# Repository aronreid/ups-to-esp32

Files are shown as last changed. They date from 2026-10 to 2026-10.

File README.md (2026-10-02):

# UPS to ESP32 Module Canadian flag





**Put a USB-only UPS on your network for the cost of a $6 board: no Pi, no SD card to
corrupt, no vendor network card that costs more than the UPS.**

Plug it into your UPS's USB port and it speaks the real Network UPS Tools protocol on
TCP 3493, so Home Assistant, Synology, TrueNAS, unraid and `upsmon` see a normal `upsd`
and connect exactly like they would to one, because it *is* one, not an approximation.

<p align="center">
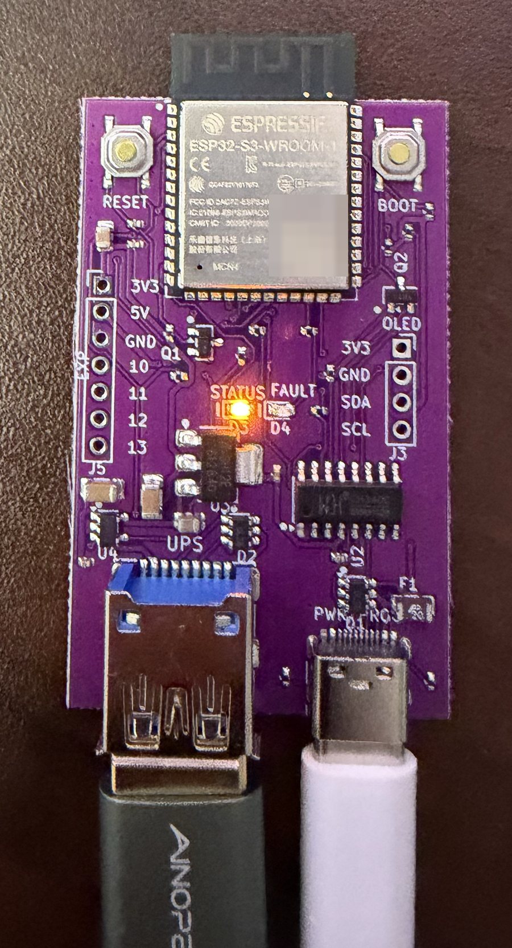
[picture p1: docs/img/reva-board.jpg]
A Rev A board, powered and running, with a UPS cable in its USB-A port
  
  &nbsp;&nbsp;
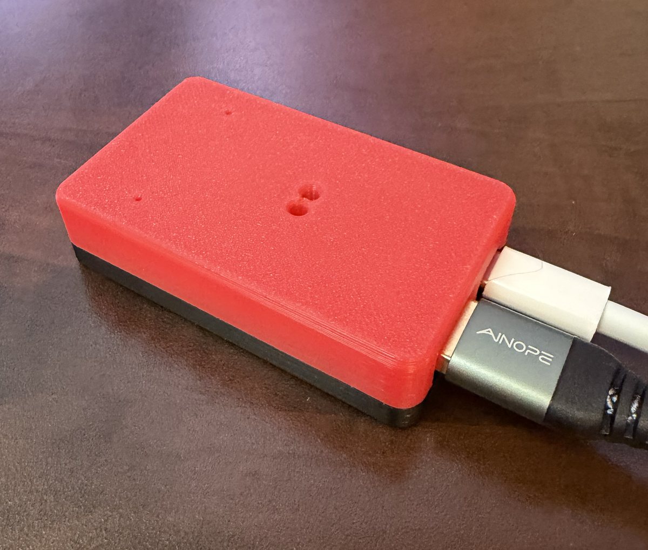
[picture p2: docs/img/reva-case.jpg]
The same board in its printed case
  
</p>

---

## The problem

A UPS in a rack, a basement or a cupboard has exactly one monitoring interface: a USB
type-B socket. The usual fix is a Raspberry Pi parked beside it running NUT: an entire
Linux computer, its own power draw, its own SD card to corrupt, to do nothing but
translate one protocol. Vendor network cards cost more than the UPS. Most small UPSes
can't take one at all.

This board is the translator, and nothing else. ~$6 in parts, no computer, no card.

---

## NUT-compatible

Speaks the real NUT network protocol on TCP 3493. A client can't tell it from `upsd`,
because there's nothing to tell apart. It reads whatever the UPS's own USB descriptor
reports (charge, runtime, voltage, load, standard status flags) and offers only the
commands that UPS actually has: self-test, beeper, shutdown. Never a button for
something the UPS can't do.

| Client | Configuration |
|---|---|
| **Home Assistant** | Add the built-in **NUT** integration. Usually discovered on its own; otherwise host `ups-esp32-XXXX.local`, port `3493`, UPS name `ups`, no credentials. |
| **Synology DSM** | Control Panel → Hardware & Power → UPS → *Network UPS server*, point at the board's address. |
| **TrueNAS / unraid** | UPS service in "slave"/network mode, same address and port. |
| **Linux** | `upsmon` / `upsc ups@ups-esp32-XXXX.local` |
| **Prometheus** | Scrape `http://ups-esp32-XXXX.local/metrics` directly, no exporter in between. Metric names follow `nut_exporter`, so its dashboards and alerts carry over. |

MQTT with Home Assistant discovery is planned as a secondary output; NUT is primary.

---

## The web UI

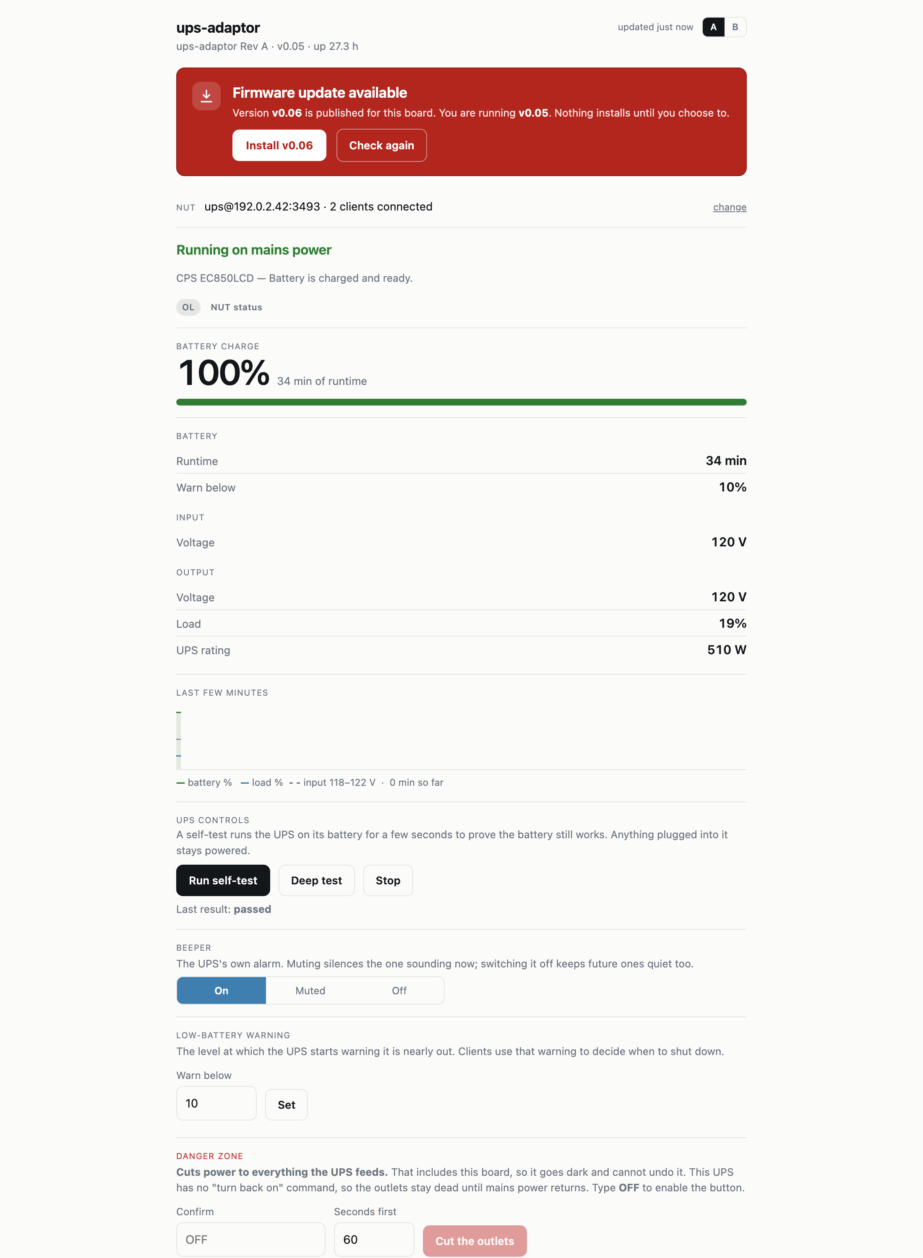
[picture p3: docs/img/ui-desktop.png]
the status page


Everything the UPS reports, in words rather than protocol vocabulary ("Running on mains
power", not `OL`), with the raw NUT status alongside it for anyone who wants it. The NUT
connection string sits at the top, ready to paste into a client. The controls underneath
are the ones *this* UPS actually implements, and the destructive one asks you to type
`OFF` before it will arm.

*Shown with sample data rather than a real installation.*

---

## What else you get

- **A web UI**: battery gauge, live readings, the UPS's own controls, and the NUT
  connection string ready to paste into a client.
- **Wi-Fi setup in a browser, no app.** First boot raises an access point with a
  captive portal; afterward it's at `ups-esp32-XXXX.local`.
- **Updates itself over the air, safely.** Nothing installs without a click, and a bad
  update rolls itself back automatically.
- **An optional OLED**: charge, runtime, volts and load at a glance, no browser needed.
  **On Rev A, read the warning under *The board* before fitting one.**
- **Recovers on its own** from a Wi-Fi drop or a UPS that stops answering. Nobody has
  to go babysit it.

Readings only ever come from what the UPS itself reports. A value it doesn't expose
shows up absent, never guessed at as zero.

---

## The board: Rev A

36 × 58 mm, two layers, ESP32-S3-WROOM-1-N4.

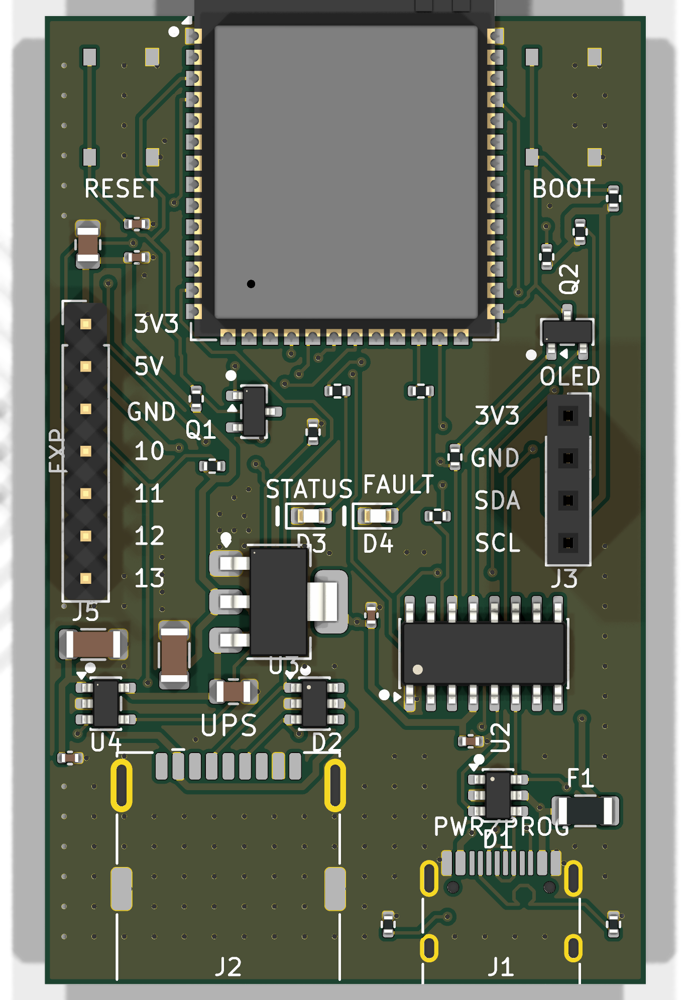
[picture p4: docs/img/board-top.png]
top view


- **USB-A host port** to the UPS, with switched, current-limited VBUS: a UPS's USB port
  supplies no power itself, so the board provides it
- **USB-C** for power, programming and console via a CH340C with auto-reset
- ESD protection on both ports, a 2 A resettable fuse
- Expansion header, and an I²C header for an optional 128×64 SSD1306 OLED
- Every part on the top side, because JLCPCB's Economic PCBA places one side only

The photos at the top are a real Rev A board, running, and the same board in its
printed case. The views here are renders of the design.

### The case

Printable, no supports, no screws needed to close it: the board drops into the tray, and
the cover snaps on and holds it down. STLs are in
[`hardware/enclosure/reva/`](hardware/enclosure/reva/). Rev A's case has no name label
to drop, so there is no `-noname` variant.

| File | What it is |
|---|---|
| `ups-adaptor-tray.stl` | the tray, for sitting on a shelf |
| `ups-adaptor-tray-wall.stl` | **wall-mount tray**: two countersunk holes for #6 / 3.5 mm flat-head wood screws, 23 mm apart on the centreline. Screw the empty tray to the wall, drop the board in, snap the cover on: the screws end up hidden inside |
| `ups-adaptor-cover.stl` | the cover, with light pipes over the LEDs and pinholes for RESET and BOOT |
| `ups-adaptor-lightpipes.stl` | two 3 mm light pipes for the plain STL covers above, printed in clear PETG and pressed into the light pipe guides |
| `ups-adaptor-cover-3color.3mf` | the plain cover as a three-colour Bambu Studio / Orca project: STATUS, FAULT, RESET and BOOT inlaid into the top in filament 2, and the light pipes printed straight into the case in filament 3, no rod to press in. Just a thin plug right inside each light pipe's chamfered opening, printed in the first layers against the bed; the guide tube stays open below it down to the LED, so it reads as a lit window rather than a full clear rod |
| `ups-adaptor-cover-blank.stl`, `ups-adaptor-cover-oled-blank.stl` | the same covers with no words at all |

There is also an OLED cover, with a window for a display on J3, but it isn't published here. The display is disabled in firmware on every board shipped so far (wired to the wrong pins), so there is nothing to fit it to yet.

Both trays carry "Contains FCC ID: 2AC7Z-ESPS3WROOM1" and "Contains IC: 21098-ESPS3WROOM1" engraved underneath: the Wi-Fi module's certification requires them on the outside of anything it is enclosed in. They are not a compliance claim for the board itself.

Either tray takes either cover. Print the cover upside down, as the STL is oriented; the labels are then the first layers, so a multi-colour print changes filament only there.

### Schematic

the schematic, click for the PDF

[PDF](docs/schematic.pdf) · [SVG](docs/img/schematic.svg) · KiCad source in
[`hardware/kicad/`](hardware/kicad/). Generated from the same netlist the board is built
from, so it cannot drift from the hardware; CI fails if it has changed without being
re-exported.

### With the optional display fitted

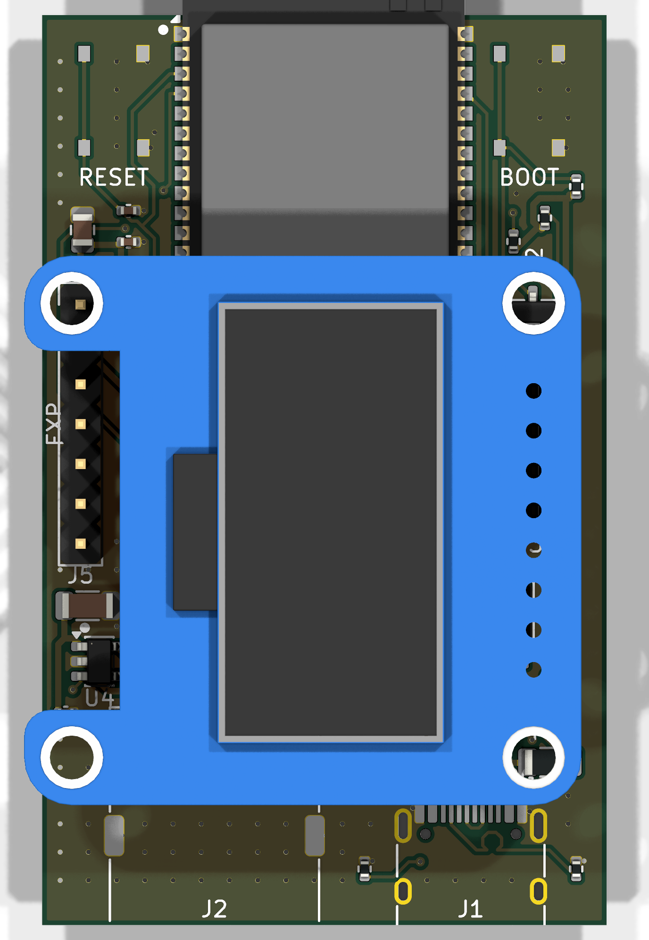
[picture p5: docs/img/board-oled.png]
the board with an OLED fitted


The I²C header is positioned so a 0.96" module sits **flat over the board** rather
than hanging off an edge. Illustrative: the 3D model is an Adafruit breakout standing
in for the generic modules most people buy.

> [!CAUTION]
> **Rev A: never plug a standard OLED module straight into J3. It will be destroyed.**
> J3 reads **3V3, GND, SDA, SCL** from pin 1 (the square pad). Nearly every 0.96" SSD1306
> module reads **GND, VCC, SCL, SDA**, so seated directly it gets 3V3 on its ground pin.
> The first module plugged into a Rev A board died this way.
>
> **To use a display on Rev A, do one of these:**
>
> 1. **Buy a VCC-first module**: 0.96", 4-pin I²C, SSD1306, with the pins labelled
>    **VCC, GND, SCL, SDA** in that order. Its power pins match J3, so it plugs straight in.
>    The DIYmalls 0.96" module is one; check the photo of the pin labels before ordering,
>    because listings reuse stock photos.
> 2. **Or cross the power pins on a standard module**: wire it with four jumpers:
>    module **VCC → J3 pin 1**, module **GND → J3 pin 2**, SCL → pin 3, SDA → pin 4.
>    Only the power pair crosses.
>
> Either way, flash the **`reva-oled`** build (`ups-adaptor-reva-oled-full.bin`
> for a first flash over USB, or let an already-flashed board update itself
> from then on): it swaps SDA and SCL for the display in software to match.
> The plain Rev A release leaves the display off, on purpose, because it
> cannot know which way round your module is wired. **Before first power,
> read the labels on the module in your hand and put VCC on J3's square pad.**

The board is **generated, not drawn.** The schematic, placement, routing, pours,
silkscreen and fab outputs all come from source, not a hand-edited `.kicad_pcb`.

---

## Getting started

**Flash a board**: download `ups-adaptor-<target>-full.bin` from
[Releases](../../releases) and write it to offset 0:

```sh
esptool.py --chip esp32s3 write_flash 0x0 ups-adaptor-reva-full.bin
```

**ESP32-P4 on PoE (test build).** A second target runs on the Waveshare
ESP32-P4-ETH development board, which is a bought board rather than ours. One
Ethernet cable from a PoE switch powers it and carries the network. It has no
Wi-Fi, so there is no setup step: it takes an address by DHCP and answers at
`http://ups-esp32-XXXX.local/`, with the same web page and NUT server. Download
`ups-adaptor-p4poe-full.bin` and write it to offset 0:

```sh
esptool.py --chip esp32p4 write_flash 0x0 ups-adaptor-p4poe-full.bin
```

It needs ESP32-P4 silicon v1.x, which is what these boards carry. The UPS
plugs into the board's small 4-pin USB header (1.25mm pitch, marked V, D-, D+,
G) through a cable to a USB-A socket. The USB-C port on the board is only the
serial port for flashing and cannot talk to a UPS. That header's 5V is always
on, so unlike Rev A this target cannot power-cycle the UPS's USB. It has been
run on the bench with no UPS attached so far, so treat it as a test build and
tell us what you see.

**Then, with no cable at all:** join the `ups-esp32-XXXX` access point, open
`http://192.168.4.1/`, pick your network. The board joins it while the setup page
is still open and shows you the address it was given, plus `http://ups-esp32-XXXX.local/`. To move it
to another network later, press BOOT five times within four seconds: it forgets the old
one and brings the setup access point back. Point a NUT client at port 3493, UPS name `ups`; reading needs no
credentials.

**A login is required.** Setup asks for a username and password with your Wi-Fi details,
and the page and every change need it, including UPS commands over NUT (`upscmd -u`).
Watching the UPS never does: Home Assistant, a NAS and Prometheus read it with no setup.
Forgot it? Type `clear-login` into the board's USB-C serial console (115200): that removes
only the login. Or press BOOT five times, which clears Wi-Fi and the login and starts it over
in setup. It is plain HTTP, so it keeps people out of the settings rather than encrypting
anything; see [docs/firmware.md](docs/firmware.md#the-login).

A **fixed address**, for a NAS or Home Assistant that points at the board's IP, can be set
in the setup page's "Fixed address (advanced)" or later on the board's Address card. The board
checks that your router answers from it; if not, it goes back to an automatic address until it
restarts and says so on its page, so a typo cannot lose it.

**Build the firmware from source**, ESP-IDF v5.4:

```sh
cd firmware && idf.py build
```

---

## Privacy

Private by design: your UPS's serial number, your Wi-Fi name and any address on your
network never leave the board, and the server never keeps your IP. A short check-in
(hardware ID, firmware version, uptime, why it last restarted) is on by default so the
board can be supported if something goes wrong. The page says so, and one click turns
it off. It never slows the board down: lowest priority, backs off if the server is
slow or unreachable, and behaves exactly the same either way.

**If your UPS doesn't work**, the board helps get it fixed. When a UPS is attached but the
board can't read it for five minutes, and the check-in is on, it sends that UPS's USB
report descriptor once: the description of how that model talks, plus its make, model and
USB ID. No readings, no serial number, nothing about your network. The web page also has a
"send my UPS info to the developer" button that sends the same thing whenever you press it,
even with the check-in off. Turn the check-in off and nothing is sent unprompted. For an APC
Smart-UPS whose voltages the board reads over Modbus, the button also sends a capture of
that Modbus conversation, which includes the UPS's readings; with stats ticked the board
sends one such capture by itself once per boot.

**Want to help with debugging further?** Anonymous stats are opt-in: tick the box and
it also shares the UPS's make/model, its readings, Wi-Fi signal and free memory, nothing
that identifies you. Untick it and what was kept gets deleted. The database side is
[`telemetry/supabase.sql`](telemetry/supabase.sql), so you can see exactly what's stored.

## Documentation

| | |
|---|---|
| [`docs/tested-ups.md`](docs/tested-ups.md) | which UPSes are tested on hardware, which are checked against their real descriptors, and which cannot work |
| [`docs/firmware.md`](docs/firmware.md) | architecture, HID-to-NUT mapping, the protocol subset, OTA |
| [`docs/hardware.md`](docs/hardware.md) | board specification, pin map, power tree |
| [`docs/schematic.pdf`](docs/schematic.pdf) | the schematic, for reading without KiCad |
| [`docs/hardware-schematic.md`](docs/hardware-schematic.md) | every net and pin, as built |
| [`docs/circuit.md`](docs/circuit.md) | the one-page circuit description |
| [`docs/BOM.md`](docs/BOM.md) | parts, with the substitutions that would destroy the board |
| [`docs/datasheet-audit.md`](docs/datasheet-audit.md) | every part checked against its datasheet, and what that found |
| [`docs/jlcpcb.md`](docs/jlcpcb.md) | manufacturing limits, and what to check before ordering |
| [`docs/reva-readiness.md`](docs/reva-readiness.md) | every way the real board differs from the development one, and the bring-up order |
| [`docs/RELEASING.md`](docs/RELEASING.md) | the rules for shipping firmware, and what each one cost to learn |
| [`docs/CHANGELOG.md`](docs/CHANGELOG.md) | what changed, written as it happens rather than reconstructed at release time |
| [`docs/TOOLCHAIN.md`](docs/TOOLCHAIN.md) | what to install, and the traps |

---

## What's built

Rev A boards are built, running, and reading real UPSes today.

- USB HID Power Device polling, generic across manufacturers
- NUT server on TCP 3493
- Prometheus `/metrics`
- Web UI with live readings and the UPS's own controls
- Wi-Fi setup in a browser, no app
- OTA firmware updates, with automatic rollback
- Optional OLED display

---

## Licence

**Firmware and tools: GPL-3.0-or-later** ([`LICENSE`](LICENSE)); every source file
carries an SPDX header. Copyleft on purpose: it keeps derivatives open, and it is what
allows reusing logic from NUT, whose `usbhid-ups` is GPL-2.0-or-later.

**Hardware: CERN-OHL-S v2** ([`hardware/LICENSE`](hardware/LICENSE)). Make and sell the
board freely; publish your sources if you distribute a modified version.

One third-party file is redistributed: `tools/test/jlc_cpl_rotations.csv`, a verbatim
copy of the reel-rotation table from
[JLCKicadTools](https://github.com/matthewlai/JLCKicadTools), GPL-3.0-or-later, with its
provenance in the file's own header.

## How this was built

The idea and the direction are the author's, who also designed and routed key parts of
the board by hand. [Claude Code](https://claude.com/claude-code) helped finish the
hardware and wrote most of the firmware, tooling and docs, working against real hardware
and reviewed as it went.

---

<p align="center">&nbsp; <b>Designed in Canada</b></p>

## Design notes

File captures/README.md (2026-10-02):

# Reference captures

A real UPS's USB HID report descriptor, decoded, with the NUT variable mapping
derived from it. Kept because the firmware's parser is tested against it (see
`tools/test/test_parser.py` and `tools/test/test_descriptor.py`), and because a
worked example of a Power Device descriptor is hard to come by.

| File | What it is |
|---|---|
| `report-descriptor.bin` | the descriptor exactly as the device returns it |
| `report-descriptor.hex` | the same bytes, annotated |
| `decoded.txt` | every field: report ID, bit offset, width, units, scaling |
| `usages.txt` | the HID usages present, by page |
| `SUMMARY.txt` | what the unit is and what it reports |

The device is an APC Back-UPS RS 1000G, USB `051d:0002`. Its serial number is
replaced with `REDACTED-SERIAL`; it identified one specific unit and proved
nothing the VID, PID and model string do not.

Host-side `ioreg` and `system_profiler` dumps are deliberately not committed:
they carry the capturing machine's own serial numbers and account details.
`tools/capture-ups.sh` writes them locally and `.gitignore` keeps them there.

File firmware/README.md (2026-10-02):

# Firmware

ESP-IDF v5.x. See `../docs/firmware.md` for architecture.

## Build

```sh
. $IDF_PATH/export.sh
cd firmware
idf.py set-target esp32s3
idf.py build
```

Rev A is the only target. Application code contains no GPIO numbers -- the pin
map lives in `components/board` -- so a future revision is a new block there.

## Flash

Over the board's USB-C port. The CH340C's auto-reset enters the bootloader by
itself, so no button is needed:

```sh
idf.py -p /dev/cu.wchusbserial-XXXX flash monitor
```

After first flash, configuration is via the web UI — connect to the
`ups-esp32-XXXX` SoftAP and open `http://192.168.4.1/`.

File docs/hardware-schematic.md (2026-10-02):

# Rev A schematic specification

Everything needed to draw the Rev A schematic in KiCad without making design
decisions at the keyboard. Nets are named; connections are given by **pin
function name**, not module pin number, because that is how KiCad symbols are
wired and because transcribing pin numbers from memory is how boards get built
wrong. Physical pin numbers are verified once, against datasheets, using the
checklist at the end.

Companion to `hardware.md`, which holds the BOM, costing and layout constraints.

---

## 1. Load switch: AP2171W, with FLAG

**Superseded decision, recorded because the reasoning matters at order time.**

A SOT-23-5 load switch has room for `IN`, `OUT`, `GND`, `EN` and **exactly one**
of `ILIM` or `FLAG`. That was first worked out as an argument about the
SY6280AAC; it is confirmed by the AP2171W, whose verified pinout is
1=`OUT`, 2=`GND`, 3=`FLG`, 4=`EN`, 5=`IN`: FLAG, no ILIM.

Rev A now uses the **AP2171W**, for a blunt reason: it has a KiCad symbol with a
verified pinout, and the SY6280AAC does not. Inventing a pinout for a part that
goes to fabrication is not a risk worth taking to save a few cents. Fault
reporting comes back on GPIO5 as a result, and firmware carries
`BOARD_HAS_VBUS_FAULT 1` again.

**Checked against the datasheet.** The AP2171W limits at **1.5 A typical** (the datasheet's
figure; a distributor listing saying 1.0 A is the *recommended continuous load*,
not the limit). The polyfuse was raised from 500 mA to **2 A hold** so the switch
limits first and the bridge survives a shorted UPS: the whole point of having a
switch. That leaves only 5% margin over the 1.9 A fault case, which is tolerable
rather than comfortable: into a dead short the AP2171W dissipates ~7 W in a
SOT-23-5 and thermally duty-cycles within milliseconds, so the *average* fault
current sits far below the limit, and a polyfuse needs seconds above hold to
trip. `tools/test/test_power.py` asserts the relationship.

### The original argument, for the record

`hardware.md` assigns both an `ILIM` resistor and a `FLAG` output to an
SY6280AAC in SOT-23-5. A 5-pin package cannot carry six functions: `IN`, `OUT`,
`GND`, `EN`, `ILIM` and `FLAG`. One of them does not exist on the part. This
holds regardless of the exact pinout, so it needs settling before the schematic
is drawn.

Three ways out:

| Option | Keeps | Loses | Cost |
|---|---|---|---|
| **A. Keep SY6280AAC, drop FLAG** | adjustable current limit | fault reporting; GPIO5 freed | no change |
| **B. Keep SY6280AAC, drop ILIM** | fault reporting | trip point fixed by the part | no change |
| **C. Move to a SOT-23-6 switch** | both | none | +$0.02, new LCSC part |

**Recommendation: A.** Firmware already detects a wedged UPS by counting failed
polls and power-cycles VBUS on that basis: `ups_hid.c` does not need `FLAG` to
do its job. An overcurrent event is self-protecting because the switch limits
current whether or not anything is listening. Losing the fault line costs a
diagnostic nicety; losing a correct trip point risks nuisance tripping on the
UPS's inrush.

The firmware change was one line, `BOARD_HAS_VBUS_FAULT 0` for Rev A.
`board_vbus_fault` already returned false on boards without the line, so the
web UI and status LEDs needed no change.

The accepted cost: a genuine overcurrent is indistinguishable from a wedged UPS
interface. Both look like failed polls and both get a VBUS power-cycle.

**Option A was taken.** GPIO5 is left unconnected and brought to the expansion
pads, and firmware already carries `BOARD_HAS_VBUS_FAULT 0` for Rev A.

---

## 2. Decisions resolved

Closing out `hardware.md`'s open questions:

| # | Question | Decision |
|---|---|---|
| 1 | USB-C / USB-A LCSC codes | **Chosen and stock-checked :** `C165948` and `C2880618`. Re-check stock at order time. |
| 2 | USB-A vertical or right-angle | **Right-angle.** A UPS is floor- or wall-adjacent; this wants to sit flat. |
| 3 | ~~SY6280 ILIM value~~ | **Moot.** The AP2171W has no ILIM; its limit is fixed at 1.5 A, and the polyfuse was raised to 2 A to suit. |
| 4 | OLED pull-ups with no module fitted | **Safe.** Two 4.7k to 3V3 idle high, drawing ~1.4mA total when a module is absent. One board build covers both cases. |
| 5 | 2-pin 5V input header | **Dropped.** J5 pins 2 and 3 already carry 5 V and GND, and a bare header paralleling USB-C VBUS with no ORing diode lets one 5 V supply be pushed into another. |
| 6 | Reverse-polarity / backfeed Schottky | **Omit.** A series Schottky costs 0.3–0.4 V off the 5 V rail. The AP2171W has **reverse current blocking** built in, which settles the backfeed question the original note deferred. |

---

## 3. Net list

31 nets, of which these carry the design. `GND` is a plane on both layers.

| Net | Members |
|---|---|
| `5V_RAW` | USB-C `VBUS` (all VBUS pins tied); 2-pin header pin 1; polyfuse pin A |
| `+5V` | polyfuse pin B; AP2114H `VIN`; AP2171W `IN`; C4 22µF |
| `+3V3` | AP2114H `VOUT` + tab; module `3V3`; CH340C `VCC` **and `V3`** (see §5); OLED header `VCC`; R3, R4, R5, R6, R12 pull-ups; C2 100µF, C5 22µF, C3/C6/C9 100nF |
| `VBUS_A` | AP2171W `OUT`; USB-A `VBUS`; USBLC6_A `VBUS`; C7 100µF + C8 100nF |
| `USB_DM` | module `IO19`; USBLC6_A `I/O1`; USB-A `D-` |
| `USB_DP` | module `IO20`; USBLC6_A `I/O2`; USB-A `D+` |
| `UART_TX` | module `TXD0` (IO43); CH340C `RXD` |
| `UART_RX` | module `RXD0` (IO44); CH340C `TXD` |
| `PROG_DM` | USB-C `D-` (both pairs tied); USBLC6_C `I/O1`; CH340C `UD-` |
| `PROG_DP` | USB-C `D+` (both pairs tied); USBLC6_C `I/O2`; CH340C `UD+` |
| `EN` | module `EN`; R_EN_PU to 3V3; C_EN 1µF to GND; SW_RESET to GND; Q1 collector |
| `IO0` | module `IO0`; R_IO0_PU to 3V3; SW_BOOT to GND; Q2 collector |
| `DTR` | CH340C `DTR#`; R_Q1B to Q1 base; Q2 emitter |
| `RTS` | CH340C `RTS#`; R_Q2B to Q2 base; Q1 emitter |
| `VBUS_EN` | module `IO4`; AP2171W `EN`; R11 100k **pull-down**, the switch must be off before firmware runs |
| `VBUS_FAULT` | module `IO5`; AP2171W `FLG` (open drain, active low); R12 10k pull-up to `+3V3` |
| `SDA` | module `IO8`; OLED header `SDA`; R_SDA_PU to 3V3 |
| `SCL` | module `IO9`; OLED header `SCL`; R_SCL_PU to 3V3 |
| `LED_STAT` | module `IO48`; R7 1k to D3 **yellow** anode (see §5 for why not green) |
| `LED_FAULT` | module `IO47`; R8 1k to D4 red anode |
| `EXP_IO10`–`EXP_IO13` | module `IO10`–`IO13`; J5 expansion header pins 4–7 |

`CC1` and `CC2` each get their own 5.1k to GND and go nowhere else. They are
what make the connector a sink; without them no charger supplies 5V.

---

## 4. Power tree

```
USB-C VBUS ── polyfuse 2A hold ──┬── AP2114H-3.3 ── 3V3 ── module, CH340C,
 │ OLED, LEDs
 └── AP2171W ── VBUS_A ── USB-A ── UPS
 EN ← IO4 (active high, pulled down)
 FLG → IO5 (open drain, pulled up)
```

The 2-pin 5 V input header was **dropped**: J5 pins 2 and 3 already carry 5 V and
GND, and a bare header paralleling USB-C VBUS with no ORing diode lets one 5 V
supply be pushed into another.

Worst case on `5V` is ~500mA: S3 ~350mA transmit peak, CH340C ~20mA, OLED ~20mA
when fitted, LEDs ~10mA, UPS interface <100mA.

---

## 5. Per-part connections

### ESP32-S3-WROOM-1-N4

Pin numbers verified against KiCad's `RF_Module:ESP32-S3-WROOM-1` symbol (41
pins), which is the symbol the schematic uses.

| Pin | Symbol name | Net | Notes |
|---|---|---|---|
| 1, 40, 41 | `GND` | `GND` | all three, plus the footprint's thermal pad, multiple vias |
| 2 | `3V3` | `3V3` | 100µF bulk **physically adjacent**, plus 100nF |
| 3 | `EN` | `EN` | 10k to 3V3, 1µF to GND, tact switch to GND |
| 4 | `IO4` | `VBUS_EN` | AP2171W EN, **active high**, 100k pull-down so VBUS is off at boot |
| 5 | `IO5` | `VBUS_FAULT` | AP2171W FLG, open drain active low, 10k pull-up |
| 12 | `IO8` | `SDA` | 4.7k pull-up |
| 13 | `USB_D-` (IO19) | `USB_DM` | fixed by silicon |
| 14 | `USB_D+` (IO20) | `USB_DP` | fixed by silicon |
| 15 | `IO3` | n/a | **leave unconnected**, strapping |
| 16 | `IO46` | n/a | **leave unconnected**, strapping |
| 17 | `IO9` | `SCL` | 4.7k pull-up |
| 24 | `IO47` | `LED_FAULT` | 1k series, red |
| 25 | `IO48` | `LED_STAT` | 1k series, yellow |
| 26 | `IO45` | n/a | **leave unconnected**, strapping |
| 27 | `IO0` | `IO0` | 10k to 3V3, tact switch to GND, strapping |
| 18–21 | `IO10`–`IO13` | `EXP_IO10`–`13` | J5 expansion header |
| 28–31 | `IO35`–`IO38` | unconnected | free only because the N4 has no PSRAM |
| 36 | `RXD0` (IO44) | `UART_RX` | from CH340C TXD |
| 37 | `TXD0` (IO43) | `UART_TX` | to CH340C RXD |

Note the symbol exposes IO19/IO20 as `USB_D-`/`USB_D+`. `IO26`–`IO32` are not
brought out by the module; the SPI flash consumes them.

`IO26`–`IO32` are consumed by the module's SPI flash and are not brought out.

### CH340C (SOP-16)

Verified against KiCad's `Interface_USB:CH340C` symbol.

| Pin | Name | Net |
|---|---|---|
| 1 | `GND` | `GND` |
| 2 | `TXD` | `UART_RX` |
| 3 | `RXD` | `UART_TX` |
| 4 | `V3` | **`3V3`** (see note) |
| 5 | `UD+` | `PROG_DP` |
| 6 | `UD-` | `PROG_DM` |
| 7, 8 | `NC` | unconnected: confirms the **C** variant's internal crystal |
| 13 | `~DTR` | `DTR` |
| 14 | `~RTS` | `RTS` |
| 16 | `VCC` | `3V3` |
| 9–12, 15 | `~CTS`, `~DSR`, `~RI`, `~DCD`, `R232` | unconnected |

The symbol types `V3` as a power **output**, which is the 5V-operation case
where it sources 3.3V. At 3.3V operation it is an input and ties to `VCC`.

**The `V3` pin is a classic failure.** It behaves differently by supply voltage:
tie `V3` to `VCC` when running the part at 3.3V, or decouple it with 100nF to
GND when running at 5V. This design runs the CH340C at **3.3V**, so `V3` ties to
`3V3`. That also means `TXD`/`RXD` are 3.3V logic and need no level shifting to
the S3, which is why the part is on the 3.3V rail in the first place.

Note `TXD`/`RXD` cross: the CH340C's TXD drives the module's RXD0.

### Auto-reset (2 × MMBT3904, esptool-compatible)

Verified against KiCad's `Transistor_BJT:MMBT3904` (parent `Q_NPN_BEC`):
**pin 1 = B, pin 2 = E, pin 3 = C.**

| Transistor | Base (1) | Emitter (2) | Collector (3) |
|---|---|---|---|
| Q1 | `DTR` via 1k | `RTS` | `EN` |
| Q2 | `RTS` via 1k | `DTR` | `IO0` |

The cross-coupled emitters are the whole trick: both transistors stay off when
DTR and RTS are at the same level, so a normal serial session never resets the
board. Only the opposing-level sequence esptool drives pulls `EN` or `IO0` low.

### AP2114H-3.3 (SOT-223)

Verified against the Diodes AP2114 datasheet pin table: the **H** package is
**1 = GND, 2 = VOUT, 3 = VIN**, tab = `VOUT`. The schematic uses KiCad's generic
`Regulator_Linear:AP1117-33` symbol, which has identical pin numbering; the
*value* is what reaches the BOM. Give the tab ≥100mm² of pour, and note the pour
is on the *output* rail.

**Order the H, never the HA.** `AP2114HA` is the same SOT-223 with
**1 = VIN, 2 = GND, 3 = VOUT**: fitting it puts the input rail onto ground. Both
are stocked at LCSC. `tools/test/test_bom.py` pins `C150716`.

**Why not the AMS1117**, which this was until : same package, same
pinout, but 1200 mV of dropout against the AP2114H's 450 mV. USB may legally
deliver 4.75 V at the port and a thin metre of cable at half an amp costs another
200 mV, which left the AMS1117 with **10 mV** of headroom, on a part feeding a
chip that draws 350 mA bursts every time it transmits. That is the most reported
failure of AMS1117-powered ESP32 boards, and it presents as random resets that
look like a firmware bug. `tools/test/test_power.py` now checks this headroom.

| Pin | Name | Net |
|---|---|---|
| 1 | `GND` | `GND` |
| 2 | `VO` + tab | `3V3` |
| 3 | `VI` | `5V` |

### AP2171W (SOT-23-5)

Verified against KiCad's `Power_Management:AP2171W` and the Diodes datasheet:
**1 = OUT, 2 = GND, 3 = FLG, 4 = EN, 5 = IN.** No `ILIM`: the limit is fixed at
1.5 A typical by the part.

| Pin | Signal | Net |
|---|---|---|
| 1 | `OUT` | `VBUS_A` |
| 2 | `GND` | `GND` |
| 3 | `FLG` | `VBUS_FAULT`, open drain, **active low**, 10k pull-up to `+3V3` |
| 4 | `EN` | `VBUS_EN`, **active high**, 100k pull-down |
| 5 | `IN` | `+5V` |

**Order the AP217 1W, never the AP216 1W.** They share the package and the
pinout and differ *only* in enable polarity: AP2161 is active **low**, so with
R11 pulling `EN` to ground it would sit switched on at power-up, and
`board_vbus_set(true)` driving the pin high would turn VBUS **off**. The UPS
would never enumerate and the power-cycle recovery would run backwards. Both are
stocked at LCSC; `tools/test/test_bom.py` pins `C110466`.

### USBLC6-2SC6 ×2

One per connector, placed **on the connector side** of the pair, never the MCU
side. `VBUS` pin to that connector's 5V net, `GND` to ground, `I/O1`/`I/O2` in
series with D-/D+.

Verified against KiCad's `Power_Protection:USBLC6-2SC6` (parent `USBLC6-2P6`):
**1 = I/O1, 2 = GND, 3 = I/O2, 4 = I/O2, 5 = VBUS, 6 = I/O1.** Pins 1/6 are the
same line and 3/4 are the other, which is what lets the part sit in-line with
the pair without stubs: route in on 1, out on 6.

| Instance | I/O1 (1, 6) | I/O2 (3, 4) | VBUS (5) | GND (2) |
|---|---|---|---|---|
| USBLC6_C (USB-C) | `PROG_DM` | `PROG_DP` | `5V_RAW` | `GND` |
| USBLC6_A (USB-A) | `USB_DM` | `USB_DP` | `VBUS_A` | `GND` |

### Connectors

**USB-C 16P (sink):** all `VBUS` pins tied to `5V_RAW`; all `GND` tied; `D+`
pairs tied together, `D-` pairs tied together, to `PROG_DP`/`PROG_DM`; `CC1` and
`CC2` each 5.1k to GND; `SBU1`/`SBU2` unconnected; shield to `GND`.

**USB-A right-angle (host):** `VBUS` → `VBUS_A`, `D-` → `USB_DM`,
`D+` → `USB_DP`, `GND` → `GND`, shield to `GND`.

**OLED header, 4-pin 2.54mm:** `VCC` → `3V3`, `GND` → `GND`, `SDA`, `SCL`.
Through-hole. Economic PCBA fits these by hand ($3.50 labour plus $0.0173 a
joint), so it is a few cents on top of a once-per-order fee, not a blocker.

---

## 6. Decoupling

| Location | Parts |
|---|---|
| Module `3V3` | C5 22µF + C9 100nF, as close as the RESET button allows (~11mm) |
| Regulator in / out | C4 22µF in, C2 100µF out, + C3 100nF |
| `VBUS_A` | C7 **100µF** + C8 100nF, at the USB-A connector |
| CH340C `VCC` | 100nF |
| `EN` | 1µF to GND (with the 10k pull-up) |
| Each USBLC6 | 100nF on its VBUS pin |
| OLED header `VCC` | 100nF |

Bulk capacitance at the module's 3V3 pin is the single most important passive on
the board. Wi-Fi transmit bursts are why ESP32 designs brown out.

**Every capacitance here is a nominal that has to be derated before it means
anything.** Class-II ceramics lose capacitance under DC bias, worst near their
rating: C7's 100µF 6.3V part measures nearer 38µF on a 5V rail. Voltage ratings
are part of the value in the schematic for exactly this reason, and
`tools/test/test_power.py` derates before judging anything. See `BOM.md`.

---

## 7. Verify before ordering

**Pinouts, all verified, against primary datasheets as well as the symbols:**

- [x] **ESP32-S3-WROOM-1**: Espressif datasheet. Pin 36 is `RXD0`, 37 is `TXD0`; IO19/20 are `USB_D-`/`D+`.
- [x] **CH340C**: 3.3V operation with `V3` tied to `VCC` is the datasheet's own instruction. Draws 4–12mA.
- [x] **USBLC6-2SC6**: standoff 5.25V, breakdown 6.1V. 5.25V is exactly USB's maximum, which is the point of the part.
- [x] **AP2114H-3.3**: Diodes datasheet pin table. H package, tab is `VOUT`. **Not HA.**
- [x] **AP2171W**: Diodes datasheet. 1=OUT, 2=GND, 3=FLG, 4=EN, 5=IN, enable **active high**. **Not AP2161W.**
- [x] **MMBT3904**: 1=B, 2=E, 3=C. Cross-coupled emitters give the esptool truth table.
- [x] **Connector pinouts**: `tools/test/test_connectors.py` checks J1 and J2 against the USB spec on every build, including that CC1 and CC2 stay separate nets.

Electrical suitability was audited separately. Pinout is not the same question,
and the AMS1117's dropout proved it. See **`docs/datasheet-audit.md`**.

**Still needs a human with a browser:**

- [ ] **CPL rotation** against JLC's assembly preview. `tools/test/check_cpl_rotation.py` lists the placements in package families where KiCad and JLC disagree; the preview is the only authority.
- [ ] **D1–D4 polarity** against the render. Each carries a pin-1 dot on silk (pin 1 is the cathode); the stock footprint marks are kept as well.
- [ ] **Basic vs Extended** per BOM line: JLC charges ~$3 per unique extended part per order.

Ordered connectors, stock checked :

| Part | Chosen | LCSC |
|---|---|---|
| USB-C 16P sink | HRO TYPE-C-31-M-12 | `C165948` |
| USB-A right-angle | XKB U231-091N-4BLRA00-S (USB 3.0 9P, used as 2.0, the smallest SMD A receptacle available) | `C2880618` |

## 8. ERC and DFM checks

Once drawn, these are mechanical:

```sh
bash tools/test/run-all.sh # 16 checks, ERC and netlist among them
```

The BOM is **not** exported from the schematic with `kicad-cli`. `tools/gen-bom.py`
derives `hardware/bom/bom.csv` and `cpl.csv` from the same table that generates
the schematic, on every build, because a hand-exported BOM sat stale here for
days and still named the AP2161W when it was finally read.

Expect ERC to flag the intentionally unconnected pins (`IO3`, `IO45`, `IO46`,
CH340C's unused modem lines, `SBU1`/`SBU2`). Mark them with no-connect flags
rather than suppressing the rule, so a genuinely forgotten net still shows up.

Before ordering, confirm against `hardware.md` §layout: antenna keepout with the
module at a board edge and no copper beneath it, D+/D- routed as tight matched
pairs over continuous ground, and ≥100mm² of copper on the regulator tab.
There are **no mounting holes**: the enclosure uses case clips, to keep the
board at 36 × 58 mm.

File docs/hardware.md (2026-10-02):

# UPS to ESP32 Module Rev A hardware specification

## Scope

Rev A is a single two-layer board, roughly 36 x 58mm, that does exactly one job: sit
between a USB-only UPS and a Wi-Fi network. It carries an ESP32-S3 module, one USB-A host
port with switched and current-limited VBUS, a single USB-C for power and programming, a
header for a 0.96" I2C OLED, and a single RGB status LED.

Deliberately out of scope for Rev A: onboard battery backup, a second UPS port, Ethernet,
wide-input DC, and an enclosure. Each was considered and deferred.

## Block diagram

```
 +-------------------------------------------+
 USB-C ---5V----> | polyfuse --+--> AP2114H-3.3 --> 3V3 rail |
 (power, | | | |
 prog, | +--> AP2171W ---------|-------+ |
 console) | (EN, FLAG to GPIO) | |
 | | | | |
 +--D+/D- ---> | USBLC6 --> CH340C --> UART0 (43/44) | | |
 | | | | |
 | ESP32-S3-WROOM-1-N8 | | |
 | | | | | |
 | GPIO8/9 | | GPIO19/20 | | |
 | | | | | |
 | OLED header USBLC6 VBUS | |
 | (I2C) | | | |
 +-----------------------------|------------|--+
 v v
 USB-A receptacle --> UPS
```

## Power tree

**The polyfuse is 2A hold, and the number is set by the load switch, not by
normal draw.** Normal worst case on the 5V rail is only about 500mA. What sizes
the fuse is the fault case: the AP2171W limits at a fixed 1A, and that 1A passes
through the fuse on top of the board's own 400mA, so a shorted UPS puts 1.4A
through it.

A fuse that holds below 1.4A trips on a UPS fault and takes down the whole
bridge. That is precisely what the load switch was fitted to prevent. 1.5A would give
only 7% margin, and hold derates with temperature in a warm closet. 2A gives 43%,
and still trips near 4A, well inside what a dead short on the 5V rail draws.

`tools/test/test_power.py` asserts that relationship directly, so changing either
the switch or the fuse without checking the other fails the harness.

USB-C VBUS enters through a 2A-hold polyfuse onto the 5V rail. That rail feeds two loads:

1. **AP2114H-3.3** producing the 3.3V logic rail for the S3 module, CH340C, OLED and
 plain status LEDs.
2. **AP2171W** load switch, whose output becomes VBUS on the USB-A host receptacle. Its
 output carries **100µF** (C7), which is bracketed on both sides and not a
 round number picked for comfort. Below about 90µF, hot-plugging a UPS whose
 USB interface has the 10µF the spec allows drags VBUS under the 4.4V a host
 must hold, purely by charge sharing: at the 22µF this board used to carry it
 collapses to 3.4V. Above about 180µF, charging that cap through the AP2171's
 0.6ms controlled rise exceeds the switch's own 1.5A limit, so it current-limits
 on its own output capacitor and flags a fault at every power-on. C7 is the
 same 100µF 1206 part as C2, so it costs no extra BOM line.
 `tools/test/test_power.py` asserts both bounds.

Worst-case 5V draw is roughly 500mA: the S3 peaks near 350mA during Wi-Fi transmit, the
CH340C draws about 20mA, the OLED about 20mA when fitted, the two status LEDs about 10mA
together, and the UPS interface under 100mA. Any 1A USB charger is ample.

The regulator dissipates about 0.2W average and will run 40 to 50°C. Acceptable for a
closet device. Give it a copper pour.

**Why not the AMS1117.** It was the AMS1117-3.3 until. Same package, same
pinout, but 1200mV of dropout against the AP2114H's 450mV; that is the difference
between working and not. USB may legally deliver 4.75V at the port; a thin metre of cable
at half an amp costs another 200mV; the polyfuse and trace take their share. That leaves
about 4.51V at the regulator, against the 4.50V an AMS1117 needs to hold 3.3V. Ten
millivolts. The ESP32-S3 draws 350mA bursts every time it transmits, and an LDO falling
out of regulation on those bursts is the most reported failure of AMS1117-powered ESP32
boards: it presents as random resets that look like a firmware bug. The AP2114H leaves
760mV on the same supply, is explicitly stable with ceramic output capacitors, and costs
$0.06 against $0.22. `tools/test/test_power.py` now checks this headroom.

Its one trade is input range: 6.0V recommended maximum against the AMS1117's 15V. That
costs nothing here, because the AP2171W load switch on the same 5V rail is already
limited to 6.5V.

The AP2171W's current limit is fixed at 1A: there is no ILIM resistor to set. A UPS USB
interface draws far less, so this is a fault limit rather than an operating one.

## Pin assignment

| Signal | GPIO | Notes |
|---|---|---|
| USB host D- | 19 | Fixed by silicon. To USB-A via USBLC6. |
| USB host D+ | 20 | Fixed by silicon. To USB-A via USBLC6. |
| UART0 TX | 43 | To CH340C RXD |
| UART0 RX | 44 | To CH340C TXD |
| BOOT | 0 | Strapping pin. Tact switch to GND, 10k pull-up. |
| RESET | EN | Tact switch to GND, 10k pull-up, 1µF to GND |
| I2C SDA (OLED) | 8 | 4.7k pull-up |
| I2C SCL (OLED) | 9 | 4.7k pull-up |
| Status LED (green) | 48 | Plain LED, 1k series, active high |
| Fault LED (red) | 47 | Plain LED, 1k series, active high |
| VBUS enable | 4 | AP2171W EN, active high, **100k pull-down to GND** |
| VBUS fault | 5 | AP2171W FLG, open drain, **10k pull-up to 3V3** |

Avoid GPIO26 through GPIO32, which the module's SPI flash consumes. GPIO3, GPIO45 and
GPIO46 are strapping pins and are left unconnected. GPIO33 through GPIO37 are free on the
N8 part because there is no octal PSRAM, and are brought out to a small expansion pad
field for future use.

The VBUS enable GPIO is the reliability feature of this board. CyberPower USB interfaces
occasionally stop responding and need their interface power cycled. Firmware should drop
EN for 2 seconds and re-enumerate rather than requiring someone to visit the closet.

## Bill of materials

Per board. LCSC codes marked verified were checked against JLCPCB's live library.

| Part | Package | LCSC | Qty | Unit | Ext | Verified |
|---|---|---|---|---|---|---|
| ESP32-S3-WROOM-1-N4 | module | C2913197 | 1 | $2.93 | $2.93 | **checked ** |
| CH340C USB-UART | SOP-16 | C84681 | 1 | $0.50 | $0.50 | **checked ** |
| AP2171WG-7 load switch (active-high EN) | SOT-23-5 | C110466 | 1 | $0.09 | $0.09 | **checked ** |
| USBLC6-2SC6 ESD array | SOT-23-6 | C7519 | 2 | $0.18 | $0.35 | **checked ** |
| AP2114H-3.3 LDO (450mV dropout) | SOT-223 | C150716 | 1 | $0.06 | $0.06 | **checked ** |
| USB-C receptacle 16P TYPE-C-31-M-12 | SMD | C165948 | 1 | $0.10 | $0.10 | **checked ** |
| USB-A receptacle, XKB U231-091N-4BLRA00-S | SMD | C2880618 | 1 | $0.14 | $0.14 | **checked ** |
| LED green + red | 0603 | basic lib | 2 | $0.01 | $0.02 | n/a |
| MMBT3904 NPN (auto-reset) | SOT-23 | C20526 | 2 | $0.01 | $0.02 | confirm |
| Tact switch, BOOT and RESET | SMD 3x4 | basic lib | 2 | $0.03 | $0.06 | n/a |
| Polyfuse 2A hold | 1206 | basic lib | 1 | $0.05 | $0.05 | n/a |
| Pin headers: 4-pin OLED, 7-pin expansion | 2.54 THT | basic lib | 2 | $0.03 | $0.06 | n/a |
| Caps: 100µF x2, 22µF x2, 1µF, 100nF x9 | mixed | basic lib | 15 | | $0.12 | n/a |
| Resistors: 5.1k x2, 10k x3, 4.7k x2, 1k x4, 100k | 0402 | basic lib | 12 | | $0.02 | n/a |
| **Board subtotal** | | | | | **~$6.00** | |
| 0.96" SSD1306 OLED module (**optional**) | | third party | 1 | $2.00 | $2.00 | |
| **Total parts per board, with OLED** | | | | | **$6.43** | |

**The OLED is an option, not a fitted part.** At $2.00 it is 31% of the BOM and
the most expensive single line item, more than the ESP32 module, so it is not
ordered by default and firmware does not require it.

What Rev A *does* carry is the $0.03 4-pin header and the footprint, always
populated -- **but a module seated in it as most people would seat it gets
destroyed.** J3 reads 3V3, GND, SDA, SCL from pin 1. Read that again: it is
not GND, VCC, SCL, SDA, which is what most 0.96" SSD1306 modules print on
their own silkscreen. Plug one straight in, trusting its own labels rather
than J3's, and its GND lands on the board's 3V3 rail and its VCC lands on
GND. The first Rev A board did exactly that and killed the module. **See
"OLED module compatibility" below before you plug anything into J3** -- this
is not a footnote, it is the difference between a working display and a dead
one.

Release firmware built for plain Rev A drives no display, on purpose: nothing
in that build can know which way round the module in hand is wired. The
`reva-oled` firmware target exists for the one safe case, a module labelled
VCC, GND, SCL, SDA rather than the standard order -- it swaps SDA and SCL in
firmware to match and both boards read the same nets, only the display's
socket differs, so this stays a plain Rev A board wired the ordinary way.
Boards built as plain Rev A cost **$4.43 in parts** and lose nothing a user
sees, because the web interface shows the same values.

Note on assembly: the 2.54mm header is through-hole. JLCPCB Economic PCBA does
assemble through-hole parts, but by hand, at $3.50 labour plus $0.0173 a joint.
Four joints costs cents on top of a fixed fee you pay once per order. Fit it
yourself or let them, but decide before ordering.

The screen's genuinely useful job is **showing the IP address**, which is how you
reach the web UI without hunting through a DHCP table. mDNS (`ups-esp32-XXXX.local`)
solves the same problem in firmware for free, so treat the two as alternatives
rather than both being necessary.

Do not hardcode LCSC codes for passives. Let the KiCad BOM export select current JLC
Basic library parts at order time. Basic parts are free to place; extended parts are not.

The two 5.1k resistors are the USB-C CC1 and CC2 pull-downs that make the connector a
sink. They are not optional.

**Prices above were inherited estimates and were wrong.** See
[`BOM.md`](BOM.md) for figures checked against live LCSC pages, the N8-to-N4
cost lever. The polyfuse/load-switch interaction it flagged is fixed below.

## Manufacturing and cost

JLCPCB Economic PCBA. Current fee structure: $8.18 setup, $1.53 stencil, $3.07 per unique
**extended** component charged once per order, and $0.0016 per solder joint.

This design has five extended parts: the ESP32 module, CH340C, AP2171W and both USB
connectors. That is $15.35, so fixed costs land near $25 per order regardless of quantity.
Joint count is approximately 165 per board.

The status LED is a plain 0603 pair rather than a WS2812B for exactly this reason. At
$3.07 per unique extended part per order, a $0.06 addressable LED really costs $3.13 on a
small run, while Basic-library LEDs are free to place. Two LEDs also drop the RMT driver
from the firmware, and the OLED and web UI already carry any status detail worth reading.

| | Qty 5 | Qty 10 | Qty 20 |
|---|---|---|---|
| PCB, 55x40mm two-layer | $2 | $5 | $10 |
| Assembly fixed costs | $25 | $25 | $25 |
| Components | $22 | $45 | $85 |
| Joints | $1 | $3 | $5 |
| Shipping to Canada (DHL) | $22 | $22 | $25 |
| **Total** | **$72** | **$100** | **$150** |
| **Per board, no OLED** | **~$14** | **~$10** | **~$7.50** |
| **Per board, plus a $2 OLED each** | **~$16** | **~$12** | **~$9.50** |

GST and possible brokerage apply on import to Canada.

The fixed costs do not amortise below about ten boards. At qty 5 this board is not cheaper
than five dev boards with soldered pigtails, it is simply better. Qty 10 is the sensible
first order.

## Layout constraints

**Antenna keepout is the dominant constraint.** The WROOM-1's PCB antenna must overhang
the board outline, with no copper on either layer beneath it and no ground pour, and
nothing metallic within roughly 15mm. This drives the board outline more than anything
else, and it is the mistake that produces a board working fine on the bench and badly
inside a closet near metal. Place the module at a board edge first, then lay out
everything else around it.

**USB routing.** Full speed at 12 Mbps does not require controlled impedance, but route
D+/D- as a tight pair, matched length, on the top layer, with continuous ground beneath
and no stubs. Place the USBLC6 arrays close to their respective connectors, on the
connector side of the pair, not the MCU side.

**Thermal.** Give the regulator's tab a copper pour of at least 100mm² with a few vias to
the bottom layer.

**Bulk capacitance.** Put the 100µF bulk cap physically close to the module's 3V3 pin.
The S3's Wi-Fi transmit bursts are the reason ESP32 designs brown out.

**Mechanical.** Four M3 mounting holes. Position the OLED header so a standard 0.96"
module sits flat over the board rather than hanging off an edge. Dimension the outline to
suit a 3D printed enclosure.

## OLED module compatibility

> ### Read this before you plug a module into J3.
>
> **J3's four pins, in order from pin 1, are 3V3, GND, SDA, SCL.**
>
> Look at your module. Most 0.96" SSD1306 modules on the market print their
> own pins in a different order, commonly `GND, VCC, SCL, SDA` or
> `VCC, GND, SCL, SDA`. J3 is a straight 1:1 socket: whatever pin 1 of your
> module lands on is J3 pin 1, 3V3. **If your module's pin 1 is its own GND,
> you are about to put 3V3 onto that module's ground and the module's supply
> pin onto the board's real ground.** That is not a "might not work" case,
> it is a "will get hot and die" case, and it has already happened to one
> board here.
>
> Read the four labels printed on your module, in the order they are printed,
> before you seat it. Compare them to the table below. If they do not read
> `3V3, GND, SDA, SCL`, do not seat the module directly:
>
> - **Module reads `GND, VCC, SCL, SDA`:** this is the common case, and it is
>   the one that kills a module if plugged in directly. Do not use plain Rev A
>   release firmware with this module seated in J3.
> - **Module reads `VCC, GND, SCL, SDA`:** this is the one case Rev A
>   supports, because its power pins then line up with J3's power pins in the
>   same order (3V3 then GND), only SDA and SCL are swapped. Build and flash
>   the **`reva-oled`** firmware target (`sdkconfig.defaults.reva-oled`), which
>   swaps SDA/SCL for the display in software so the module works as fitted.
>   Do not use plain Rev A firmware with this module either -- it will not
>   drive the display, though it will not damage anything.
> - **Anything else:** do not guess. Confirm the module's actual pinout (a
>   datasheet, or a continuity check against its connector) before wiring it
>   any other way.

Firmware drives an **SSD1306, 128x64, I2C**, at address **0x3C** and 400 kHz
(`components/display/display.c`). J3 brings the bus out in this order:

| J3 pin | Signal |
|---|---|
| 1 | 3V3 |
| 2 | GND |
| 3 | SDA |
| 4 | SCL |

**Check your module's pin order before plugging it in.** Cheap 0.96" modules
ship in at least two arrangements: `GND, VCC, SCL, SDA` and
`VCC, GND, SCL, SDA` are both common, and neither matches this header exactly.
Swapped SDA and SCL simply will not work; **reversed power usually destroys the
module**. Every J3 pin is named on the silkscreen so the order is readable on
the board itself, not only in this file -- but the silkscreen shows the
board's own pins, not your module's. Reading the board correctly and reading
your module correctly are two separate steps, and skipping the second one is
what destroyed the first module.

Two further traps:

- **1.3" modules are frequently SH1106, not SSD1306.** The controllers are
 similar but not identical: SH1106 has a 132-column RAM with the 128-pixel
 panel offset by 2, so an SSD1306 driver renders it shifted and wrapped. The
 firmware here is SSD1306-only.
- **Some modules are strapped for 0x3D**, usually by a jumper or a resistor on
 the back. `display.c` probes 0x3C and logs a warning rather than hanging if
 nothing answers, so a wrong address looks like an absent display.

If a particular module is chosen, J3's order can be changed to match it so the
module plugs straight in: the header is a generated part of the schematic and
costs nothing to re-order before fab.

### J3 is a female socket, and sits low on purpose

These modules ship with **male pins**, pre-soldered or loose in the bag, so the
board carries a **socket**: `PinSocket_1x04_P2.54mm_Vertical`. The land pattern
is identical to a male header, so this cost nothing. J5 stays a male header,
because jumper wires have female ends.

The module is nearly as large as the board (roughly 27 × 28 mm against 36 × 46)
and extends perpendicular to the socket, centred on it. **With J3 at its original
y=11.8 the module overhung the top edge by 2.1 mm**, putting a copper-backed PCB
inside the antenna's exclusion zone. J3 is therefore anchored at y=24, where the
module lands wholly on the board and stops about 10 mm short of that edge.

Even so: take the display off before the board goes where Wi-Fi range matters. A
27 mm slab of PCB 8.5 mm above a 2.4 GHz antenna is never an improvement.

## No separate 5V input header

An earlier revision carried a 2-pin header in parallel with USB-C VBUS, so the
board could be fed from a screw terminal inside an enclosure. It has been
removed.

The capability was never lost: **J5 pins 2 and 3 are 5V and GND**, so an
enclosure can be wired from the expansion header instead. What the extra part
added was 22 mm² on a board whose size is already set by its connectors, and a
way to damage a charger: two 5V sources in parallel with no ORing diode means
powering the header while USB-C is plugged in pushes one supply into the other.

## Mechanical

**Board is 36 x 58 mm, retained by the enclosure, with no mounting holes.**

Two M3 holes need roughly 6 mm each once annulus and clearance are counted, and
on a board whose width is already set by the connectors that is several
millimetres bought for nothing. This board is light and has no moving parts, so
the enclosure holds it by its edges instead -- a slot or clip on each long side,
or a lid that presses it onto short standoffs.

What that asks of the enclosure design:

- **The outline is the mechanical interface.** Keep the board rectangular and
 hold the fab tolerance in mind; a printed case wants roughly 0.3 mm of slop per
 side, not a press fit.
- **Both USB connectors are on the same edge**, so one wall carries both
 openings. That was deliberate: it keeps them away from the antenna and means
 only one face needs cutouts.
- **The antenna end overhangs the board.** Nothing metallic within ~15 mm of it,
 which includes screws, threaded inserts and any metal clip. Keep that end of
 the case plastic and empty.
- **The expansion header sits on the left edge** so a case can expose it without
 cutting near the antenna or the connectors.

If clips prove unreliable in practice, two M3 holes cost about 4 mm of width.
That is the fallback, not the starting point.

### Why the board is this size

The width is set by the connectors, not the module. The right-angle USB-A
courtyard is 15.5 mm wide by 15.3 mm deep and USB-C is 10.6 by 9.4 mm, so both on
one edge need about 30 mm before margins. The module needs only 19 mm of board for its pads -- the rest of
its 33.5 mm courtyard is antenna keepout, which is open air.

**The length is set by routing, not by parts.** An earlier 36 x 46 version fitted
every component and could not be routed: placement used 0.3 mm of clearance
between courtyards, which is enough for parts not to touch and nothing else. A
0.25 mm track needs its own width plus clearance either side to pass between two
parts, so there were no channels at all and the autorouter was threading around
a solid block. At a routing-friendly 1.2 mm the same parts do not fit on 46 mm --
the placer fails on U3 at both 46 and 50 mm. 58 mm places everything at 61%
top-side utilisation, and the nets that would not route before now route.

At 2088 mm² this is still marginally smaller than the 55 x 40 = 2200 mm² of the
original specification. The dramatic shrink was never available; it was an
artifact of packing the parts too tightly to wire them together.

**The USB-A is the smallest surface-mount one available, and that is settled.**
The XKB part (`C2880618`) is a USB **3.0** 9-contact Type-A. That is deliberate,
or at least it is now: pins 1-4 are the standard USB 2.0 contacts in the standard
positions, wired here as VBUS / D- / D+ / GND, and the five SuperSpeed pads are
left unconnected. A USB 3.0 A receptacle is backward compatible by design and
this board runs full speed at 12 Mbps.

Every USB-A footprint in the KiCad library was measured by courtyard:

| Footprint | Courtyard | Area | Mount |
|---|---|---|---|
| Molex 105057 **vertical** | 16.04 x 7.69 | **123 mm2** | THT |
| Wuerth 614004134726 | 20.68 x 8.60 | 178 mm2 | THT |
| **XKB U231-091N (fitted)** | 15.50 x 15.30 | **237 mm2** | **SMD** |
| GCT USB1046 | 15.50 x 16.48 | 255 mm2 | SMD |
| TE 292303-7 | 17.16 x 16.46 | 282 mm2 | SMD |
| Connfly DS1098 | 22.20 x 14.10 | 313 mm2 | SMD |
| Molex 48037-2200 | 22.36 x 14.00 | 313 mm2 | SMD |
| CNCTech 1001-011-01101 | 22.80 x 14.30 | 326 mm2 | SMD |

**The XKB is the smallest SMD option.** Every USB 2.0 surface-mount alternative
is 8% to 38% larger. An earlier note here reasoned that the 15.3 mm depth was a
USB 3.0 penalty and that a 2.0 part would shrink the board. That was wrong:
footprint size is set by the USB-A plug cavity, which is identical for 2.0 and
3.0 -- the extra contacts sit deeper inside the same shell. Nine contacts cost
nothing here.

On price, Jing Extension `903-242B2023S10210` (`C2763376`) is USB 2.0, SMD,
right-angle, 1,760 in stock at **$0.115** against the XKB's $0.14. It saves
**$0.025 a board**, 0.5% of the BOM, and has no KiCad footprint -- so taking it
means hand-drawing the land pattern for the one part where a footprint error is
a dead board. Not worth it. Molex 48037-2200 has a library footprint and stock
but costs $0.749, 6.5x, which fails the low-cost rule outright.

**The only real size lever left is going vertical** -- Molex 105057 at 123 mm2,
nearly half the area. It is through-hole, and vertical means the UPS cable points
up off the board face instead of out the edge, which is an enclosure decision
rather than a layout one. Not taken.

Economic PCBA does fit through-hole parts, by hand, at $3.50 labour plus $0.0173
a joint -- so a through-hole receptacle would be assembled at extra cost, not
refused. (An earlier note here said Economic PCBA was surface-mount only. That
was wrong: JLC's assembly capabilities page lists THT under both Economic and
Standard.)

## Open questions for Rev A

All resolved in [`hardware-schematic.md`](hardware-schematic.md) except one,
which is a genuine design conflict and needs a decision:

**Resolved: the load switch is an AP2171W, and it keeps `FLAG`, not `ILIM`.**
The SY6280AAC this project started with had no KiCad symbol and an unverified
pinout, which is not something to invent for a part that switches power. The
AP2171W has a verified symbol, a fixed 1 A limit instead of an adjustable one,
and an open-drain `FLG`. So `ILIM` is what was lost, not `FLAG`. An earlier
version of this note said the opposite and was wrong.

GPIO5 therefore carries `VBUS_FAULT`, not an expansion pad, and firmware builds
with `BOARD_HAS_VBUS_FAULT 1`. `board_vbus_fault` reads it active low, which
matches the datasheet: the flag is an open drain pulled low on over-current or
over-temperature, with a 7 ms deglitch, and R12 pulls it up to 3V3.

**The part is AP21*7*1W, not AP21*6*1W, and the digit is the whole feature.**
Both are the same package with the same pinout; the only difference is enable
polarity. AP2161 is active LOW. With R11 pulling `EN` to ground, an AP2161 would
sit switched ON from power-up, and `board_vbus_set(true)` driving the pin high
to turn VBUS on would turn it OFF: the UPS would never enumerate, and the
power-cycle recovery feature would invert. AP2171 is active HIGH, which is what
R11's pull-down and the firmware both already assume. `tools/test/test_power.py`
now asserts this rather than leaving it to a BOM line.

Resolved:

| Question | Decision |
|---|---|
| USB-A vertical or right-angle | Right-angle, for a flat wall-mount enclosure |
| OLED pull-ups with no module | Safe; one board build covers both cases |
| 2-pin 5V input header | **Dropped.** J5 pins 2 and 3 already carry 5V and GND, and a bare header paralleling USB-C VBUS with no ORing diode lets one 5V supply be pushed into another |
| Backfeed Schottky | Omitted; costs 0.3–0.4V of LDO headroom for no clear gain |
| USB-C / USB-A LCSC codes | Candidates listed; must be confirmed against live JLC stock at order time |
| ~~SY6280 ILIM value~~ | Moot: the AP2171W's limit is fixed at 1A |

## Deferred, possibly to a future board

- Onboard LiPo, charger and boost, so the bridge does not consume a UPS outlet.
- A second USB-A host port behind a CH334 hub IC, for two UPSes on one bridge.
- Ethernet via an RMII PHY, for people who do not want another Wi-Fi client.
- **Move D3 and D4 out from under the OLED.** On Rev A, a display plugged into J3
 sits directly over both LEDs, so a board with the screen fitted has no
 visible LEDs, even through the case's light pipes. The firmware covers this
 by drawing the LED state on the screen (`docs/firmware.md`, *Status
 indication*), but the LEDs keep working when the display fails, comes loose or
 wedges its I2C bus, and then nothing on the board shows the state.
 Move them to the strip along the right-hand long edge, roughly u 33.5-35.5 mm
 and v 20-45 mm in board coordinates (X 133.5-135.5, Y 80-105 in the Rev A
 layout). No part's courtyard reaches past X 134.7 there, and the module's
 edge stops at about X 132.7. That puts the light pipes beside the display
 instead of under it, so one cover serves boards with and without a screen.
 Cost: rerouting the GPIO47/48 LED nets, and moving the two hold-down posts
 `tools/gen-case.py` puts on that edge.

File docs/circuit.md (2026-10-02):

# Rev A circuit

One page, the whole board. Exact pin numbers and passive values are in
[`hardware-schematic.md`](hardware-schematic.md); this is the shape of it.

## The whole board

```
 ┌──────────────┐
 │ USB-C │ power + programming + console
 │ (16P sink) │
 └──┬───┬────┬──┘
CC1,CC2│ │ │ D+/D-
 5.1k↓ 5V│ │
 GND │ └──────────┐
 │ │
 ┌────▼────┐ ┌────▼─────┐
 │ polyfuse│ │ USBLC6-C │ ESD
 │ 500mA │ └────┬─────┘
 └────┬────┘ │
 │ ┌────▼─────┐
 ══════╪══════ 5V │ CH340C │ USB <-> serial
 │ │ │ @ 3V3 │ V3 tied to VCC
 │ │ └──┬────┬──┘
 ┌────▼──┐ │ TXD │ │ DTR,RTS
 │AP2114H│ │ RXD │ │
 │ 3.3 │ │ │ ▼
 └───┬───┘ │ │ ┌──────────────┐
 │ │ │ │ Q1,Q2 MMBT3904│ auto-reset
 ═════╪═══ 3V3 │ └───┬───────┬──┘
 │ │ │ │ │ EN │ │ IO0
 │ │ │ │ │ │ │
 │ │ │ │ ┌──────▼──────▼───────▼──────┐
 │ │ │ │ │ │
 │ │ │ └────┤ ESP32-S3-WROOM-1-N8 │
 │ │ │ │ │
 │ │ │ │ IO43/44 UART0 -> CH340C │
 │ │ │ │ IO19/20 USB host │
 │ │ │ │ IO4 VBUS enable │
 │ │ │ │ IO8/9 I2C │
 │ │ │ │ IO47/48 status LEDs │
 │ │ │ └──┬────┬────┬────┬──────┬───┘
 │ │ │ IO8/9│ IO4│ │IO19│IO20 │IO47/48
 │ │ │ │ │ │ │ │
 │ │ └───────────┤ │ │ │ │
 │ │ ┌──────────▼─┐ │ │ │ ┌──▼──┐
 │ │ │ OLED hdr │ │ │ │ │ LEDs│ grn + red
 │ │ │ 4-pin, opt │ │ │ │ │ 1k │
 │ │ └────────────┘ │ │ │ └─────┘
 │ │ │ │ │
 │ └───────────────┐ │ │ │
 │ ┌───▼───▼┐ │ │
 │ │ AP2171W │ │ │ EN from IO4
 │ │ ILIM │ │ │ so firmware can
 │ └────┬────┘ │ │ power-cycle the UPS
 │ │ VBUS_A│ │
 │ ┌────▼───────▼────▼────┐
 │ │ USBLC6-A │ ESD
 │ └────┬───────┬────┬────┘
 │ │ │ │
 │ ┌────▼───────▼────▼────┐
 └──────────────┤ USB-A receptacle │ right-angle
 GND │ VBUS D- D+ GND │
 └──────────┬───────────┘
 │
 [ UPS ]
```

## What each block is for

| Block | Why it is there |
|---|---|
| **USB-C + polyfuse** | One connector for power, flashing and console. CC1/CC2 pull-downs are what make a charger supply 5V; they are not optional. |
| **AP2114H-3.3** | 3.3V for the module, CH340C, OLED and LEDs. Tab is the output rail; give it ≥100mm² of copper. 450mV dropout, not the AMS1117's 1200mV; on a 5V rail that can legally sag to 4.75V, that is the difference between working and random resets. Order the **H**, not the HA, whose pinout puts VIN on ground. |
| **CH340C at 3.3V** | USB-to-serial. Running it at 3.3V means its TXD/RXD need no level shifting to the S3. `V3` ties to `VCC` at this voltage: at 5V it would need a cap instead, and getting that backwards kills the part. |
| **Q1/Q2 auto-reset** | Lets `esptool` reset and enter bootloader without touching buttons. The cross-coupled emitters mean both transistors stay off when DTR and RTS match, so opening a serial monitor does *not* reset the board. |
| **AP2171W** | Switched 5V to the UPS. `EN` on IO4 is the reliability feature: firmware power-cycles a wedged UPS instead of someone walking to the closet. Current limit is fixed at 1A: a fault limit, not an operating one. The **7**1 matters: AP2161 is active-low enable and would invert the whole feature. |
| **Two USBLC6** | ESD on both USB ports, placed on the connector side of each pair. |
| **USB-A host** | The board supplies VBUS here. **The UPS port sources no power**: this is the single most common reason a build like this never enumerates. |
| **OLED header** | Optional, unpopulated by default. Header and footprint always fitted so a $2 module can be plugged in for debug. |
| **Two LEDs** | Green status, red fault. Plain LEDs rather than a WS2812, which would be an extended part costing $3.07 per order. |

## The three things that will bite

1. **Antenna keepout.** The WROOM-1's antenna must overhang the board edge, no
 copper either layer beneath it, nothing metallic within ~15mm. Place the
 module first; lay out everything else around it.
2. **Bulk capacitance at the module's 3V3 pin.** 100µF, physically adjacent.
 Wi-Fi transmit bursts are why ESP32 designs brown out.
3. **USB pairs.** Tight, matched, top layer, continuous ground beneath, no
 stubs. 12 Mbps needs no controlled impedance, but it does need sane routing.

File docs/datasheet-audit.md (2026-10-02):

# Datasheet audit

Checked part by part against primary datasheets. Pinouts were
verified earlier; **this pass looked at the electrical tables instead**, because
that is where the AMS1117 problem was hiding. Its pinout was right. Its dropout
voltage was not, and no amount of pinout checking would ever have found it.

## What this found

| Part | Checked | Result |
|---|---|---|
| **U3** regulator | dropout vs worst-case supply | **Defect.** AMS1117 needed 4.50 V, had 4.51 V. Replaced with AP2114H-3.3 |
| **D3** status LED | Vf vs the rail driving it | **Defect.** Green Vf 3.3 V typ on a 3.3 V rail. Replaced with a 591 nm yellow |
| **U1** ESP32-S3 module | supply range, EN RC, strapping | OK |
| **U2** CH340C | 3.3 V operation, V3 handling | OK |
| **U4** AP2171W | EN threshold, current limit, FLG | OK |
| **D1, D2** USBLC6-2SC6 | standoff voltage on a 5 V rail | OK |
| **Q1, Q2** MMBT3904 | base drive, ratings | OK |
| **F1** polyfuse | rating, hold vs fault current | OK, 5% margin (see `BOM.md`) |
| capacitors | voltage rating, DC-bias derating | **Defect.** No ratings specified at all. Fixed |

Two defects, both invisible to DRC, to the netlist, to ERC and to every check
that existed before. Both would have produced hardware that looked correct and
behaved badly: random resets blamed on firmware, and an indicator that lit on
some boards and not others.

## The detail

**U1, ESP32-S3-WROOM-1-N4.** Needs 3.0–3.6 V and a supply good for 500 mA; it
gets 3.25–3.35 V from a 1 A regulator. `EN` has Espressif's own recommended
10 kΩ + 1 µF. `GPIO0` is pulled up with no capacitor on it, which the checklist
asks for specifically. `GPIO3`, `GPIO45` and `GPIO46` are left floating, so
their internal pull-downs select 3.3 V `VDD_SPI` and normal boot.

The checklist warns of power-up glitches on GPIO17–20, which are our USB host
lines. That costs nothing here: `VBUS_EN` is pulled *down*, so the switch is off
and the UPS is unpowered until firmware decides otherwise. The safe default
chosen for other reasons covers this too.

**U2, CH340C at 3.3 V.** The datasheet is explicit: at 3.3 V, `V3` is tied to
`VCC`, which is what pins 4 and 16 do. Draws 4–12 mA against the 20 mA budgeted.
At 5 V it would instead need a 100 nF on `V3`; wiring it as we have at 5 V
would be the mistake, and it is not what we have.

**U4, AP2171W.** `EN` needs 2.0 V to read high and gets 3.3 V. `FLG` is open
drain, active low, with a 10 kΩ pull-up: matching `board_vbus_fault`. Input
range 2.7–5.5 V.

**D1/D2, USBLC6-2SC6.** Reverse standoff 5.25 V, breakdown 6.1 V. 5.25 V is
exactly USB's maximum, which is the point of the part. Leakage at that voltage
is tens of nanoamps.

**Q1/Q2, MMBT3904.** The CH340C drives each base through 1 kΩ, about 2.6 mA,
into a transistor needing well under that to saturate at the ~0.3 mA these
collectors carry.

## Espressif recommendations NOT followed

Both are recommendations rather than requirements, and both are deliberate:

**No 499 Ω series resistor on U0TXD.** The checklist asks for one to suppress
harmonics. Ours is a 115200-baud line to a USB-serial bridge on the same board,
a few centimetres long, and the radio is inside a pre-certified module. If this
ever goes for formal emissions testing, this is the first thing to add.

**No series resistors or ground capacitors reserved on the USB lines.** The
checklist asks for 22/33 Ω footprints, unpopulated, close to the chip. That
guidance is aimed at high-speed USB; this board is full speed only, 12 Mbps,
where the edges are slow enough not to need tuning. Adding four unpopulated
0402s to a board at 74% utilisation costs placement and routing for a problem
that is unlikely to appear. Worth reconsidering if a future board has room.

## What a datasheet cannot tell you

Everything above is paper. The failure modes that remain need a built board:
the antenna's real performance next to a metal UPS, whether the UPS enumerates
on hot-plug, and whether anything oscillates. Those are Rev A's job.

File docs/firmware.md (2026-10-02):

# UPS to ESP32 Module firmware architecture

## Design rules

1. **The web interface is the primary UI.** Setup, status, diagnostics and
 firmware update all happen in a browser. No app, no serial console required
 for normal use, no phone pairing. The OLED is optional and off by default.
2. **No GPIO numbers outside `components/board`.** Rev A is the reference
 target and the only one built. (Bring-up ran on a Freenove devkit, removed
 once Rev A existed.) A future revision is a new block in `board.h`.
3. **Absent is not zero.** A UPS that does not report a usage must produce
 `null` in JSON and no `VAR` line in NUT, never `0.0`.
4. **Never require a physical reset.** Wi-Fi dropouts, UPS unplugs and UPS
 firmware wedges are all recovered in software.
5. **If the OLED is fitted, it shows everything the LEDs show.** On Rev A the
 module sits directly over both LEDs, so the screen is the only local
 indicator on a board that has one. Every `board_status_t` state gets a line
 on the screen, and every state that lights the red LED is drawn in reverse.
 Enforced twice: `status_text()` in `display.c` switches with no default, so a
 missing state is a `-Wswitch` error under IDF's `-Werror=all`, and
 `tools/test/test_display_parity.py` checks the same from source, because
 the shipped sdkconfig builds without the display.

## Component layout

```
main/ startup order and wiring only
components/board/ pin maps, VBUS load switch, fault line, button, status LEDs
components/ups_hid/ USB host, descriptor parsing, feature-report polling
components/nut_server/ TCP 3493, read-only NUT subset
components/webui/ HTTP setup + status + OTA, embedded single page
components/netmgr/ Wi-Fi STA, provisioning SoftAP, reconnect forever, mDNS
components/display/ optional SSD1306, compiled out when not fitted
```

`ups_data_t` is the only shared state. `ups_hid` writes it under a mutex;
`nut_server` and `webui` read snapshots. Nothing else holds UPS state.

## USB HID acquisition

The UPS is a USB **device**; the board is the **host** and must supply VBUS.
The UPS port sources no power, which is the single most common reason a build
like this never enumerates.

Sequence per attach:

1. `board_vbus_set(true)`, settle 500ms.
2. Enumerate, read string descriptors into `mfr` / `model` / `serial`.
3. `GET_DESCRIPTOR(Report)` and walk it with `hid_parse_report_descriptor`.
4. `hid_apply_quirks` for known vendor descriptor bugs.
5. Poll on a 2s interval.

**Most useful values arrive only via `GET_REPORT(Feature)` control transfers.**
Espressif's `esp_hid` host component is oriented toward input reports and will
not fetch these, so `ups_hid` issues the control transfers directly against
`usb_host`. Input reports do arrive for some status changes and are handled as
an optimisation, not as the source of truth.

After `FAILURES_BEFORE_RESET` (5) consecutive failed polls, `ups_hid_recover`
drops VBUS for 2s and re-enumerates. This fires **once** per wedge, not on
every cycle, so a UPS that is simply unplugged does not sit in a power-cycling
loop.

## Pass-through policy

**Whatever the UPS reports gets published.** The parser discovers every Power
Device and Battery System field in the descriptor; nothing is filtered on the way
in. What differs is which output a value can reach.

| Channel | What it carries |
|---|---|
| NUT (3493) | Standard NUT variable names, plus `ups.status` flags |
| `/api/status` | The same, as JSON, for the web UI |
| `/api/raw` | **Every discovered usage**, by page and usage ID, named or not |
| MQTT | Every usage, named where possible |

NUT gets standard names rather than raw usages because NUT variable names are a
namespace that Home Assistant, Synology and `upsmon` parse: a variable they do
not recognise is ignored, so inventing names achieves nothing there. NUT's own
`usbhid-ups` works the same way. `/api/raw` exists precisely so nothing is lost:
no namespace applies over HTTP, so the raw usage list goes out verbatim.

`ups_varmap.c` holds the usage+collection to NUT name table, currently 35
entries covering the standard namespace.

### Collections disambiguate values

A usage's meaning depends on its enclosing collection. `Voltage` (0x84:0x30)
appears three times on the captured APC (under `Input`, `Battery` and
`PowerSummary`), so a bare usage lookup cannot tell input voltage from battery
voltage. The parser tracks a collection stack and records the nearest
*significant* enclosing collection with each field; `UPS` and `PresentStatus`
wrap everything and are skipped. `hid_find_in` is the disambiguating lookup.

### What the captured APC yields

Running `tools/decode-hid.py` on `captures/051d-0002-*` gives, from 86 fields:

- **20 standard NUT variables**: `input.voltage`, `input.voltage.nominal`,
 `input.transfer.low`/`.high`, `battery.charge`, `battery.runtime`,
 `battery.voltage`, `battery.voltage.nominal`, `battery.capacity`,
 `battery.capacity.full`, `battery.charge.low`, `battery.type`, `ups.load`,
 `ups.realpower.nominal`, `ups.delay.shutdown`, `ups.beeper.status`,
 `ups.test.result`, `ups.mfr`, `ups.model`, `ups.serial`.
- **11 status bits** feeding `ups.status`: `ACPresent`, `Charging`,
 `Discharging`, `BelowRemainingCapacityLimit`, `NeedReplacement`, `Overload`,
 `ShutdownImminent`, `CommunicationLost`, `BatteryPresent`,
 `RemainingTimeLimitExpired`, `VoltageNotRegulated`. These are flags, not
 variables, which is why they have no NUT variable name.
- **~10 vendor or internal usages** with no NUT equivalent, published raw.

Note this unit reports no `Output` collection at all, so there is no
`output.voltage`: normal for a line-interactive Back-UPS. Absent stays absent
rather than being filled with the input reading.

## Supporting more UPS models

**The generic path is the product. Profiles are the exception.**

USB HID Power Device is a real standard and most units follow it, so a UPS with
no profile at all is expected to work. `components/ups_hid/ups_profiles.c` holds
a table keyed on VID and PID whose only job is to patch models that *deviate*:
a wrong unit exponent, a usage in the wrong page, a value needing inversion.

The rule: **never add a profile to make a UPS work.** Add one only when a unit is
observed reporting something incorrectly, and record what was observed in the
`note` field. An empty table should still yield a working NUT server.

Matching is most-specific-first: exact `vid`+`pid`, then `vid` + `UPS_PID_ANY`,
then `NULL` for the generic path. `NULL` is a normal outcome, not a failure, and
the matched profile name is logged and exposed in `/api/status` so you can see
which path a device took.

To add a model:

1. Capture it with `tools/capture-ups.sh`, which dumps the report descriptor and
 NUT's own decode to `captures/`.
2. Compare `usages.txt` against the mapping table below. If everything lines up,
 **you are done**: no profile needed.
3. Only if a value is wrong, add a table entry with a `fixup` that corrects that
 one field, and say in `note` what you measured and how.

Note that one board serves one UPS. Several UPSes means several boards, which is
the cheap answer at roughly $10 each. Monitoring multiple units from a single
board needs a USB hub IC and is deferred; `ups_data_t` being a single
struct rather than an array is a deliberate part of keeping Rev A simple.

### Known quirk: CyberPower voltage scaling

Several CPS models declare a wrong unit exponent for `output.voltage`, giving
1230 or 12.3 where the real value is 123. NUT's `cps-hid` subdriver patches
this at runtime and so does `hid_apply_quirks`, keyed on VID and usage rather
than on model string.

**Still unverified against a CyberPower**, because no CyberPower has been
captured: `ups_profiles.c` carries the entry as an empty placeholder and says
so. What *has* been shown, on a real APC, is that the generic path needs no
quirk at all: report 49 required shift 0 and report 38 required shift −2, and
`hid_unit_decimal_offset` produced both correctly, giving 120.0 V and 27.14 V.
That is this whole class of bug not happening without a vendor table. When a
CyberPower is on the bench, check it against a meter before trusting any
correction.

## HID usage to NUT variable mapping

Usage IDs below are confirmed against a real capture (APC Back-UPS RS 1000G,
`captures/051d-0002-*`). Decode any new unit with `tools/decode-hid.py`.

| Page | Usage | `ups_data_t` field | NUT variable | Unit |
|---|---|---|---|---|
| 0x85 Battery | 0x66 RemainingCapacity | `battery_charge` | `battery.charge` | % |
| 0x85 Battery | 0x68 RunTimeToEmpty | `battery_runtime` | `battery.runtime` | s |
| 0x84 Power | 0x30 Voltage (battery path) | `battery_voltage` | `battery.voltage` | V |
| 0x84 Power | 0x30 Voltage (input path) | `input_voltage` | `input.voltage` | V |
| 0x84 Power | 0x32 Frequency | `input_frequency` | `input.frequency` | Hz |
| 0x84 Power | 0x30 Voltage (output path) | `output_voltage` | `output.voltage` | V |
| 0x84 Power | 0x35 PercentLoad | `ups_load` | `ups.load` | % |
| 0x84 Power | 0x44 ConfigActivePower | `ups_realpower_nom` | `ups.realpower.nominal` | W |

Note that `Voltage` (0x84:0x30) appears several times under different parent
collections (input, output and battery), so a bare usage lookup is ambiguous.
The capture shows report IDs 9, 38 and 49 all carrying `Voltage`. Resolving which
is which requires tracking the enclosing collection, which the parser does not
yet do. **This is the main open problem for M1.**

### Scaling

A field's real value is `raw * 10^(unit_exponent - unit_offset)`, where
`unit_offset = 2*length_exp + 3*mass_exp` from the HID Unit field, because HID's
SI Linear system measures in centimetres and grams rather than metres and
kilograms. That gives 7 for volts and watts and 0 for amps, seconds, hertz and
dimensionless values.

This is the generic explanation for voltages arriving as 1230 or 12.3 instead of
123, and it is why no vendor profile is needed for it. Confirmed on the APC
capture: report 49 declares exponent 7 for volts (raw is already volts, max 255)
while report 9 declares exponent 5 (centivolts, max 655.35).

### Status bits

Assembled into `ups.status`. Usage IDs confirmed from the APC `PresentStatus`
bitfield in report 22:

| Page | Usage | Bit | NUT flag |
|---|---|---|---|
| 0x85 | 0xD0 ACPresent | `UPS_STATUS_ONLINE` | `OL` |
| 0x85 | 0x45 Discharging | `UPS_STATUS_ONBATT` / `UPS_STATUS_DISCHARGE` | `OB` / `DISCHRG` |
| 0x85 | 0x42 BelowRemainingCapacityLimit | `UPS_STATUS_LOWBATT` | `LB` |
| 0x85 | 0x44 Charging | `UPS_STATUS_CHARGING` | `CHRG` |
| 0x85 | 0x4B NeedReplacement | `UPS_STATUS_REPLACEBATT` | `RB` |
| 0x84 | 0x65 Overload | `UPS_STATUS_OVERLOAD` | `OVER` |
| 0x84 | 0x69 ShutdownImminent | - | drives `LB` as a fallback |
| 0x84 | 0x73 CommunicationLost | - | marks the snapshot stale |
| 0x85 | 0xD1 BatteryPresent | - | absent battery is a fault |
| 0x85 | 0xDB VoltageNotRegulated | - | informational |

Where `ACPresent` is absent, derive `OL` as "not Discharging" rather than
reporting `OFF`. A UPS reporting neither yields `OFF`, not a guess.

**Confirmed against live reports.** These IDs were taken from the
HID Power Device spec assignment and, until M1, only produced a coherent
bitfield on paper. macOS would not release the device to userspace, so only the
descriptor had been captured.

A real APC Back-UPS RS 1000G has now been read through a full transfer to
battery and back: `OL` on mains, `OB,DISCHRG` with the plug pulled, `OL,CHRG` on
restore, with `battery.charge` falling 100→97% and `battery.voltage`
26.74→25.40 V in between. **`ACPresent`'s polarity is the one that matters**:
it decides `OL` against `OB`, and inverted it reports "on battery" to Home
Assistant while the mains is fine. It is the right way round. See
`captures/051d-0002-m1-values-20260919/`.

Still unproven: `LB`. It is mapped from `BelowRemainingCapacityLimit` but no run
has taken the battery low enough to assert it.

## Power and runtime reporting

**Runtime is measured. Power usually is not.**

`RunTimeToEmpty` (0x85:0x68) is reported directly, in seconds, and becomes
`battery.runtime`. The UPS computes it from present load and battery state.

Power is another matter. The captured APC Back-UPS RS 1000G reports
`PercentLoad` and `ConfigActivePower` but **neither `ActivePower` nor
`ApparentPower`, and no `Current` or `Frequency`**. Most consumer UPSes are the
same: they do not meter power. So watts can only be derived:

```
watts ≈ PercentLoad% × ConfigActivePower
```

`ups_power_watts` returns the best available figure and sets an `estimated`
flag saying which route it took, so every consumer can label it honestly. It
returns `UPS_VALUE_ABSENT` when neither route exists, never a fabricated zero.

Limits of the derived figure, which matter when planning against it:

- **1% granularity.** About 6W steps on a 600W unit. A load under ~30W reads as
 0–5% and is effectively invisible.
- **No power factor.** Without `ApparentPower` there is no VA, so the number
 trusts the UPS's own load calibration.
- **Useful for trend and headroom, not energy accounting.** Do not bill from it.

### NUT variable policy

`ups.realpower` is published **only when the UPS actually measures it.** A
derived value is exposed through `/api/status` and MQTT, clearly marked
estimated, and never presented as a measured NUT variable. Publishing a computed
figure as `ups.realpower` would be exactly the fabrication that "absent is not
zero" exists to prevent: a Home Assistant user cannot tell a metered watt from
an inferred one, and will make capacity decisions on it.

Home Assistant users who want a watts sensor anyway can build one from
`ups.load` and `ups.realpower.nominal`, which is the same arithmetic done
somewhere the estimate is visible.

### Planning a failure exercise against this

Three things to know before treating these numbers as a budget:

1. **The runtime figure reflects load at that instant.** Read it, then add load,
 and it was optimistic before you started.
2. **It is the UPS's own estimate, and it flatters an aged battery.** A cell that
 has lost half its capacity often still reports a confident runtime.
3. **Derived watts inherit 1% granularity**, so small changes are invisible until
 they cross a step.

The honest measurement is empirical: **record what actually happened.** Proposed
use for the unallocated flash (see Flash layout) is an event log that captures,
on every transfer to battery, a timestamp, load percentage, starting charge, the
runtime the UPS predicted, and how long the transfer actually lasted. After two
or three real events that log is worth far more than the UPS's own estimate,
because it is measured under real load with the actual battery. Not implemented;
recorded here so the flash stays reserved for it.

## NUT protocol subset

Read-only. No `INSTCMD`, no `SET`, no shutdown control in Rev A firmware.

| Command | Behaviour |
|---|---|
| `VER` | `UPS to ESP32 Module <version>` |
| `NETVER` | `1.2` |
| `LIST UPS` | one entry, `ups`, with a description |
| `LIST VAR ups` | every populated variable |
| `GET VAR ups <var>` | one variable, or `ERR VAR-NOT-SUPPORTED` |
| `GET DESC ups <var>` | short description |
| `USERNAME` / `PASSWORD` / `LOGIN` / `LOGOUT` | accepted, credentials ignored |
| `GET NUMLOGINS ups` | count of connected clients |
| `STARTTLS` | `ERR FEATURE-NOT-SUPPORTED` |
| anything else | `ERR UNKNOWN-COMMAND` |

Home Assistant issues `LIST UPS` then `LIST VAR` and little else. `upsmon`
additionally expects `LOGIN` and `GET NUMLOGINS` to answer coherently, so they
are implemented even though authentication is not enforced: the device is
read-only and lives on a trusted LAN. **If shutdown commands are ever added,
authentication stops being optional.**

## Web interface

Single embedded page, no CDN and no framework: the device is frequently on a
network with no internet route.

| Route | Method | Purpose |
|---|---|---|
| `/` | GET | status + setup page |
| `/api/status` | GET | JSON snapshot, polled every 3s |
| `/api/scan` | GET | visible APs for the setup form |
| `/api/wifi` | POST | store credentials, reconnect |
| `/api/ups/reset` | POST | power-cycle the UPS USB interface |
| `/api/cmd` | POST | `{cmd, arg}`: run a UPS command, see below |
| `/api/ota/check` | POST | ask GitHub what the latest release is |
| `/api/ota/install` | POST | download and write it: only ever from a click |
| `/api/ota/auto` | POST | `{enabled}`: permit the twelve-hourly check |
| `/api/reboot` | POST | restart the board |
| `/api/auth/login` | POST | `{user, pass}` → `{token}` |
| `/api/auth/logout` | POST | forget this browser's token |
| `/api/auth/set` | POST | `{user, pass}` creates the login (the first time, no login needed) or changes it |

Every POST is refused if a browser sent it from another page (its `Origin`
names a different host): otherwise any web page open anywhere on the LAN could
post `load.off` to the board in the background. Scripts send no `Origin` and
are unaffected. Every POST except login and logout also needs the page's token
in `X-Auth-Token`, or the username and password as HTTP Basic, and so does every
read of the page's data (see The login, below): `curl -u admin:pass -X POST http://ups-esp32-XXXX.local/api/reboot`.

**The page names the failure.** A request that gets no reply at all reads
"Can't reach the board at <host>. Is this phone or computer on the same network
as it (not a VPN or guest Wi-Fi)?"; a reply the page cannot parse gives its
HTTP status and says to reload; a board waiting for a login says "locked" in
its subtitle rather than "connecting…". All three used to read "the board did
not answer", which sent an owner on a VPN looking for a password problem.

There is no factory-reset route: clearing the network is what makes a board in
a closet unreachable, so it takes someone at the board (below).

First boot with no stored credentials brings up SoftAP `ups-esp32-XXXX` with
a captive-portal redirect, so setup needs only a browser. Pressing BOOT five
times within four seconds clears credentials -- Wi-Fi and the login -- and
restarts into setup, which is
the recovery path for a device given the wrong network. Holding BOOT at
power-on cannot do it -- GPIO0 is the download strap, so the ROM flasher runs
instead -- and a long hold is ruled out too, because a serial terminal raising
DTR alone holds GPIO0 low through the auto-reset transistor.

## Being a NUT server without NUT

NUT's wire protocol is public and line-based, so a client cannot tell the
difference between this and `upsd`, which matters, because NUT itself could
not run here. Its driver calls `fork`, `chroot`, `setuid` and `opendir`, links
libusb, and publishes to `upsd` through a Unix socket under a state directory.
ESP-IDF has tasks rather than processes, lwIP has no `AF_UNIX`, and the USB
stack is Espressif's own. Porting it means replacing the process model, the
IPC, the config parsing and the USB layer, at which point nothing of NUT is
left. Implementing the protocol is the smaller job by a wide margin, and the
data model was already in NUT's vocabulary.

Implemented: `VER`, `NETVER`/`PROTVER`, `HELP`, `LIST UPS`, `LIST VAR`,
`LIST CMD`, `LIST RW`, `LIST CLIENT`, `GET VAR`, `GET DESC`, `GET UPSDESC`,
`GET CMDDESC`, `GET NUMLOGINS`, `INSTCMD`, `SET VAR`, `LOGIN`, `LOGOUT`,
`USERNAME`/`PASSWORD`, and `STARTTLS` refused with `ERR
FEATURE-NOT-SUPPORTED`. Unknown input gets NUT's own error vocabulary --
`ERR UNKNOWN-UPS`, `ERR VAR-NOT-SUPPORTED`, `ERR CMD-NOT-SUPPORTED` -- because
a client that receives an error it does not recognise behaves worse than one
that receives a refusal it does.

`LIST CMD` advertises only the commands the attached UPS actually implements,
from the same capability bits that drive the web UI. `GET VAR` is answered by
searching the string `LIST VAR` builds, so the two cannot disagree about which
variables exist. A variable the UPS does not report is absent rather than
zero: a NUT client treats a present variable as authoritative.

`USERNAME` and `PASSWORD` always answer `OK`, as `upsd` does, and are checked
only when a write asks for them -- see The login, below.

## The login

**Required** (v0.10-rc8 on; it was optional before). Setup asks for a username
and password with the Wi-Fi details. A board updated from a release where the
login was optional and never set shows only "Create a login for this board"
until one exists, and until then refuses every change -- on the page and over
NUT -- except creating it. The login cannot be turned off, only changed, and a
password is at least 8 characters.

**The whole page is behind it**: `/api/status`, the debug, network, scan,
descriptor and release-notes endpoints answer 401 without the page's token (or
HTTP Basic, for scripts: `curl -u admin:pass`). **Monitoring is not**: NUT's
`LIST`/`GET` and `/metrics` stay open, as `upsd` and a Prometheus exporter are,
so Home Assistant, a NAS and Prometheus watch the UPS with no setup. NUT's
writes (`INSTCMD`, `SET VAR`) need the login, refused in `upsd`'s words and
order: `ERR USERNAME-REQUIRED`, `ERR PASSWORD-REQUIRED`, `ERR ACCESS-DENIED`.
A monitor that volunteers credentials and only reads -- Synology sends
`monuser`/`secret` -- is never refused, since the check happens at the write.
To send a command:

    upscmd -u admin -p yourpassword ups@ups-esp32-XXXX.local load.off

In Home Assistant's NUT integration the username and password fields are only
needed for its command buttons.

**Stored hashed** (salted, 4096 rounds of SHA-256, in hardware on the S3), so a
flash dump does not hand over a password someone uses elsewhere. **Five wrong
passwords in a row** lock checks out for a minute, the web login and NUT
together. A web login lasts until 12 hours idle, the board restarts, or the
login changes. **The lockout is board-wide**, not per client: anyone on the
LAN sending wrong passwords keeps the owner out too, a minute at a time. Known,
and to be made per-client.

**Setting a password** asks for it twice and shows a rough strength bar (Too
weak … Strong: length counts most, mixing kinds of character helps). Under 8
characters, one character repeated, or one of the first passwords scanners try
(`admin`, `password1`, `12345678` …) is refused on the page before anything is
sent. The bar is a guide, not zxcvbn: that library alone is several times the
size of the whole page.

**Forgot it?** Plug a computer into the board's USB-C port, open the serial
console at 115200 and type `clear-login`. That removes the login and nothing
else -- Wi-Fi, address and settings stay -- and the page then asks for a new
one. A whole line must match, so log noise or a terminal's echo cannot trip
it. It is the same trust as the BOOT button, someone holding the board's cable,
without opening a case. Pressing BOOT five times still works too, and clears
Wi-Fi with the login.

**What it is not:** encryption. The page is plain HTTP and NUT is plain text,
as `upsd` is without TLS, so the password crosses the LAN readable. It keeps
people and stray scripts from changing things; it does not stop someone who can
capture your network traffic. `tools/test/test_auth.py` checks the rules and
fails if a POST route is added without the check.

## Commands, and why the UI is built from the UPS

`/api/cmd` takes NUT's own instcmd names -- `test.battery.start.quick`,
`test.battery.start.deep`, `test.battery.stop`, `beeper.disable`,
`beeper.enable`, `beeper.mute`, `load.off` (arg = seconds) -- plus
`battery.charge.low` (arg = percent) and `battery.date`, which NUT models as
read-write variables rather than commands. One vocabulary across both outputs
means the dispatch on 3493 is a lookup, not a translation. Each maps to one
writable Feature usage:

| Command | Usage | Page |
|---|---|---|
| `test.*` | `Test` 0x58 | Power Device |
| `beeper.*` | `AudibleAlarmControl` 0x5A | Power Device |
| `lowbatt.limit` | `RemainingCapacityLimit` 0x29 | Battery System |
| `load.off` | `DelayBeforeShutdown` 0x57 | Power Device |

**Nothing is assumed from the model name.** At enumeration `discover_caps`
looks each usage up in the parsed descriptor and sets a bit in
`ups_data_t.caps`; a command whose bit is clear returns `ESP_ERR_NOT_SUPPORTED`
and the web UI never draws its button. The bench APC reports all four. A UPS
with none gets a page that says so, and that is the same code path.

**Writes are read-modify-write.** A report can carry several fields (on this
APC report 21 holds `DelayBeforeShutdown` next to its neighbours), so writing a
freshly zeroed buffer would clobber them. Reading first costs one control
transfer and means a beeper command cannot set a shutdown timer by accident.

**Commands run on the polling task.** `ctrl_in` and `ctrl_out` both pump
`usb_host_client_handle_events`, and that pump belongs to one task; a command
arriving on the web server's task would be a second pumper on the same client.
Requests are queued, executed between polls, and the caller waits for a result.

**The `Test` usage is written with one table and read with another.** NUT's
`usbhid-ups` writes 1/2/3 for quick/deep/abort, but reads 0 "No test",
1 "Done and passed", 2 "Done and warning", 3 "Done and error", 4 "Aborted",
5 "In progress", 6 "No test initiated". Inferring one table from the other is a
mistake this project made and caught on hardware: the idle APC returns 6, which
under the spec-shaped guess reads as "error". A status page that calls a healthy
battery FAILED is worse than one that says nothing. The tables were checked
against the shipped `usbhid-ups` binary.

**What "deep" does is the UPS's choice.** The HID usage tables define the
values and nothing about what a deep test is; "calibration" appears nowhere in
them, and no NUT HID subdriver implements `calibrate.start`. Measured on the two
tested units (`docs/tested-ups.md`): the APC RS 1000G runs a real run-down, 40
minutes to 22 % at 10 % load; the CyberPower EC850LCD runs its 4-second quick
test. Both report success either way, so "the UPS accepted it" is all a caller
learns.

**A UPS's reports can freeze during a test.** For 15 minutes of that APC deep
test, every fresh GET_REPORT said "on mains, 100 %, No test initiated" while the
battery drained; power-cycling the UPS's USB (the VBUS switch) made it
re-enumerate and report the truth. A real outage during such a freeze would be
reported as mains. Separately, the EC850LCD reported no status bits for about
two minutes after a test and a USB power cycle, which the NUT server shows as
`OFF` -- the class of glitch that made `upsmon` shut hosts down on APC RS units
(NUT #2104).

**The page warns before and after.** `DEEP_KNOWN` in `index.html` lists what
each measured model does: a model whose deep test is its quick test gets a
disabled button and the reason; one that runs it but may hide it gets that in
the confirm box. Any other model is watched: done inside three minutes is
reported as a short self-test, no sign of starting within 75 s as possibly
hidden, with Power-cycle UPS link as the check. NUT clients are not told --
`test.battery.start.deep` stays in `LIST CMD`, as `usbhid-ups` offers it.

**Planned, not yet built:** hold the last status through a brief
all-zero status while the UPS is attached and live, power-cycling its USB if it
persists; after a test command, expect "In progress" or a moving charge within
a minute, and re-enumerate if neither comes; clear the previous result before a
test (abort, then 0, as apcupsd does) and refuse a deep test below 100 %.

**`load.off` is not like the others.** It cuts power to everything the UPS
feeds, and on a finished board that includes this adaptor, it goes dark and
cannot report what happened. This APC has `DelayBeforeShutdown` and no
`DelayBeforeStartup`, so there is no matching "on": the outlets stay dead until
mains returns. The web UI keeps the button disabled until someone types `OFF`.

Three details in the network path are decisions rather than defaults:

**The setup AP is open.** A passphrase on a setup network has to be printed on
the board or in the manual, so it is public anyway, and it stops a phone
joining by itself. The only thing the AP accepts is the credentials for the
network the person is standing in.

**Provisioning reboots rather than switching mode in place.** A live
APSTA-to-STA switch has to tear down the access point the browser is talking to
from inside the request that browser is waiting on, then bring up a station and
get a lease. The reboot does the same work in a known order with no
half-states. `netmgr_provision` defers it by 1.2 s so the HTTP reply leaves
first; otherwise the page reports a failure for something that worked.

**The captive-portal DNS answers every question with 192.168.4.1.** That is
what makes a phone show the setup page by itself: it fetches a known URL after
joining and displays whatever comes back. Without a resolver on an isolated AP
the lookup fails and no sheet appears. The reply is assembled by hand (echo
the question, append one answer record) because that is a dozen lines against
a DNS library for one probe.

The same wildcard route is an ordinary 404 once the device is on a real
network. Redirecting every stray request there would break a browser rather
than help it.

## Prometheus metrics

`GET /metrics` is a Prometheus scrape target in the text exposition format,
rendered by `components/webui/metrics.c` and streamed line by line, so its size
never has to fit a buffer.

UPS readings use **nut_exporter's names**, checked against its README: every
NUT variable as `network_ups_tools_<name, dots as underscores>` with a `ups`
label, the status as `network_ups_tools_ups_status{flag="OL"}` with each flag
present as 0 or 1, and `network_ups_tools_device_info` carrying mfr, model,
serial and USB IDs. Dashboards and alerts written against nut_exporter should
work with Prometheus scraping the board directly. Only the seven flags this
firmware can set are exported (OL, OB, LB, RB, CHRG, DISCHRG, OVER);
nut_exporter can list others, which would be permanently zero here.

The board's own health is under `ups_esp32_`: `ups_attached`, `build_info`,
`uptime_seconds`, `crashes_total`, `heap_free_bytes`, `heap_min_free_bytes`,
`wifi_rssi_dbm`, `nut_clients`.

A value the UPS does not report is **absent**, never 0 -- the same rule as NUT
and `/api/status`. A missing series is honest; a battery charge of zero pages
someone. `tools/test/test_metrics.py` renders three boards on the host and
checks the format (with `prometheus_client`'s own parser when installed), the
naming, and the absences.

```yaml
scrape_configs:
  - job_name: ups
    static_configs:
      - targets: ["ups-esp32-XXXX.local:80"]
```

## Discovery

`netmgr` advertises `ups-esp32-XXXX.local` over mDNS once an address is acquired
-- the same `XXXX` as the setup access point, from the last two bytes of the AP
MAC, so two boards on one network never claim the same name. The same name is
sent as the DHCP hostname, so it is also what a router's client list shows. It
also advertises `_http._tcp` on 80 and `_nut._tcp` on 3493. This is the normal way to reach
the web UI, and it works on boards with no OLED fitted. Setup is idempotent and
re-runs harmlessly after a reconnect. An mDNS failure is logged and ignored --
the IP address still works, and the device must keep serving NUT regardless.

## Status indication

Three layers, in decreasing order of detail: the **web UI** (everything), the
**optional OLED** (UPS power state, readings, IP, NUT clients, Wi-Fi,
firmware, and the LED state), and **two
plain LEDs**. The OLED is a superset of the LEDs by rule (design rule 5).

The LEDs are deliberately coarse, and are a green/red 0603 pair rather than an
addressable RGB part -- a WS2812B is an extended component at JLC, so a $0.06
LED costs $3.13 on a small run, and it would pull the RMT driver in for status
detail the other two layers already carry.

| State | Green | Red | OLED line 3 |
|---|---|---|---|
| Booting | solid | off | `STATUS BOOTING` |
| Provisioning AP up | fast blink | off | `STATUS SETUP` |
| Connecting or retrying | slow blink | off | `STATUS CONNECTING` |
| Online, UPS present | solid | off | `STATUS OK` |
| Online, no UPS | solid | slow blink | `STATUS NO UPS`, reversed |
| VBUS fault | off | solid | `STATUS VBUS FAULT`, reversed |

`board_status_set` takes a semantic state, not pins, so the LED scheme can
change without touching a caller. The display reads the same state back with
`board_status_get`, so the screen and the LEDs cannot disagree. They used to:
the screen drew its own conclusions from `netmgr` and `ups_hid`, and printed
`VBUS FAULT` only while no UPS was attached, while the red LED showed a fault
whether a UPS was attached or not. On the devkit the calls compile to a log line;
the patterns are verified on Rev A.

## Optional OLED

Gated on `CONFIG_UPSA_HAVE_OLED`, default off, and offered only on boards whose
header takes a standard module as seated (`UPSA_BOARD_OLED_OK`). Plain Rev A's
does not -- it is wired in reverse -- so plain Rev A firmware never drives a
display. The `reva-oled` board target is the real, released path for a module
labelled VCC, GND, SCL, SDA: its power pins match J3, and selecting that board
in Kconfig pulls in `UPSA_REVA_OLED_VCC_FIRST`, which swaps the display's
SDA/SCL to suit (`BOARD_OLED_SDA`/`_SCL` in `board.h`) and turns the display on,
both automatically -- neither is set independently, so the pin swap and the
board identity that advertises it cannot drift apart. `release.yml` refuses a
plain Rev A image with the swap set, but builds and ships `reva-oled` as its
own target, with its own `BOARD_OTA_TARGET` so a plain Rev A board can never
be offered it. When disabled the whole component is `#if`'d out to no-op
stubs, so `main.c` calls it unconditionally with no `#ifdef` at the call site
and a board without the module pays nothing.

When enabled it probes the bus first; an absent or unresponsive panel logs a
warning and the device carries on serving NUT. The font is a 43-glyph 5x7 subset
(space, `% - . / : ?`, digits, `A-Z`, lowercase folded up) because no status line
needs more. Assumes I2C address 0x3C; some modules are 0x3D.

### Screen layout

Rows 0-2 are the same on every page, so an alarm is never paged out of view:

| Row | Shows |
|---|---|
| 0 | UPS model, or `UPS-ADAPTOR` with none attached |
| 1 | What the UPS is doing: `ON LINE`, `ON LINE  CHARGING`, `ON BATTERY`, `ON BATTERY  LOW`, `OVERLOAD`, `REPLACE BATTERY`, or `UPS NOT FOUND`. Everything but on line is reversed |
| 2 | The LED state (design rule 5), reversed when the red LED is lit |

Rows 4-7 alternate every 5 seconds between two pages:

| Row | Page 1 | Page 2 |
|---|---|---|
| 4 | `BATT 97%  RUN 45M` | `BATT 26.7V  OUT 120V` |
| 5 | `IN 120V LOAD 12%` | NUT status words, `FLAGS OL CHRG` |
| 6 | IP address, or the setup AP | Wi-Fi signal, `WIFI -55 DBM` |
| 7 | `NUT 2 CLIENTS` | `FW <version>`, or `UPDATE <tag>` when one is available |

`NUT n CLIENTS` is there because "is Home Assistant actually watching?" is
otherwise the hardest thing to check on this device.

**Burn-in.** An OLED in a closet shows the same rows for months, and those burn
into the panel first. After 5 minutes with no change of state the screen dims
to minimum contrast. Every 2 minutes all text shifts one pixel sideways,
through a 0-3 pixel cycle, so no column stays lit forever. Any change of state
(device, attach, UPS status) brings full brightness back, and nothing dims
while row 1 or row 2 is showing an alarm.

**BOOT at runtime.** A press wakes a dimmed screen, and on a lit screen flips
to the other page. Five presses within four seconds also clear Wi-Fi settings.

## Wi-Fi reliability

`netmgr` reconnects indefinitely with backoff capped at 30s, never
exponential-forever, because a bridge offline for an hour must still rejoin
within 30s of the AP returning. Radio power save is disabled: a NUT client may
connect at any moment and the saving is irrelevant on a mains-powered device.

The backoff waits on an `esp_timer` one-shot, not inside the disconnect handler.
Wi-Fi and IP events are delivered one at a time by a single default event loop
task, so sleeping in a handler stalls every other event behind it, including
`GOT_IP` and the mDNS bring-up that hangs off it. The handler arms the timer and
returns; the timer's own task calls `esp_wifi_connect`. Re-arming an already
armed timer is harmless, which collapses a burst of disconnect events into one
pending attempt, and a successful connection cancels it.

## Flash layout

4MB, two 1.94MB app slots. An OTA update is written to whichever slot is not
running and then booted from, so a bad image rolls back rather than bricking a
device in a closet. The slot is generous here because the web UI is embedded in
the binary rather than living on a filesystem: the application is 1.0MB of the
1.94MB available.

There is no spare region. The two slots consume the part exactly, which is the
cost of moving from the 8MB N8 to the 4MB N4: the event log of transfers to
battery that the larger part had room for is not available here. Reinstating it
means going back to N8.

## Firmware update

Images come from this repository's GitHub **releases**, not from a branch and
not from a file the owner uploads. A release is a deliberate act with a tag on
it, so publishing one is the only thing that can move a device.

Two separate consents, and only one of them is automatic:

| | Automatic? | Why |
|---|---|---|
| Noticing | only if enabled, then every 12h | a device on a private network reaching the internet on a timer is the owner's decision |
| Installing | **never** | it writes flash and reboots something the house may depend on |

**Which asset.** `ups-adaptor-<target>.bin`, where target is
`BOARD_OTA_TARGET`. A release with no asset for this board is not an update.

**The filename is not trusted.** Every image declares its board in its app
descriptor's project name (`ups-adaptor-reva`, `ups-adaptor-freenove`), and the
client reads the incoming descriptor and refuses anything that is not its own
name *before writing a byte* to the other slot:

```
E (53492) ota: REFUSED: image is "ups-adaptor-reva", this board runs "ups-adaptor-freenove"
```

That is not hypothetical. `v0.02c` shipped a Rev A build under the devkit's
filename, and a devkit installed it and came up believing it had a load switch
on GPIO4. A name is a label anyone can get wrong; a descriptor is what the
image says about itself. It is also what makes a future board revision safe:
an older unit cannot take its firmware however the file is named.

A refused tag is **remembered for the rest of the boot** (`OTA_INCOMPATIBLE`,
`ota_status_t.refused`), so the periodic check stops putting an Install button
in front of someone for a file that cannot be installed. It is not persisted:
the usual fix is to re-upload the asset under the same tag, and a memory that
survived a reboot would keep refusing the corrected file. An explicit *check
now* clears it, so nobody is ever stuck.

**Rollback is earned, not assumed.** A freshly installed image boots on trial
and reverts unless it confirms itself. Confirming on Wi-Fi association is
worthless against the bugs that actually shipped here: a handler table too
small to register and a web server stack too small to answer both let the
device boot, associate and confirm itself seconds before the first request
killed it. It now takes five minutes of uptime *and* three served HTTP requests.
See `docs/RELEASING.md`.

## Prior art

GPL-3.0 is chosen to stay compatible with reusing logic from existing ESP32 NUT
server projects. Where code or protocol detail is taken from one, attribute it
in the file header. NUT's own `usbhid-ups` and `cps-hid` subdriver are the
reference for HID interpretation and are GPL-2.0-or-later.

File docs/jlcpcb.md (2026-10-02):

# Manufacturing
and is enforced by `tools/test/test_jlc.py`, which measures the board rather
than trusting the design rules stored in it.

- <https://jlcpcb.com/capabilities/pcb-capabilities>
- <https://jlcpcb.com/capabilities/pcb-assembly-capabilities>

## Why this is a separate check from DRC

DRC compares the board to the rules **inside** the board. If those rules are
looser than the fab's, DRC passes and the fab either rejects the job or builds
something that fails. Worse, several of JLC's limits have no DRC rule at all:
silkscreen line width and text height are not checked by KiCad's
`min_text_thickness` / `min_text_height`, which apply only to text on copper.

So the harness measures the real geometry and compares it to JLC's published
numbers directly. The two cannot drift apart.

## Board process: 2-layer FR-4, 1 oz

| Limit | JLC | This board |
|---|---|---|
| Track width | 0.10 mm | **0.20 mm** |
| Track clearance | 0.10 mm | **0.20 mm** (board rule) |
| Via hole | 0.15 mm | **0.30 mm** |
| Via pad | 0.25 mm | **0.60 mm** |
| Via annular ring | 0.05 mm | **0.15 mm** |
| Plated-hole annular ring | 0.18 mm absolute, 0.25 recommended | **0.20 mm** (J1 shield leg) |
| Via hole to via hole | 0.20 mm | **0.52 mm** |
| Plated hole to plated hole | 0.45 mm | **0.51 mm** |
| Copper to board edge | 0.20 mm | **0.90 mm** |
| Silkscreen line width | 0.15 mm | **0.15 mm** |
| Silkscreen text height | 1.00 mm | **1.00 mm** |

Everything has margin except the two silkscreen rows and J1's shield leg.

**J1's 0.20 mm ring is the one number worth knowing about.** It comes from the
stock USB-C footprint's through-hole shield legs and is above JLC's absolute
minimum but below their recommended 0.25 mm, so registration is tighter than
they like. It will be built. If a batch shows breakout there, the fix is a
footprint with larger shield pads, not a process change.

## Assembly: Economic PCBA

**Every part is on the top side, and has to be.** JLC's capability table gives
Economic PCBA as *"Single sided placement (SMT/Thru-hole)"*; double-sided
placement exists only under Standard PCBA, whose minimum single board is
**70 x 70 mm** (this one is 36 x 58) and whose setup fees are several times
higher. Rev A's first complete layout had 25 parts on the bottom. It passed DRC,
the ground check and every JLC *fabrication* limit, and could not have been
ordered on the service the whole project is costed around. The reasoning at the
time was that a two-layer board costs the same with parts on one side or two.
True of the bare PCB; not of assembly.

Moving everything to the top cost no board area: it still routes at 36 x 58,
both copper layers still carry tracks, and the bottom is now a nearly unbroken
ground plane. `tools/test/test_bom.py` fails the harness if any placement is on
the bottom.

| Limit | JLC | This board |
|---|---|---|
| Board size | 10 × 10 mm to 470 × 500 mm | 36 × 58 mm |
| Smallest package | 0402 | 0402 |
| Minimum IC pin pitch | 0.40 mm | 1.27 mm (SOIC-16) |
| Edge rails | not required | none |
| Placement sides | **one** | one (top) |

The 0402 passives sit exactly on Economic PCBA's limit. That is supported, not
marginal. It does mean there is no room to go smaller without moving to the
Standard service.

**Through-hole parts are assembled**, contrary to what this project's notes used
to say. JLC fits them by hand at **$3.50 labour plus $0.0173 a joint**. The
labour fee is once per order, so J3 and J5's 11 joints cost cents on top of it.
Fit them yourself or let JLC; just decide before ordering.

## Ordering

```sh
tools/pack-fab.sh
```

Produces the three uploads and nothing else:

| Tab | File |
|---|---|
| PCB | `hardware/fab/ups-adaptor-gerbers.zip` |
| BOM | `hardware/bom/bom.csv` |
| Placement | `hardware/bom/cpl.csv` |

**All three are committed**, so an order can be placed from any machine, or
straight off GitLab, without KiCad installed. The usual objection to committing
generated artifacts is that a stale one passes every gate that never looks at
it. So `pack-fab.sh` records the SHA-256 of the board it plotted from in
`hardware/fab/SOURCE.sha256`, and `tools/test/test_fab.py` fails the harness if
the board no longer hashes to it. Timestamps would not survive a clone; a hash
does. The same test checks the zip carries every manufacturing layer and no
documentation layer.

**Do not upload `hardware/fab/ups-adaptor-cpl.csv`.** That is KiCad's raw
position export, an intermediate `gen-bom.py` reads, and it carries raw KiCad
angles: it would fit eight parts the wrong way round. It is gitignored for
that reason. The file to upload is `hardware/bom/cpl.csv`.

The zip carries **only** manufacturing layers: copper, mask, silkscreen, paste
and edge cuts, plus the two drill files. `kicad-cli pcb export gerbers` with no
`--layers` also emits Courtyard, Fab, Adhesive, Margin and four `User_*` layers,
which are documentation; a fab importer either ignores them or offers to treat
one as a real layer.
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

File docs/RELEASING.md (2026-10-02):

# Releasing firmware

Every rule here was written after something broke. The reasoning is kept with
each one, because a rule whose reason is forgotten gets removed by the next
person in a hurry.

## The one that matters

**A device in a closet has no cable.** Everything below follows from that. A
bad release does not mean a bad afternoon; it means someone drives to a site,
or a UPS goes unmonitored until they do. The cost of an extra check before
publishing is minutes. The cost of skipping one is measured in journeys.

## What already shipped, and would have been a field incident

| Release | Fault | Why nothing caught it |
|---|---|---|
| `v0.01-beta` | Boot loop: twelve URI handlers registered into a table sized for eight, `ESP_ERROR_CHECK` turned the ninth into `abort()` | Compiled clean, CI green. Nothing ran it. |
| `v0.02-beta` | Reset on any HTTP request: `get_status` outgrew the web server's 4 KB task stack | Same. It surfaced only when a UPS was attached and the response got longer. |
| `v0.02*` | `ups-adaptor-freenove.bin` was a **Rev A build**: the release job reused the first target's `sdkconfig` | Both assets differed by timestamp, so a byte comparison passed. Only reading the image's own identity catches it. |
| `v0.02b` | Boots and serves, but **cannot fetch its own updates**: a 512-byte header buffer could not hold GitHub's redirect | The failure is in the update path itself, so the fix cannot be delivered the usual way. |
| `v0.06` (first tag) | Both images said **`v0.06-rc2`**: tagged on the commit the candidate was already on, and `git describe` picked the rc tag. Pulled back to a prerelease within minutes, before any download | The version gate had never worked: it grepped esptool for the wrong label in a file that no longer existed, read nothing, and treated nothing as a match. |
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

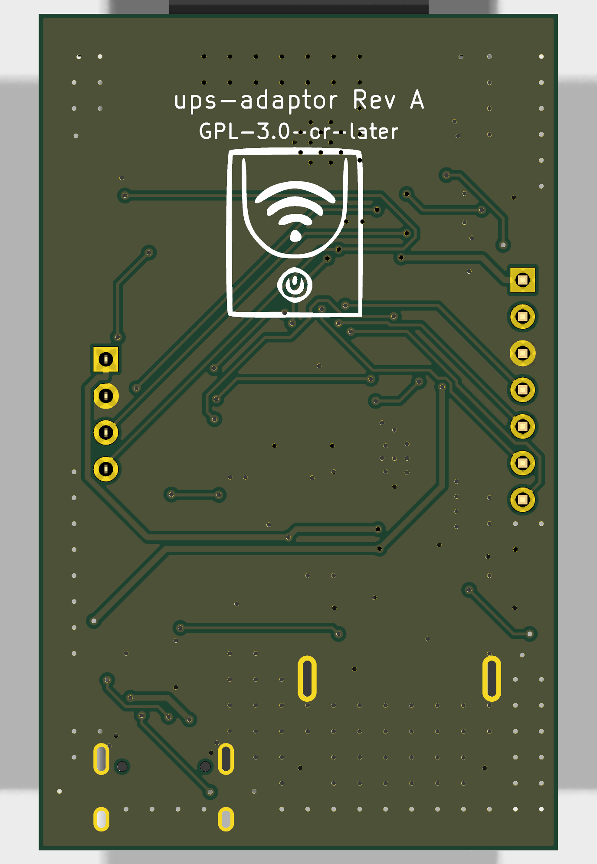
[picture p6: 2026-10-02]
docs/img/board-bottom.png

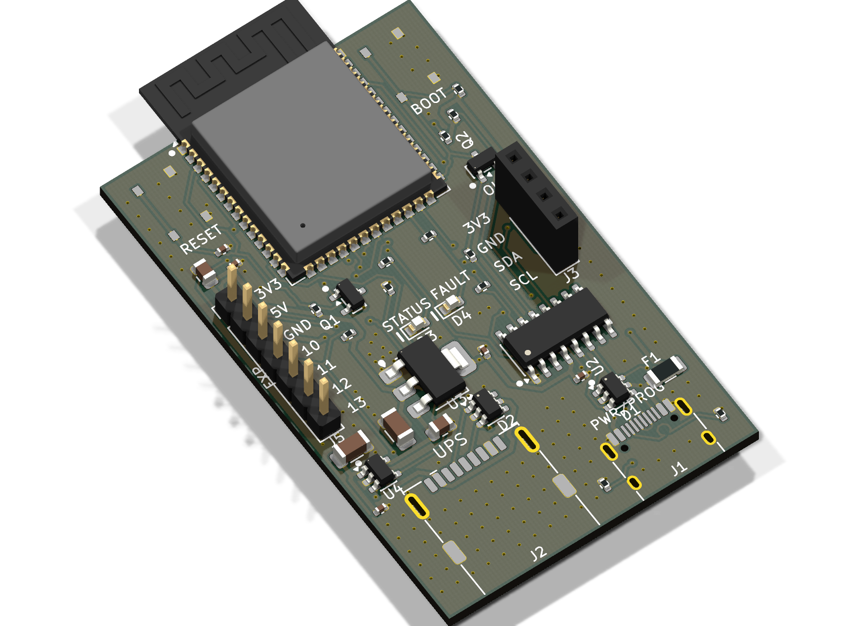
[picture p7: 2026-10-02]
docs/img/board-iso.png

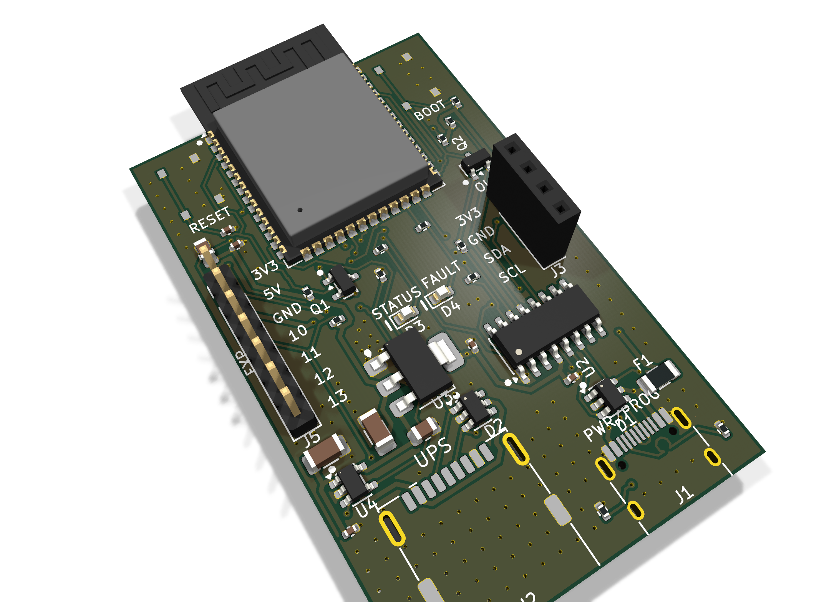
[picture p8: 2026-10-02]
docs/img/board-hero.png

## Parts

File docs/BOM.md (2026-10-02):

# Bill of materials

Prices are LCSC's at quantity 10, checked against a live product page for
every line. **They move** -- treat them as an order of magnitude, not a quote.

## Verified

| Ref | Part | LCSC | Qty 10 | Stock | Ext |
|---|---|---|---|---|---|
| U1 | ESP32-S3-WROOM-1-**N4** | `C2913197` | **$2.93** | 5,063 | $2.93 |
| U2 | CH340C | `C84681` | $0.50 | 44,411 | $0.50 |
| U3 | **AP2114H**-3.3 SOT-223 (450 mV dropout) | `C150716` | $0.062 | 22,365 | $0.06 |
| U4 | AP2171W**G-7** SOT-23-5 (active-high EN) | `C110466` | $0.092 | 31,475 | $0.09 |
| D1, D2 | USBLC6-2SC6 SOT-23-6 | `C7519` | $0.176 | 31,255 | $0.35 |
| J1 | TYPE-C-31-M-12, 16P | `C165948` | $0.097 | 202,380 | $0.10 |
| J2 | XKB U231-091N-4BLRA00-S USB-A (USB 3.0 9P, used as 2.0) | `C2880618` | $0.14 | 2,420 | $0.14 |
| Q1, Q2 | MMBT3904 SOT-23 | `C20526` | ~$0.01 | - | $0.02 |
| SW1, SW2 | XKB TS-1187A-B-A-B tact switch | `C318884` | Basic | - | ~$0.04 |
| D3 | KENTO KT-0603**Y** yellow | `C2287` | Basic | 91,450 | ~$0.01 |
| D4 | KENTO KT-0603R red | `C2286` | Basic | - | ~$0.01 |
| F1 | PTTC SMD1206P200TF, 2 A hold / 3.5 A trip | `C545216` | $0.038 | - | $0.04 |

### Passives

Pinned deliberately, because JLC's matcher resolved every resistor line to an
01005. Each is JLC Basic, stocked in the millions, and **imperial** 0402: metric
1005, which is what `R_0402_1005Metric` means and is twice the length of
the metric-0402 parts the matcher chose.

| Ref | Value | LCSC | Part | Size |
|---|---|---|---|---|
| R1, R2, R7, R8 | 1 k ±1% | `C11702` | 0402WGF1001TCE | 0402 imperial |
| R3, R4, R12 | 10 k ±1% | `C25744` | 0402WGF1002TCE | 0402 imperial |
| R5, R6 | 4.7 k ±1% | `C25900` | 0402WGF4701TCE | 0402 imperial |
| R9, R10 | 5.1 k ±1% | `C25905` | 0402WGF5101TCE | 0402 imperial |
| R11 | 100 k ±1% | `C25741` | 0402WGF1003TCE | 0402 imperial |
| C3, C6, C9, **C8** | 100 nF 16 V X7R | `C1525` | CL05B104KO5NNNC | 0402 imperial |
| C1 | 1 µF **25 V** X5R | `C52923` | CL05A105KA5NQNC | 0402 imperial |
| C4, **C5** | 22 µF **25 V** X5R | `C45783` | CL21A226MAQNNNE | 0805 |
| C2, C7 | 100 µF 6.3 V X5R | `C15008` | CL31A107MQHNNNE | 1206 |

Three lines are deliberately one part serving two specifications, which is one
fewer unique part on the order:

- **C8** is specified 100 nF 25 V but sits on VBUS_A, a 5 V rail. A 16 V X7R is
 3.2× margin, so it shares C3/C6/C9's part.
- **C5** is specified 22 µF 6.3 V on +3V3 and **C4** 22 µF 16 V on +5V. One
 25 V part in the same 0805 covers both, and holds *more* capacitance under
 DC bias than either, so the derating in `test_power.py` is now pessimistic
 rather than optimistic.
- **C1** is specified 16 V; the Basic 0402 1 µF is 25 V.

## Two parts where the suffix is the whole specification

`U3` and `U4` each have a sibling that shares the package, the pinout drawing and
most of the part number, and would destroy the board:

| Order | Never | What the wrong one does |
|---|---|---|
| **AP2114H**-3.3TRG1 `C150716` | AP2114**HA**-3.3TRG1 `C460314` | HA is pin 1 VIN, pin 2 GND: puts the input rail on ground |
| **AP217**1W `C110466` | AP216**1**W `C176957` | AP2161 has an active-LOW enable: the UPS never powers up |

Both are stocked at LCSC, so a search by package or description reaches the wrong
one. `tools/test/test_bom.py` pins both LCSC codes and fails if either changes.

## Capacitor voltage ratings

Every capacitor value now carries its rating, because leaving it off hands the
choice to JLC's matcher and on a 5 V rail the cheapest 1206 it reaches for is
6.3 V. Two separate things depend on this:

**Reliability.** A ceramic on a 5 V rail wants 16 V or better: USB VBUS is
5 V +5%, and an unplugged cable's inductance rings on top of that.

**Capacitance.** Class-II ceramics lose capacitance under DC bias, worst near
their rating. A 100 µF 6.3 V X5R is about 48 µF at 3.3 V and nearer 38 µF at
5 V. Every figure on the schematic is a nominal; `tools/test/test_power.py`
derates before judging anything.

**C7 is the one compromise.** It is the USB host port's bulk, where effective
capacitance is what matters, and JLC's Basic library has no 1206 above 6.3 V at
this value: a 25 V part in the same package is 22 µF, which after derating is
*less* capacitance than the 6.3 V part. So C7 runs at 79% of its rating, giving
about 38 µF against the 120 µF USB nominally asks of a host port.

That is accepted rather than overlooked. The inrush a device draws on insertion
is bounded by the load switch's 1.5 A limit, not by this capacitor, and nothing
is enumerated at the moment of insertion for a droop to disturb. If a UPS ever
fails to enumerate on plug-in, a second 100 µF in parallel is the first thing to
try; there is room beside C7.

## Not yet verified

The switches, LEDs and fuse used to be listed here with no part numbers. That
was worse than it looks: `RESET`, `green` and `2A hold` are not values JLC's
matcher can resolve, so those lines would have been silently dropped from the
assembly order, and the buttons sat on an E-Switch land pattern that nothing
orderable had been checked against. They now have real parts, above, and the
buttons use KiCad's own footprint for the XKB switch.

**The upload files are `hardware/bom/bom.csv` and `hardware/bom/cpl.csv`**,
regenerated by every build from the schematic's own table. The hand-exported
BOM that used to sit there went stale and still named the AP2161W, the N8
module and a 500 mA fuse when it was finally read.

| Ref | Part | Note |
|---|---|---|
| J3, J5 | 2.54 mm socket and header | Through-hole. Economic PCBA does fit THT, but by hand: $3.50 labour plus $0.0173 a joint. 11 joints, so a few dollars on the order or solder them yourself |
| 16 × passives | 0402/0805/1206 R and C | Basic, roughly $0.15 the set |

## What this costs, honestly

Board subtotal came to roughly $6.00 on the N8, against the $4.43 previously recorded;
on the N4 it is roughly **$4.70**.
Almost all of the difference is the module: **$4.23, not $2.90**. At that price
**U1 is about 70% of the bill of materials** and everything else is noise.

The old figures were inherited estimates and had never been checked against a
live page. They are now.

## The N8-to-N4 change (taken )

| Module | LCSC | Qty 10 | Stock |
|---|---|---|---|
| ESP32-S3-WROOM-1-**N8** (8 MB) | `C2913198` | $4.23 | 984 |
| ESP32-S3-WROOM-1-**N4** (4 MB) | `C2913197` | **$2.93** | 5,063 |

**$1.30 per board, about 21% of the BOM**, and five times the stock. **Taken.**
Board subtotal is now roughly **$4.70**.

Does 4 MB fit? The application binary is **766 KB**. A 4 MB part leaves roughly
3.87 MB after the bootloader, partition table, NVS, otadata and PHY data, which
takes two **1.8 MB** OTA slots comfortably: 2.3× headroom on today's firmware,
with NUT dispatch, MQTT and the remaining web endpoints still to come. Those are
small code, not megabytes.

CLAUDE.md fixes the part at N8 and justifies it as "8 MB of flash covers two OTA
app slots plus a filesystem". **There is no filesystem**: it was removed as
unused and the space left unallocated, so half that justification no longer
holds. The decision is still a decision, and it is not mine to reopen: it trades
future headroom for 21% of the BOM.

## Polyfuse sized against the switch, not against normal draw: fixed

The AP2171W's current limit is **fixed at 1 A**, confirmed from its LCSC listing.
The polyfuse was 1 A hold. Those two being equal was the wrong way round:

- A shorted UPS makes the switch limit at 1 A.
- That 1 A flows through the polyfuse, on top of the board's own ~400 mA.
- 1.4 A through a 1 A-hold fuse trips it, given time and a warm closet.

So a fault on the UPS port would have taken down the **whole bridge**, which is
exactly what the load switch exists to prevent.

**Raised to 2 A hold**, giving 43% margin over the 1.4 A fault case; 1.5 A would
have been only 7%, and hold derates with temperature. It still trips near 4 A,
well inside what a dead short on the 5 V rail draws. Basic-library part; the
change cost nothing. `tools/test/test_power.py` now asserts the relationship, so
changing the switch or the fuse without checking the other fails the harness.

## Before ordering

1. ~~Choose the USB-A receptacle~~: done, XKB `C2880618`.
2. ~~Decide N8 or N4~~: done, N4.
3. ~~Raise the polyfuse~~: done, 2 A hold.
4. Confirm **Basic vs Extended** for every line. JLC charges **$3.07 per unique
 extended part per order**, which at these quantities rivals the parts
 themselves. Their site renders this only in a browser, so it could not be
 checked from here: it needs a human with the parts library open.

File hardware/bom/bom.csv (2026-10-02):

Comment | Designator | Footprint | LCSC Part #
1uF 16V | C1 | C_0402_1005Metric | C52923
100uF 6.3V | C2,C7 | C_1206_3216Metric | C15008
100nF 16V | C3,C6,C9 | C_0402_1005Metric | C1525
22uF 16V | C4 | C_0805_2012Metric | C45783
22uF 6.3V | C5 | C_0805_2012Metric | C45783
100nF 25V | C8 | C_0402_1005Metric | C1525
USBLC6-2SC6 | D1,D2 | SOT-23-6 | C7519
yellow | D3 | LED_0603_1608Metric | C2287
red | D4 | LED_0603_1608Metric | C2286
2A hold | F1 | Fuse_1206_3216Metric | C545216
USB-C sink | J1 | USB_C_Receptacle_HRO_TYPE-C-31-M-12 | C165948
USB-A host (right-angle) | J2 | USB_A_Receptacle_XKB_U231-091N-4BLRA00-S | C2880618
MMBT3904 | Q1,Q2 | SOT-23 | C20526
1k | R1,R2,R7,R8 | R_0402_1005Metric | C11702
10k | R3,R4,R12 | R_0402_1005Metric | C25744
4.7k | R5,R6 | R_0402_1005Metric | C25900
5.1k | R9,R10 | R_0402_1005Metric | C25905
100k | R11 | R_0402_1005Metric | C25741
RESET | SW1 | SW_Push_1P1T_XKB_TS-1187A | C318884
BOOT | SW2 | SW_Push_1P1T_XKB_TS-1187A | C318884
ESP32-S3-WROOM-1-N4 | U1 | ESP32-S3-WROOM-1 | C2913197
CH340C | U2 | SOIC-16_3.9x9.9mm_P1.27mm | C84681
AP2114H-3.3 | U3 | SOT-223-3_TabPin2 | C150716
AP2171W | U4 | SOT-23-5 | C110466

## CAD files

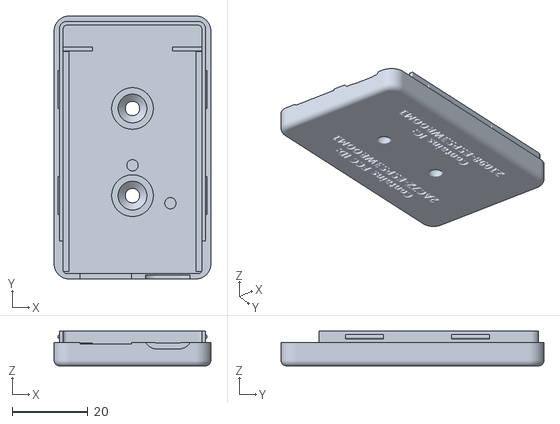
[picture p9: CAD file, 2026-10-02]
hardware/enclosure/ups-adaptor-tray-wall.stl
41.4 x 69.4 x 9.20

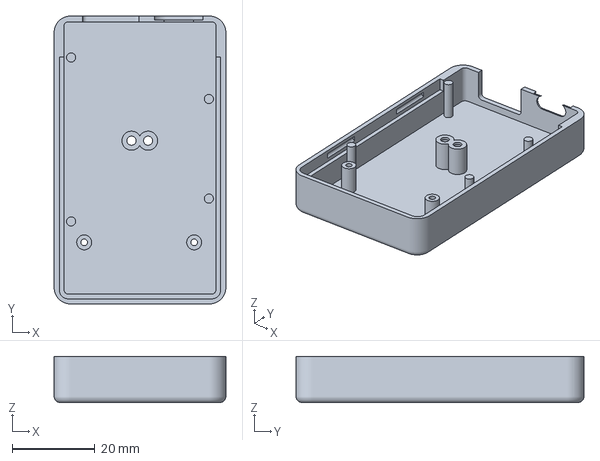
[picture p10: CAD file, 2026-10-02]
hardware/enclosure/ups-adaptor-cover-noname-labelled.3mf
41.4 x 69.4 x 11.1 mm

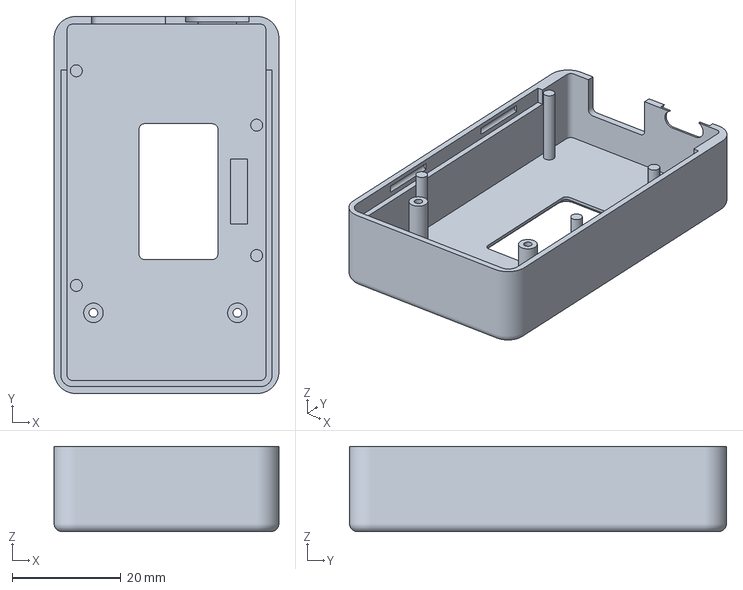
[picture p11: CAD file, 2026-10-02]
hardware/enclosure/ups-adaptor-cover-oled-noname-labelled.3mf
41.4 x 69.4 x 15.7 mm

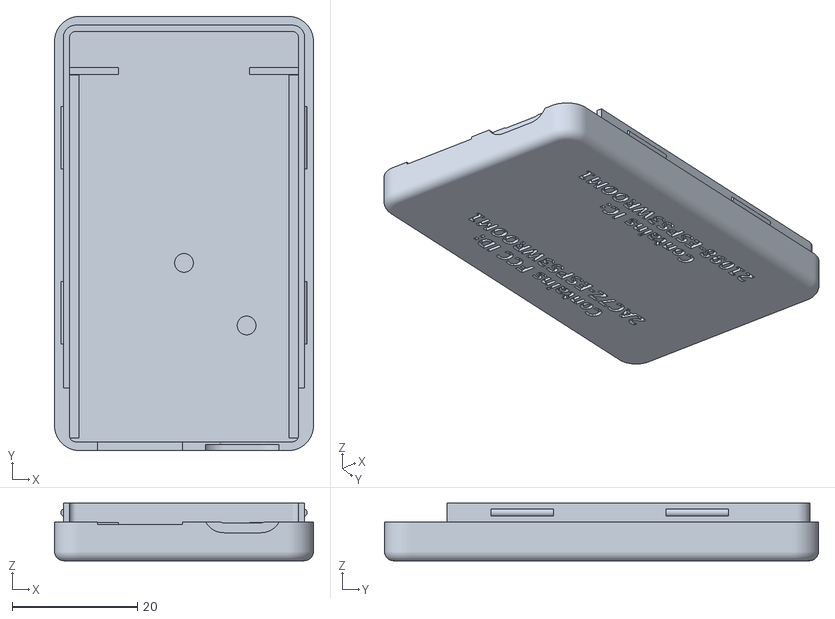
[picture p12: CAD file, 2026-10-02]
hardware/enclosure/ups-adaptor-tray.stl
41.4 x 69.4 x 9.20

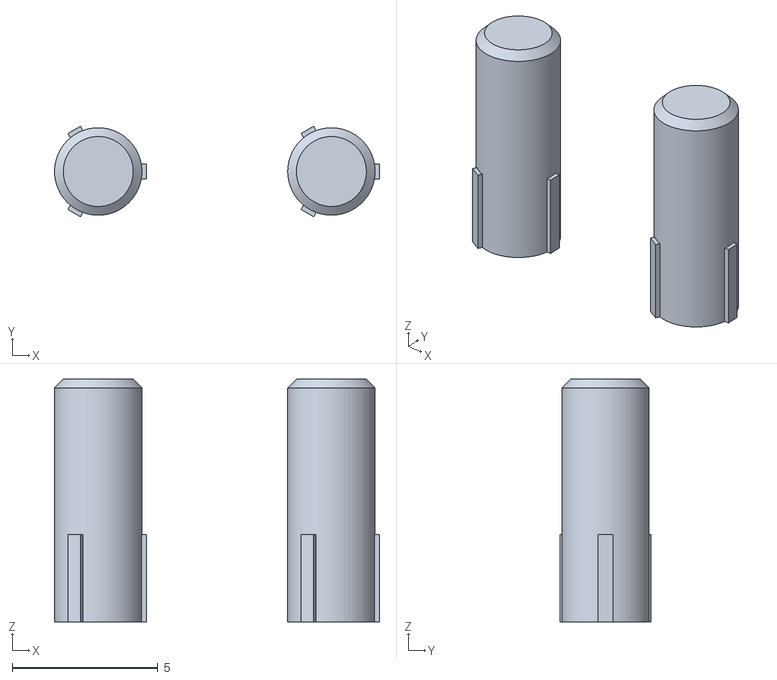
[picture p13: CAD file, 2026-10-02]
hardware/enclosure/ups-adaptor-lightpipes.stl
11.1 x 3.11 x 8.33

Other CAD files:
hardware/enclosure/ups-adaptor-cover-blank.stl
hardware/enclosure/ups-adaptor-cover-oled-blank.stl
hardware/enclosure/ups-adaptor-cover-labelled.3mf
hardware/enclosure/ups-adaptor-cover.stl
hardware/enclosure/ups-adaptor-cover-oled.stl
hardware/enclosure/ups-adaptor-cover-noname.stl
hardware/enclosure/ups-adaptor-cover-oled-noname.stl
hardware/enclosure/ups-adaptor-cover-oled-labelled.3mf

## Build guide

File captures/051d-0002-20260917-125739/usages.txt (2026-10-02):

   0.000044	Error: you must specify a port name in ups.conf or in '-x port=...' argument.

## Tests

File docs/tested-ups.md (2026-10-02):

# Tested UPSes

This page sorts UPSes into three groups by the evidence behind them, and says
which is which:

- **Tested on hardware.** A unit on the bench, read by the board, with the
  evidence in `captures/`. Three models.
- **Checked against its real descriptor.** A report descriptor from that
  model, published by its owner on the Network UPS Tools issue tracker, read by
  the board's own parser in the test suite: charge, runtime and on-mains /
  on-battery status are all found, and every value NUT itself decoded from the
  same UPS's logs matches ours. Strong evidence, not a bench test. 56 of 65.
- **Not supported.** UPSes that do not speak USB HID at all, but a serial
  protocol carried over USB. The board cannot read these.

Anything not listed is untested. Most USB HID UPSes should work, because the
board reads each UPS's own description of itself rather than a list of models.
If yours does not, the page's "Send my UPS info to the developer" button sends
exactly what is needed to fix it.

## Tested

| UPS | USB ID | Descriptor | Fields | Status |
|---|---|---|---|---|
| APC Back-UPS RS 1000G | `051d:0002` | 1133 B | 86 | **Working**: full read, 16 plug cycles, a real transfer to battery and back |
| CyberPower EC850LCD | `0764:0501` | 496 B | 36 | **Working**: full read, all four control groups, the project's primary target |
| APC Back-UPS ES 600M1 (BE600M1) | `051d:0002` | 1049 B | 86 | **Working from v0.12**: full read, a load change, a real transfer to battery and back. Before v0.12 it restarted the board every 1.5 s (it answers a feature request with a longer packet than asked for) |

All three are read by the same generic code path, with no model-specific code.

### What each one reports

| NUT variable | APC RS 1000G | CyberPower EC850LCD |
|---|---|---|
| `battery.charge` | yes | yes |
| `battery.runtime` | yes | yes |
| `battery.charge.low` | yes | yes (writable) |
| `battery.voltage` | yes | **from v0.14.3**: read from `UPS.PowerSummary.Voltage`, as NUT does; not yet re-checked on this unit |
| `input.voltage` | yes | yes |
| `output.voltage` | - | yes |
| `input.frequency` | - | **no**: `Frequency` absent from the descriptor |
| `ups.load` | yes | yes |
| `ups.realpower.nominal` | yes | yes (510 W) |
| `ups.realpower` | estimated | **no** instantaneous value in the descriptor |
| `ups.status` | `OL`, `OB`, `DISCHRG`, `CHRG` observed | `OL`, `OL DISCHRG` (self-test) observed |
| `ups.beeper.status` | yes | yes |
| `ups.test.result` | yes | yes |
| `battery.date` | yes | **no**: `ManufacturerDate` (0x85,0x85) absent |

Commands offered are discovered from each descriptor, never assumed. The
EC850LCD offers quick test, deep test, stop test, beeper enable/disable/mute
and `load.off`; its `caps` word reads 15, i.e. TEST | BEEPER | LOWBATT |
SHUTDOWN with BATTDATE clear.

### What the commands actually do

Offering a command and honouring it are different things, so each one is
measured on the real unit rather than read off the descriptor.

| Command | APC RS 1000G | CyberPower EC850LCD |
|---|---|---|
| `test.battery.start.quick` | **works**: starts ~10 s after the command, ~8 s on battery, "Done and passed" | **works**: ~4 s on battery, then "Done and passed" |
| `test.battery.start.deep` | **works, but hides**: ran 40 min, 100 → 22 %, then passed; its USB reports froze at "on mains, 100 %, no test" until the USB was power-cycled | **runs the quick test instead**: ~4 s, "Done and passed", charge 100 → 99 % |
| `test.battery.stop` | **no visible effect**: sent mid quick test, which still ran its full ~8 s and passed | not yet measured |

The EC850LCD has a single test control (Output → Test, `0x84:0x58`) and no
runtime-calibration usage anywhere in its descriptor. Writing 2 ("deep") is
accepted and reported as a pass, but the unit runs its normal short self-test.
NUT's `cps-hid` writes the same value to the same control, so NUT on a host
gets the same result. A second EC850LCD, at another site and with 0 % load,
did the same on 2026-09-27: its deep test was over within about two minutes,
charge back at 100 % and "passed". Its descriptor is byte-identical to the
first unit's; it was not re-checked across a USB power cycle.

**The web page now says so.** A table in the page (`DEEP_KNOWN`) records what
each tested model does: on an EC850LCD the Deep test button is disabled with
the reason beside it; on the APC RS 1000G the confirm box says it takes about
40 minutes to ~22 % and that the reports may freeze. For any other UPS the page
watches the test: finished inside three minutes means "this UPS ran its short
self-test instead", and no sign of a start after 75 s means "press Power-cycle
UPS link to see what it is really doing". A newly measured model is one line in
that table. **There is no deep test on this model over USB.**

While testing, it keeps reporting mains present and raises only discharging:
`ups.status` reads `OL DISCHRG`, never `OB`, with `ups.test.result` "In
progress". Evidence: `captures/0764-0501-ec850lcd-selftest-20260927`.

**The APC's deep test is real; the CyberPower's is not.** The CyberPower was
checked three ways: its own reports, two USB power cycles forcing fresh reads,
and someone watching it return to mains after four seconds. CyberPower's own
documents agree: the EC850LCD manual, PowerPanel Personal and `pwrstat` offer
one self-test; "Runtime Calibration" appears only in PowerPanel Business
Edition, for the managed lines.

APC doesn't document a deep test on the RS 1000G either (manual and PowerChute
Personal: self-test only), but writing 2 to Test starts a real run-down, which
NUT's `apc-hid` and apcupsd both rely on. apcupsd clears the old result first
(abort, then 0), refuses below 100 % charge or 10 % load, and expects the UPS
to stop at about 25 %. Ours stopped at 22 % after about 40 minutes at 10 % load.

**The APC's reports froze during it.** For about 15 minutes the board, polling
fresh feature reports every cycle, was told "on mains, 100 %, No test
initiated" while the battery was draining. A USB power cycle from the page
(the VBUS switch) made it re-enumerate and report the truth: `OL DISCHRG`, "In
progress", 83 %. Nobody has published exactly this; the nearest are an RS 800
shown `OL` while visibly on battery during a deep test (nut-upsuser, 2009),
units reporting `OFF` briefly at the start of a test (NUT #2388, #2104), and a
BX1200MI whose charge stuck until the cable was replugged (NUT #2805). A real
outage during such a freeze would be reported as mains, so this matters beyond
testing. A user report, not APC, says the RS then refuses another deep test
until fully recharged.

**The USB standard does not say what "deep" means.** The HID Power Device
usage tables define Test's write values (0 none, 1 quick, 2 deep, 3 abort) and
read values (1 passed … 5 in progress, 6 no test initiated) and nothing more;
"calibration" appears nowhere in them. Every NUT HID subdriver writes 2 and
none implements `calibrate.start`. What a deep test does is the vendor's
choice, which is why the two units here differ.

**Status glitches around tests.** The EC850LCD reported no status bits at all
for about two minutes after a test and USB cycle, which this firmware's NUT
server shows as `OFF`. NUT had the same class of problem on APC RS units
(#2104: `OFF` at test start tripped `upsmon`), fixed by acting on `OFF` only
if it persists and by treating `OL DISCHRG` as calibration.

Evidence: `captures/051d-0002-selftest-20260927`,
`captures/0764-0501-ec850lcd-selftest-20260927`. Sources:
[HID Power Device usage tables](https://www.usb.org/sites/default/files/pdcv10.pdf),
[nut-upsuser 2009](https://alioth-lists.debian.net/pipermail/nut-upsuser/2009-October/005506.html),
[NUT #2104](https://github.com/networkupstools/nut/issues/2104),
[NUT #2388](https://github.com/networkupstools/nut/issues/2388),
[NUT #2805](https://github.com/networkupstools/nut/issues/2805),
[NUT #643](https://github.com/networkupstools/nut/issues/643),
[PowerPanel Personal for Windows](https://dl4jz3rbrsfum.cloudfront.net/documents/CyberPower_UM_PowerPanel-Personal-Windows-v2.4.6.pdf),
[EC850LCD manual](https://dl4jz3rbrsfum.cloudfront.net/documents/CyberPower_UM_EC850LCD.pdf).

### Battery replacement date

Worth stating plainly because it is a feature people look for: **the EC850LCD
cannot store one.** The usage is absent from its report descriptor, so there is
nowhere on the UPS to write it and nothing to read back. The firmware detects
this and does not offer the control. The APC does carry the field.

## Supported but not yet tested: Tripp Lite

Tripp Lite has two USB interfaces, and the firmware now handles both. **Neither
has been run against a real Tripp Lite yet**; both are ports of Network UPS
Tools, which does run on them.

- **Standard HID** (current models: AVR, ECO, INTERNET, OMNI, SMART, SMX, SU;
  USB ID `09ae:` + the protocol number, e.g. `2010`, `3015`). The generic
  parser reads these. `ups_profiles.c` adds NUT's `tripplite-hid.c` corrections:
  battery voltage x0.1 on protocols 1xxx-2xxx, the SMART1500LCDT scaling on
  3016/3024, a chemistry-string workaround on 1003 and 2005, and status flags
  moved back to the Battery System page where a unit (OMNI1000LCD) misplaces
  them -- without which such a unit would never be seen on battery.
- **Legacy protocol** (older OMNIVS, SMARTPRO, some SMART and INTERNETOFFICE
  revisions; USB ID `09ae:0001`). A vendor protocol, not HID Power Device: short
  commands by SET_REPORT, replies on the interrupt endpoint. `tripplite_legacy.c`
  ports NUT's `tripplite_usb.c` decoding for all six protocol variants (1001,
  2001, 3003, 0004, 3005, 3017), and turns the UPS's watchdog off at start-up as
  NUT does. It reports status, battery voltage, input and output voltage,
  frequency and load; **battery charge is estimated from voltage**, because
  these units do not report it. Controls (self-test, beeper, shutdown) are not
  ported. `tools/test/test_tripplite_legacy.py` checks the decoding against the
  example replies NUT documents from real units.

  Before this, a legacy unit parsed to zero fields, failed every poll, and sent
  the board into its VBUS recovery loop, power-cycling the UPS's USB port on a
  backoff indefinitely.

Not ported: NUT reads Tripp Lite's `UPS.PowerSummary.Voltage` as output voltage,
where APC uses the same path for battery voltage. That needs a capture to
settle, not a guess.

## Known vendor quirks

**CyberPower scaling.** This page used to say several CyberPowers report
`output.voltage` ten times wrong and that NUT patches it. Reading NUT's
`cps-hid.c` shows otherwise: NUT has no output-voltage correction. What it does
have, and what the board now does the same way from v0.14.3, applies only to
USB ID `0764:0501`: battery voltage is scaled by 2/3 when the first reading is
more than 1.4 times the nominal, and frequency by 0.1 when it reads in tenths of
a hertz. Battery charge is capped at 100 %. The EC850LCD tested here needed
none of it: 120.0 V against a 120 V supply.

## Checked against its real descriptor

Each row is a report descriptor from one model, published by its owner in a
Network UPS Tools issue (linked), and checked on every change by
`tools/test/test_nut_descriptors.py`, `test_vars.py` and `test_vectors.py`, the
last of which compares every value NUT decoded from that UPS's own logs with
the board's (none disagree). Not tested on hardware: the board has never been
plugged into one of these.

| USB ID | Model | Extra variables | Status logic | Source |
|---|---|---|---|---|
| `0463:ffff` | 5E | 17 | NUT's | [issue](https://github.com/networkupstools/nut/issues/515) |
| `0463:ffff` | Eaton (ups.model reported as 'unknown 2000') | 47 | NUT's | [issue](https://github.com/networkupstools/nut/pull/2562) |
| `0463:ffff` | Eaton 3S 700 | 21 | NUT's | [issue](https://github.com/networkupstools/nut/issues/2887#issuecomment-3764113336) |
| `0463:ffff` | Eaton 5SC 1500i R | 42 | NUT's | [issue](https://github.com/networkupstools/nut/issues/1513) |
| `0463:ffff` | Eaton 5SC 750 | 42 | NUT's | [issue](https://github.com/networkupstools/nut/issues/2380#issuecomment-2108986084) |
| `0463:ffff` | Eaton 9PX 2200GRT-L | 25 | NUT's | [issue](https://github.com/networkupstools/nut/issues/3295) |
| `0463:ffff` | Protection Station Protection Station | 23 | NUT's | [issue](https://github.com/networkupstools/nut/issues/1286) |
| `0463:ffff` | Ellipse ECO | 23 | NUT's | [issue](https://github.com/networkupstools/nut/issues/1507#issuecomment-1229544307) |
| `04b3:0001` | IBM 1000VA/750W Tower UPS | 44 | NUT's | [issue](https://github.com/networkupstools/nut/issues/778#issuecomment-819955904) |
| `051d:0002` | Back-UPS 500 | 10 | NUT's | [issue](https://github.com/networkupstools/nut/issues/1776#issuecomment-1373586808) |
| `051d:0002` | Back-UPS BX1600MI | 20 | NUT's | [issue](https://github.com/networkupstools/nut/issues/1208) |
| `051d:0002` | Back-UPS ES 850G2 | 21 | NUT's | [issue](https://github.com/networkupstools/nut/issues/1304) |
| `051d:0002` | Back-UPS ES 850M2 | 21 | NUT's | [issue](https://github.com/networkupstools/nut/issues/2996) |
| `051d:0002` | Back-UPS XS 1400U | 21 | NUT's | [issue](https://github.com/networkupstools/nut/issues/1189) |
| `051d:0002` | Back-UPS XS 1500M | 21 | NUT's | [issue](https://github.com/networkupstools/nut/issues/2827#issuecomment-2693258810) |
| `051d:0002` | Smart-UPS 1000 | 24 | NUT's | [issue](https://github.com/networkupstools/nut/issues/2441) |
| `051d:0002` | Smart-UPS 1500 RM | 25 | NUT's | [issue](https://github.com/networkupstools/nut/issues/2695#issuecomment-2501915179) |
| `051d:0003` | Smart-UPS 3000 (product Smart-UPS_3000) | 13 | NUT's | [issue](https://github.com/networkupstools/nut/issues/2954) |
| `051d:0003` | Smart-UPS SRT 3000 RMXL (title: APC SRT3000RMX.. | 13 | NUT's | [issue](https://github.com/networkupstools/nut/issues/1072) |
| `051d:0003` | Smart-UPS X 750 | 13 | NUT's | [issue](https://github.com/networkupstools/nut/issues/1261#issuecomment-1038451781) |
| `05dd:a011` | ED2000RM2U | 26 | NUT's | [issue](https://github.com/networkupstools/nut/issues/3152) |
| `05dd:a0a0` | MINUTEMAN UPS | 17 | NUT's | [issue](https://github.com/networkupstools/nut/pull/1848#issuecomment-1429053267) |
| `0665:5161` | Legrand Keor DK 3k | 12 | fixed | [issue](https://github.com/networkupstools/nut/issues/3702) |
| `06da:ffff` | PowerWalker VFI 2000 RT HID (product HID UPS I.. | 47 | NUT's | [issue](https://github.com/networkupstools/nut/issues/1114) |
| `06da:ffff` | PowerWalker VI 1200 SHL / VI 2200 SHL (product.. | 15 | NUT's | [issue](https://github.com/networkupstools/nut/issues/1270) |
| `06da:ffff` | PowerWalker VI 3000 RT HID (product HID UPS) | 43 | NUT's | [issue](https://github.com/networkupstools/nut/issues/1824#issuecomment-1402393035) |
| `075d:0300` | Smart-Battery | 14 | NUT's | [issue](https://github.com/networkupstools/nut/issues/3015#issuecomment-3155681144) |
| `0764:0501` | CP 1500C | 21 | NUT's | [issue](https://github.com/networkupstools/nut/issues/2997) |
| `0764:0501` | CP1300EPFCLCD | 22 | NUT's | [issue](https://github.com/networkupstools/nut/pull/1245) |
| `0764:0501` | CP1500AVRLCDa | 25 | NUT's | [issue](https://github.com/networkupstools/nut/issues/439#issuecomment-1011420900) |
| `0764:0501` | CP1500PFCLCD | 22 | NUT's | [issue](https://github.com/networkupstools/nut/issues/2642#issuecomment-2378074359) |
| `0764:0501` | CP900EPFCLCD | 22 | NUT's | [issue](https://github.com/networkupstools/nut/issues/437#issuecomment-1238306455) |
| `0764:0501` | ST Series | 22 | NUT's | [issue](https://github.com/networkupstools/nut/issues/2439#issuecomment-2111210355) |
| `0764:0501` | VP1600ELCD | 22 | NUT's | [issue](https://github.com/networkupstools/nut/issues/3557) |
| `0764:0601` | CP1000PFCLCDa | 25 | NUT's | [issue](https://github.com/networkupstools/nut/issues/439) |
| `0764:0601` | CPS 0764:0601 unit reporting product ' 600' (m.. | 23 | NUT's | [issue](https://github.com/networkupstools/nut/pull/2718) |
| `0764:0601` | OL1000EXL | 23 | NUT's | [issue](https://github.com/networkupstools/nut/issues/982) |
| `0764:0601` | OR2200LCDRT2U | 22 | NUT's | [issue](https://github.com/networkupstools/nut/issues/2791#issuecomment-2622693904) |
| `0764:0601` | OR600ERM1U | 25 | NUT's | [issue](https://github.com/networkupstools/nut/issues/2728) |
| `0764:0601` | PowerWalker VI 500 R1U (CPS OEM, product 500R) | 23 | NUT's | [issue](https://github.com/networkupstools/nut/issues/1512#issuecomment-2199747873) |
| `0764:0601` | PowerWalker VI 750 (CPS OEM, product 750R) | 23 | NUT's | [issue](https://github.com/networkupstools/nut/issues/645) |
| `0764:0601` | PR3000ELCDSL | 24 | NUT's | [issue](https://github.com/networkupstools/nut/issues/3089) |
| `09ae:3016` | TRIPP LITE UPS (USB product string; model not .. | 19 | NUT's | [issue](https://github.com/networkupstools/nut/issues/414) |
| `09ae:4003` | TRIPP LITE UPS (USB product string; model not .. | 26 | NUT's | [issue](https://github.com/networkupstools/nut/issues/1268) |
| `0d9f:0004` | HID UPS Battery | 17 | NUT's | [issue](https://github.com/networkupstools/nut/issues/1695) |
| `10af:0002` | Liebert PSA5 | 13 | NUT's | [issue](https://github.com/networkupstools/nut/issues/2816) |
| `10af:0002` | Liebert PSI5 | 13 | NUT's | [issue](https://github.com/networkupstools/nut/issues/2271#issuecomment-1976540478) |
| `10af:1000` | GXT5 | 5 | NUT's | [issue](https://github.com/networkupstools/nut/issues/3613) |
| `1cb0:0032` | Legrand UPS | 20 | NUT's | [issue](https://github.com/networkupstools/nut/issues/3540) |
| `1cb0:0038` | Legrand KEOR PDU 800 | 24 | NUT's | [issue](https://github.com/networkupstools/nut/pull/1138) |
| `2e66:0201` | SLC TWIN PRO2<=3KVA | 18 | NUT's | [issue](https://github.com/networkupstools/nut/issues/1312#issuecomment-1055098137) |

"Extra variables" counts the NUT variables from NUT's own table for that make
that the board found in the descriptor. "Status logic" is NUT's where that
table reports the power state, else the board's own.

The other 9 of the 65: five are not UPS descriptors (two serial tunnels, two
vendor-only interfaces, one corrupted capture), and four are UPSes whose
descriptor lacks one of charge, runtime or status as a readable value (a
Liebert GXT4, a 33-byte Eaton Ellipse ECO capture, a `09d6:0001` unit with
runtime only as an interrupt report, and `5131:2007`).

## Not supported: serial over USB

Many inexpensive UPSes, and some larger ones, use a USB-to-serial bridge and a
text protocol (Megatec/Q1 and its relatives, Voltronic, Riello, Richcomm,
Powerware's BCM/XCP) rather than USB HID. NUT reads them with `nutdrv_qx`,
`blazer_usb`, `riello_usb`, `richcomm_usb` and `bcmxcp_usb`; this board does
not speak those protocols. NUT knows 22 USB IDs of this kind, among them
`0665:5161`, `06da:0002` to `06da:0005`, `06da:0201`, `06da:0601`,
`05b8:0000`, `0f03:0001`, `14f0:00c9`, `1a86:7523`, `0925:1234`, `04b4:5500`,
`03f0:1f01`, `03f0:1f02` and `0592:0002`.

Two IDs are shared: `0001:0000` and `0665:5161` are used both by serial units
and by real HID UPSes (a Belkin-family unit and a Legrand Keor DK 3k above).
The board decides by what the UPS says about itself, not by its ID. Tripp
Lite's older `09ae:0001` protocol is not HID either, but the board supports
it (below).

**APC Smart-UPS with Modbus.** Some Smart-UPS units on `051d:0003` report
only charge, runtime and status over HID. Their voltages, load and power are
in APC's Modbus register map instead, which NUT reads with `apc_modbus`. On
USB that map travels through two vendor reports on the same HID interface,
and the board uses them too: where a UPS's descriptor has them, it reads the
same registers NUT does and publishes `input.voltage`, `output.voltage`,
`output.current`, `output.frequency`, `ups.load`, `ups.realpower`,
`ups.power`, their nominal ratings, `battery.voltage`, `battery.temperature`
and `ups.efficiency`. HID stays the source of status, and of any value HID
also reports. The UPS answers only once Modbus is turned on in its
front-panel menu (Configuration, Modbus, Enable); until then the board asks
again every five minutes. Not yet confirmed on a real unit.

## Evidence

| Capture | What it shows |
|---|---|
| `captures/051d-0002-20260917-125739` | APC descriptor read on a Mac, decoded, with the NUT mapping |
| `captures/051d-0002-esp32-m0b` | The same descriptor read by the ESP32: byte-for-byte identical |
| `captures/051d-0002-hotplug-20260919` | 16 plug/unplug cycles, heap logged on every one |
| `captures/051d-0002-m1-values-20260919` | Live values through a transfer to battery and back |
| `captures/0764-0501-ec850lcd-20260921` | CyberPower descriptor, decoded values and a NUT session |
| `captures/051d-0002-selftest-20260927` | APC quick, deep and stop: quick ~8 s; deep 40 min to 22 %, with 15 min of frozen reports |
| `captures/0764-0501-ec850lcd-selftest-20260927` | CyberPower quick and deep both ~4 s, deep re-checked across two USB power cycles |

`tools/test/test_parser.py` runs the parser against these descriptors on the
host, so a change that breaks either unit fails in CI rather than on a shelf.

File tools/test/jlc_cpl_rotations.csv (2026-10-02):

# Vendored from JLCKicadTools | unmodified.
# https://github.com/matthewlai/JLCKicadTools
# jlc_kicad_tools/cpl_rotations_db.csv
# Copyright the JLCKicadTools contributors. Licensed GPL-3.0-or-later | the same
# licence as this project | which is what makes redistributing it here lawful.
# Kept as a copy rather than fetched so an order never depends on a URL being
# up | and so a change upstream shows as a diff.
#
# NOTE: this project no longer APPLIES this table. See docs/jlcpcb.md -- JLC's
# own assembly preview showed it rotating a SOT-23 ninety degrees the wrong
# way. It is retained for reference and for the audit in test_rotation.py.
Footprint pattern | Rotation | Offset X | "Offset Y"
^R_Array_Convex_ | 90
^R_Array_Concave_ | 90
^SOT-223 | 180
^SOT-23 | -90
^SOT-89 | 180
^TSOT-23 | 180
^SOT-353 | 180
^SOT-363 | 180
^LQFP- | 270
^TQFP- | 270
^SOP-4_ | 0
^SOP-(?!18_) | 270
^TSSOP- | 270
^SSOP- | 270
^DFN- | 270
^SOIC- | 270
^SOP-18_ | 0
^VSSOP-8_3.0x3.0mm_P0.65mm | 270
^VSSOP-8_ | 180
^VSSOP-10_ | 270
^VSON-8_ | 270
^TSOP-6 | 270
^UDFN-10 | 270
^USON-10 | 270
^TDSON-8-1 | 270
^CP_EIA- | 180
^CP_Elec_8x5.4 | 180
^CP_Elec_8x10.5 | 180
^CP_Elec_6.3x7.7 | 180
^CP_Elec_8x6.7 | 180
^CP_Elec_8x10 | 180
^CP_Elec_10x10 | 180
^(.*?_|V)?QFN-(16|20|24|28|40)(-|_|$) | 270
^Bosch_LGA-8_2x2.5mm_P0.65mm_ClockwisePinNumbering | 90
^PowerPAK_SO-8_Single | 270
^HTSSOP-28-1EP_4.4x9.7mm* | 270
^PUIAudio_SMT_0825_S_4_R* | 270
^USB_C_Receptacle_HRO_TYPE-C-31-M-12* | 180
^ESP32-W | 270
^SOIC127P798X216-8N | -90
^SW_DIP_SPSTx01_Slide_Copal_CHS-01B_W7.62mm_P1.27mm | -180
^BatteryHolder_Keystone_1060_1x2032 | -180
^SO-14 | -90
^HTSSOP- | 270
^USB_C_Receptacle_XKB_U262-16XN-4BVC11 | 0 | 1.44 | 0
^Relay_DPDT_Omron_G6K-2F-Y | 270
^RP2040-QFN-56 | 270
^TO-277 | 90
^SW_SPST_B3 | 90
^Transformer_Ethernet_Pulse_HX0068ANL | 270
^JST_GH_SM | 180
^JST_PH_S | 180
^Diodes_PowerDI3333-8 | 270
^Quectel_L80-R | 270
^SC-74-6 | 180
^SOT-143 | 180
^PinHeader_2x05_P1\.27mm_Vertical | 90 | 2.54 | 0.635
^LED_WS2812B-2020_PLCC4_2.0x2.0mm | 90
^^WSON-8-1EP_6x5mm_P1.27mm | -90

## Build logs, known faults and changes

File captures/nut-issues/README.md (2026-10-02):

# Report descriptors from NUT's issue tracker

Real USB HID report descriptors from UPSes other people own, reassembled from
`usbhid-ups` debug logs posted publicly on
[networkupstools/nut](https://github.com/networkupstools/nut) issues. Each
`.hex` file is the descriptor's bytes, in hex. `INDEX.json` records where each
one came from, the device it belongs to, how it was extracted, and its length.
Every file was checked: its byte count matches the length the log states, and
its collections open and close in balance. One (`051d-0003-smart-ups-srt3000`)
had no stated length and is kept on structure alone.

No hardware here: these are what the firmware's parser is tested against, so a
change that stops a real UPS being read fails a test instead of reaching
someone's board. `tools/test/test_nut_descriptors.py` runs them.

Six are 27-byte vendor-page descriptors, not HID Power Devices: those UPSes
speak a serial protocol tunnelled through HID, which this board does not read.

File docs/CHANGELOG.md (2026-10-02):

# Changelog

Every user-facing change lands here, under "Unreleased", in the same commit
that makes the change. Not afterward: `v0.10` shipped release notes
describing only its final `-rc`'s fix, because whoever wrote the notes
looked at the last candidate's diff instead of the whole interval since
`v0.09`. The login system, the fixed address and a USB crash fix had all
landed too and were simply left out. Writing the bullet at the same time as
the change means there is nothing left to reconstruct at release time:
`tools/release.sh` requires this section to be non-empty, and read, before it
accepts a production tag.

When a production tag ships, "Unreleased" is renamed to that version and a
fresh empty "Unreleased" goes above it. An `-rc` tag does not touch this file
beyond whatever the commits it contains have already added: its own notes are
just its build's delta, not the whole story, the same way `docs/RELEASING.md`
already treats prereleases.

## Unreleased

(nothing yet)

## v0.15.1 -- 2026-10-02

- Updates no longer crash with some UPSes attached. A board on v0.14.4 with a
  CyberPower EC850LCD rebooted every time it began downloading v0.15 -- a
  panic in the USB host driver -- so it said it was updating and never did,
  and its crash count rose by one each try. The board now pauses all USB
  traffic to the UPS for the length of an update and resumes it after; the
  UPS's readings hold their last values meanwhile. A board still on v0.14.4
  or v0.15 is running the old update code, so its update to this release can
  still crash. For that one update, press the page's button that power-cycles
  the UPS's USB link, then start the update straight away: with the link
  down, nothing is in flight while the image is written. (Unplugging the
  UPS's USB cable from the board does the same.)

## v0.15 -- 2026-10-02

- New test target: the Waveshare ESP32-P4-ETH board on PoE, a wired board with
  no Wi-Fi. Release asset `ups-adaptor-p4poe-full.bin`. It has only been run
  on the bench with no UPS attached so far.
- On a wired board the web page leaves out the Wi-Fi section and shows
  "Ethernet" in the debug panel.
- NUT no longer reports the last status it saw (for example "OL") once the UPS
  has stopped answering. Clients now get "data stale", as they would from NUT
  itself, so a power cut while the board cannot read the UPS is no longer
  hidden behind an old "on mains".
- A UPS that fails its first detection attempt is tried again, every few
  seconds and then every minute, instead of staying "not detected" until
  someone replugged it. This also covers a UPS still waking up after the board
  power-cycles its USB.
- UPSes with a large report descriptor (over 2048 bytes, such as some Eaton
  and Legrand units) are now detected. So are UPSes whose descriptor is
  shorter than they claim, which NUT accepts too.
- A reply from the UPS that is shorter than expected no longer reads as zeros.
  Before, it could briefly show "on battery" with the mains present.
- Older Tripp Lite UPSes (USB ID 09ae:0001) should now be detected: every
  query to them used to time out. Not yet tried on a real unit.
- APC Smart-UPS units that keep their voltages out of the normal USB data,
  such as the Smart-UPS C 1500, now report input and output voltage, load,
  watts, output current and frequency, battery voltage and temperature. The
  board reads them through APC's Modbus channel on the same USB cable, as
  NUT's `apc_modbus` driver does. Modbus has to be turned on in the UPS's
  front-panel menu first (Configuration, Modbus, Enable). Not yet tried on a
  real unit.
- New download at `/api/modbus`: what the board and an APC Smart-UPS said to
  each other over Modbus (the last 16 exchanges with their raw replies, the
  raw registers, and counts of answers and timeouts). Save it with
  `curl -o modbus.json http://ups-esp32-XXXX.local/api/modbus` and send it in
  if the readings look wrong.
- For an APC Smart-UPS read over Modbus, "Send my UPS info to the developer"
  now sends that Modbus capture along with the descriptor. It includes the
  UPS's readings, and the page says so. With stats ticked, the board also
  sends one capture by itself once per boot.
- A check-in the fleet server answers with an interval of zero no longer counts
  as a failed one. Before, the board backed off and "Send my UPS info" said it
  could not reach the server.
- A self-test or other command sent while the board is waiting on a slow or
  silent Smart-UPS Modbus reply now goes through at once, instead of timing
  out on the page and then running anyway.
- PeaNUT now shows the board's UPS. It asks the type of every variable
  (`GET TYPE`), which the board did not answer, and PeaNUT then listed the
  whole UPS as "Device Unreachable". `LIST ENUM` and `LIST RANGE` are
  answered too.
- If the board cannot join its saved Wi-Fi for half an hour (a mistyped
  password, or a router whose name or password changed), it opens its setup
  network for five minutes so you can put it right, then tries the saved
  network again. It keeps doing that until one works. If the board has a
  login, changing the Wi-Fi from that setup page still asks for it. Before,
  the only way back was pressing BOOT five times.
- A dropped Wi-Fi reconnect attempt is retried rather than waiting for the
  board's fifteen-minute restart.
- NUT clients that vanish without disconnecting (a NAS that lost power, a
  Wi-Fi drop) are noticed within about two minutes, not two hours. Before, a
  few of them could use up the board's connections and lock out new NUT
  clients, the web page and updates.
- NUT commands split across two network packets are now read whole. A client
  that sent many commands at once could get its answers out of order.
- upsmon running as primary no longer logs an alert on every connect: the
  board now answers PRIMARY and MASTER. LOGOUT closes the connection, and
  STARTTLS gets the same answer as NUT without a certificate.
- A UPS name, model or value containing a quote or backslash is now escaped
  for NUT clients instead of breaking the line.
- The status page could crash the board if several long error messages were
  showing at once. It now reports an error instead.
- If the USB host, the NUT server or the update service fails to start, the
  board carries on without it instead of restarting into the same failure. A
  freshly installed update that fails this way still rolls back.

## v0.14.4 -- 2026-09-30

- The board now also listens for the reports a UPS sends the moment
  something changes, as NUT does, so a switch to battery shows up straight
  away rather than at the next poll.
- Liebert UPSes now get ups.status from NUT's own logic too: on mains, on
  battery, charging, low battery, replace battery and shutdown imminent.

## v0.14.3 -- 2026-09-30

- CyberPower UPSes now report battery voltage, with NUT's own corrections:
  some CP-series units (USB ID 0764:0501) report battery voltage 1.5 times
  too high and frequency in tenths of a hertz, and the board now fixes both
  as NUT does. Battery charge is capped at 100%.
- ups.status is now built exactly the way NUT's own driver builds it, from
  NUT's per-make status tables, so it can report TRIM, BOOST, BYPASS and CAL
  as well as on mains, on battery, low battery, overload and replace battery.
  NUT's ups.alarm messages (for example "Replace battery!") and
  input.transfer.reason are published too. A UPS whose table does not give
  its power state keeps the board's previous status logic.
- UPSes that present more than one USB HID interface are now found on the
  right one. Some (the Liebert PSI5, for one) put a different device first,
  and the board used to talk to that instead of the UPS.
- NUT clients now get each value the way NUT itself reads it for your make of
  UPS, where the two differ: for example dates as 2014/02/21.
- A battery voltage far from the battery's own rated voltage (under half, or
  over 1.6 times) is dropped rather than published.

## v0.14.2 -- 2026-09-30

- Many more readings from your UPS, over NUT and on the page ("More from
  this UPS"). The board now uses the same per-make tables NUT itself uses, and
  publishes everything your UPS actually reports: nominal voltages and power,
  battery type and dates, low-battery and runtime warnings, transfer
  thresholds, timers, and on Eaton units efficiency, energy saving and outlet
  status. An APC Back-UPS now gives 27 variables to a NUT client, up from 21.
  Checked against 2,952 values NUT itself decoded from 48 real UPSes: every one
  matches.
- Fixed: on APC UPSes, battery.mfr.date showed the UPS's own manufacture date,
  not the battery's, and "set battery date" wrote over the UPS's date.
- Fixed: 32-bit timers that mean "no countdown" (-1) showed as 4294967295 on
  some Eaton, APC Smart-UPS and PowerWalker units.
- Values no working UPS reports (a 41216 V output, a 120% charge) are dropped
  rather than published.
- The Liebert GXT5 now reports runtime and on-mains/on-battery status. Its
  USB description switches usage tables mid-way, and the board read a status
  flag as the UPS's power rating. The board now follows the same rule as NUT.

## v0.14.1 -- 2026-09-30

- Fixed: on CyberPower UPSes, "turn the load off" with a delay waited 60 times
  too long. The page's default of 60 seconds meant an hour. These UPSes count
  the delay in minutes, and the board now converts it, rounding up so the
  outlets never go off sooner than asked. Readings are unaffected: in 65 real
  UPS descriptors, only the shutdown and startup delays use this conversion.

## v0.14 -- 2026-09-30

- Many more UPSes can now be read, including every Eaton tested, APC
  Smart-UPS models on USB ID 051d:0003 (Smart-UPS, SRT, Smart-UPS C),
  several CyberPower CP, OR and PR models, PowerWalker, IBM and Salicru.
  These UPSes mark their readings as fixed values in their USB description,
  and the board wrongly skipped them as padding, so it found no charge,
  runtime or status. Checked against 65 real UPS descriptors published on the
  NUT project's issue tracker: 55 now give charge, runtime and status, up
  from 29. Most of the rest are UPSes that do not speak USB HID at all.

## v0.13 -- 2026-09-30

- A UPS that keeps crashing the board can no longer knock it off the network.
  After three restarts in a row caused by the UPS, the board still identifies
  it but stops reading it; after five, it turns USB off. Either way it stays
  online, can be updated, and says so on its page, with a Try again button.
- When the board has no UPS readings (none attached, not read yet, or one it
  cannot read), NUT now answers "data stale", as a real NUT driver does,
  instead of reporting the UPS as OFF. Some NUT clients treat a UPS that stays
  OFF as critical and could shut a computer down.
- UPSes whose USB descriptor uses no report IDs can now be read. Before, the
  board rejected almost every reply from them and waited for a status forever.
- Values that sit past the 32nd byte of a report are now read, up to 63.
- A UPS the board has nothing to read from is no longer power-cycled over and
  over as if it had stopped answering.

## v0.12 -- 2026-09-30

- Fixed: some UPSes, including the APC Back-UPS BE600M1, made the board
  restart every couple of seconds and drop off the network as soon as they
  were plugged in. They answer a request with more data than was asked for,
  and the board now makes room for that instead of crashing. A board already
  stuck this way cannot update itself while the UPS is connected: unplug the
  UPS's USB cable, let the board update, then plug it back in.
- A UPS the board can't read now gets fixed faster. If a UPS is attached but
  gives no readings for five minutes, and the check-in is on, the board sends
  that UPS's USB report descriptor, make, model and USB ID to the project once.
  No readings, no serial number, nothing about your network.
- A "send my UPS info to the developer" button on the page sends the same
  thing on request, even with the check-in off.

## v0.11 -- 2026-09-29

- A real firmware target for a Rev A board with a VCC-first OLED module
  fitted (`reva-oled`), released alongside the plain build. Previously this
  needed a hand-built bench flag; now it is a normal board choice with its
  own OTA identity, so a board flashed with it can update itself instead of
  needing a cable every time. A plain Rev A board can never be offered it.

## v0.10 -- 2026-09-28

- A login is now required for every change, web and NUT. Set during Wi-Fi
  setup, or on the page's Login card if updating from an older version.
  Every write needs it: UPS commands, Wi-Fi, updates, reboot, and NUT's
  INSTCMD and SET VAR. Watching the UPS never does.
- A fixed IPv4 address, in Wi-Fi setup or a new Address card, for a NAS or
  Home Assistant pointed at the board's IP. Checked before it's saved: the
  router has to answer a ping from it.
- The page now warns when a UPS's "deep test" isn't a real one. Some models
  just rerun their short test; the page says so and shows the real duration
  for ones that do run a long one.
- Fixed a crash: a UPS control request that took over a second could free
  memory the USB stack still held, crashing the board later on an unrelated
  allocation.
- The page ran stale against new firmware if a tab was left open across an
  update. It now reloads itself when the firmware version changes, and is
  never cached.
- Failures on the page all read as one generic message. Now: "can't reach
  the board" versus a reply it can't parse versus a locked-out login, each
  said plainly.
- Fixed a false OFF over NUT: some UPSes read back all-zero status flags for
  a minute or two after a self-test, which used to map straight to OFF.
- A UPS's report cache has been seen to wedge shortly after a test starts.
  The board now power-cycles the USB link and re-reads right after a test
  command.
- Fixed a status-page header that shifted every second as its text changed
  length.

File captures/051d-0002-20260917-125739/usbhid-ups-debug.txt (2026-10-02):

Network UPS Tools 2.8.4 release - Generic HID driver 0.67
USB communication driver (libusb 1.0) 0.50
   0.000000	[D1] upsdrv_makevartable...
   0.000022	[D1] Using USB implementation: libusb-1.0.30 (API: 0x0100010B)
   0.000028	[D3] main_arg: var='vendorid' val='051d'
   0.000034	[D3] main_arg: var='productid' val='0002'
   0.000039	[D1] Network UPS Tools version 2.8.4 release, 64-bit build for aarch64, built with Apple clang version 17.0.0 (clang-1700.0.13.3); Target: arm64-apple-darwin24.4.0; Thread model: posix and configured with flags: --disable-dependency-tracking --prefix=/opt/homebrew/Cellar/nut/2.8.4 --localstatedir=/opt/homebrew/var --sysconfdir=/opt/homebrew/etc/nut --with-statepath=/opt/homebrew/var/state/ups --with-pidpath=/opt/homebrew/var/run --with-systemdtmpfilesdir=/opt/homebrew/Cellar/nut/2.8.4/share/nut --with-openssl --with-serial --with-usb --without-avahi --without-cgi --without-dev --without-doc --without-ipmi --without-libltdl --without-neon --without-nss --without-nut_monitor --without-powerman --without-pynut --without-snmp --without-wrap --with-macosx_ups
   0.000044	Error: you must specify a port name in ups.conf or in '-x port=...' argument.
Try -h for help.
   0.000051	[D1] upsnotify: failed to notify about state NOTIFY_STATE_STOPPING: no notification tech defined, will not spam more about it

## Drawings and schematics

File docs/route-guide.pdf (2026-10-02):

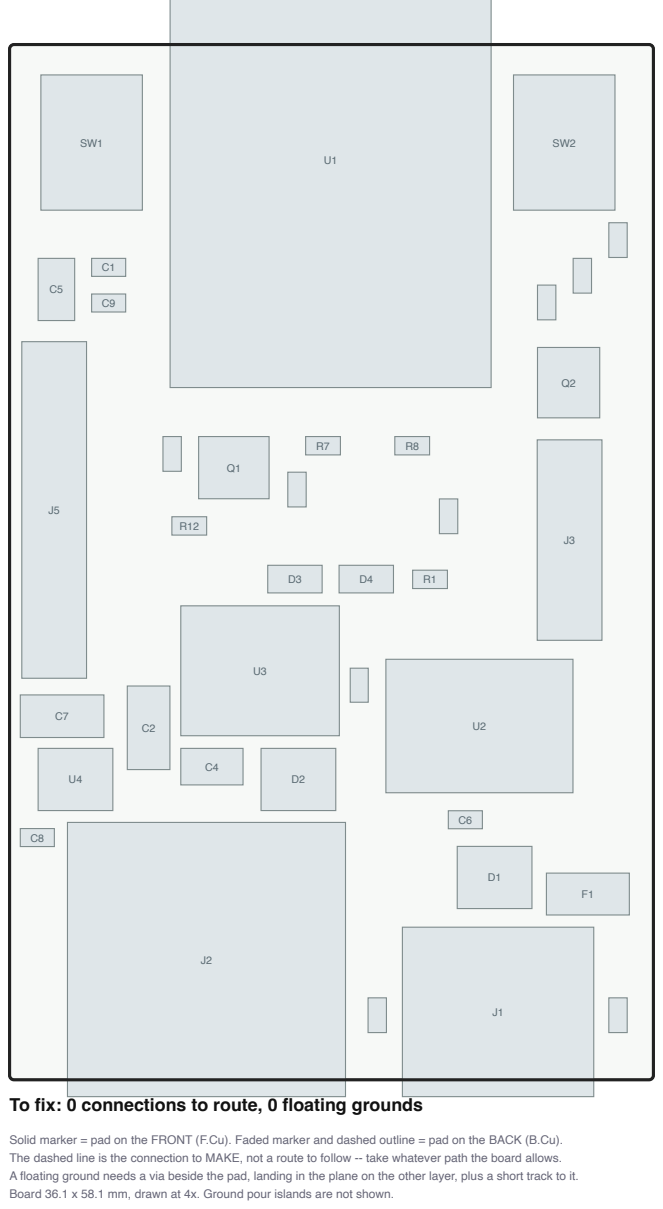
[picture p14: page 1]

To fix: 0 connections to route, 0 floating grounds

Solid marker = pad on the FRONT (F.Cu). Faded marker and dashed outline = pad on the BACK (B.Cu).
The dashed line is the connection to MAKE, not a route to follow -- take whatever path the board allows.
A floating ground needs a via beside the pad, landing in the plane on the other layer, plus a short track to it.
Board 36.1 x 58.1 mm, drawn at 4x. Ground pour islands are not shown.

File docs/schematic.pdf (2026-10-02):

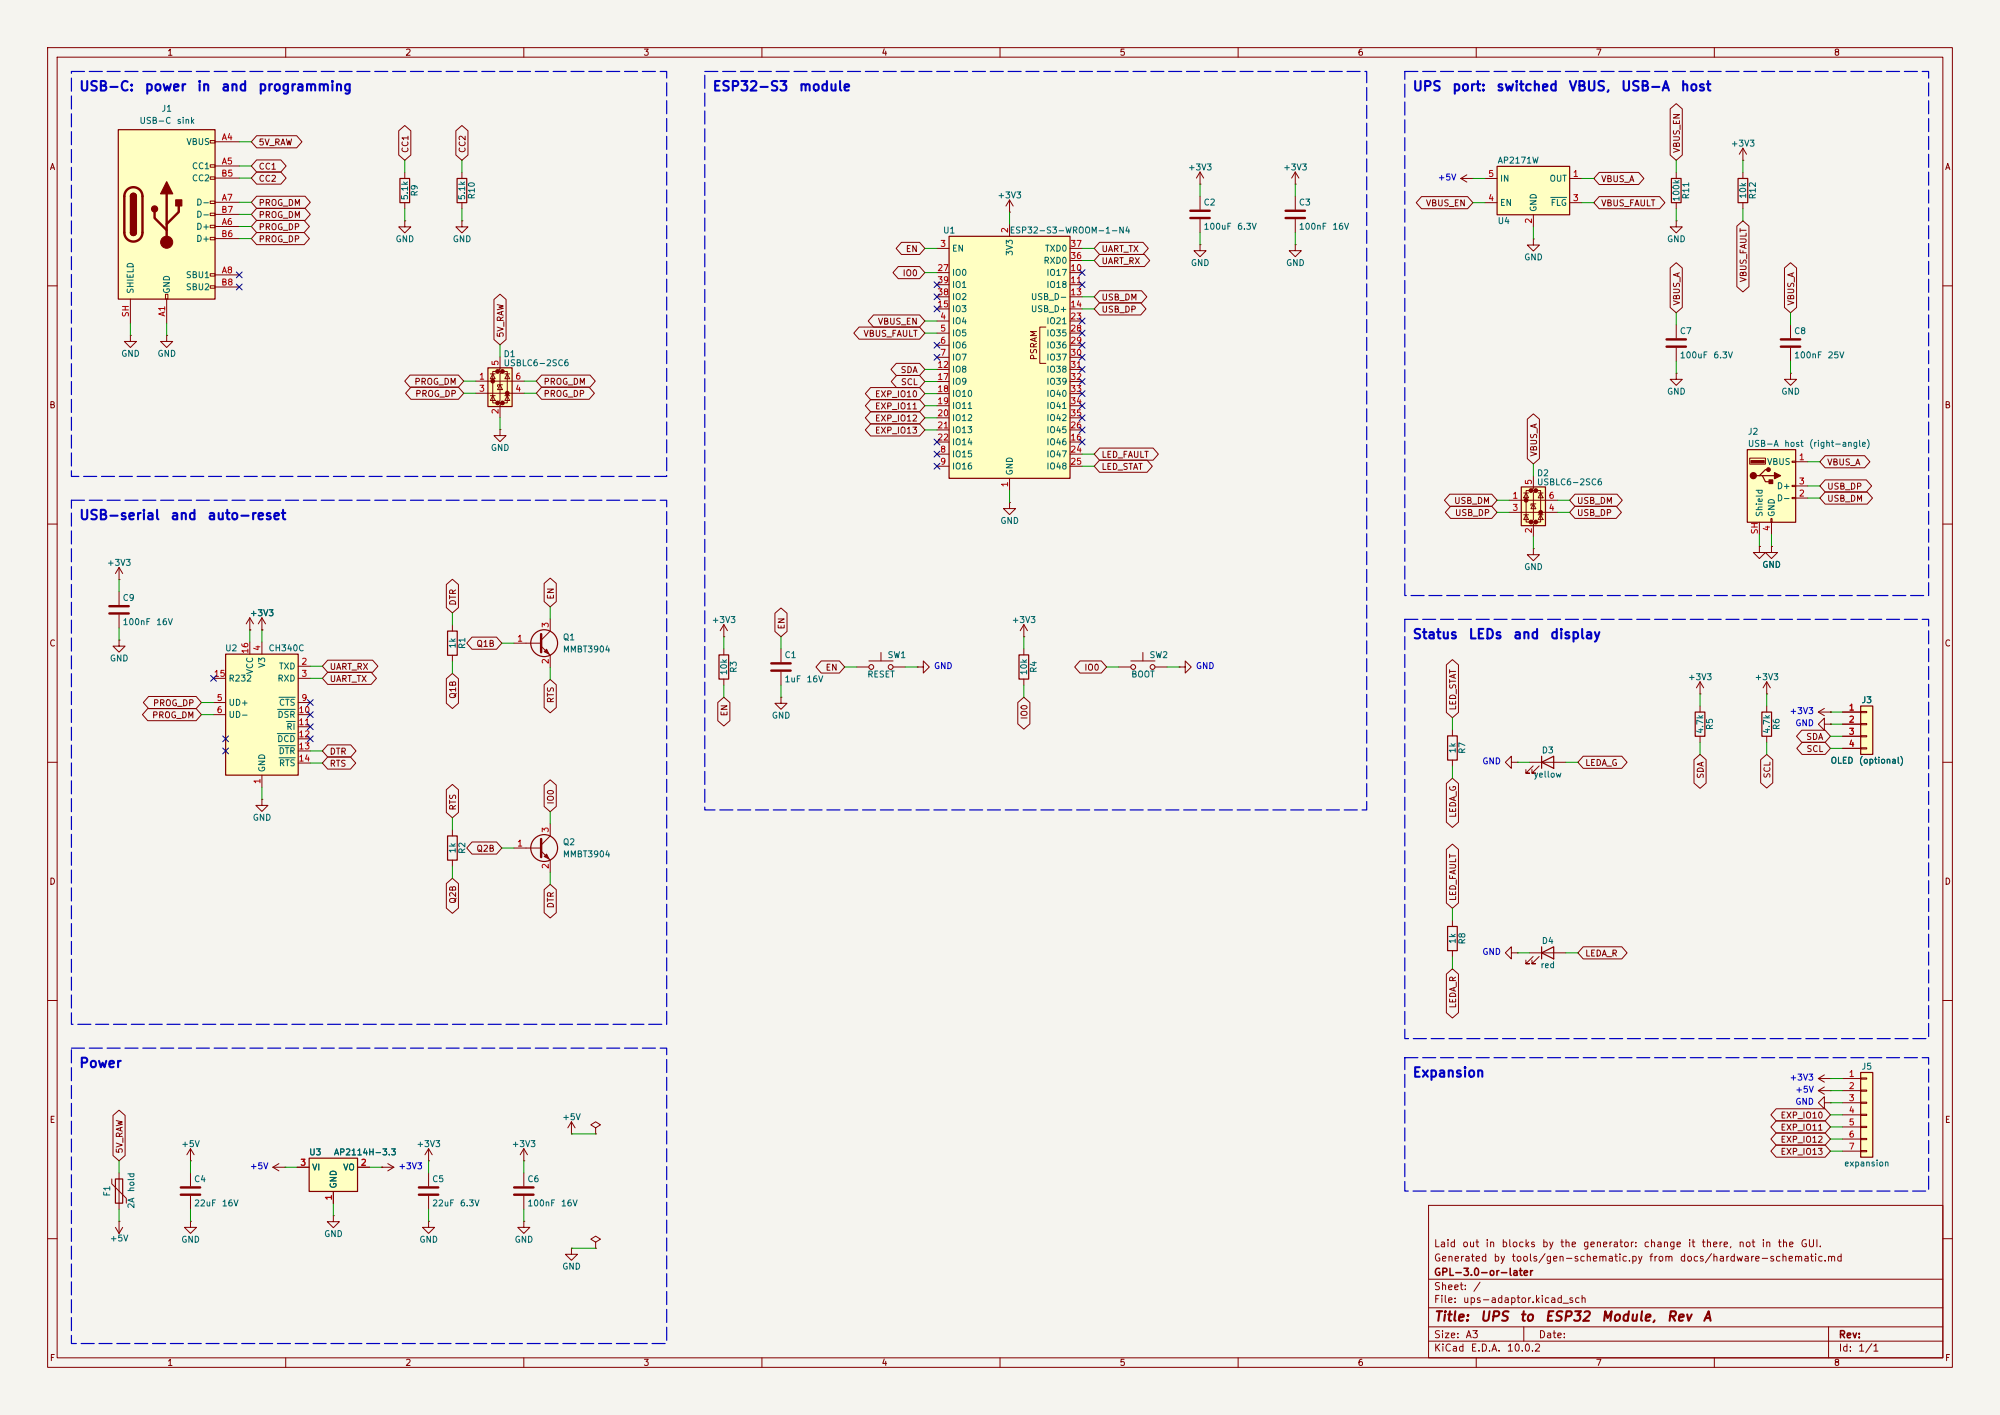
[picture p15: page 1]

USB-C: power in and programming

UPS port: switched VBUS, USB-A host +5V

4 UD+ 5 UD- 6 CTS 9 DSR 10 RI 11 DCD 12 DTR 13 RTS 14 R232 15 VCC U2 16CH340C 10k R12

GND +5V USB-serial and auto-reset

Laid out in blocks by the generator: change it there, not in the GUI. +5V

Generated by tools/gen-schematic.py from docs/hardware-schematic.md
GPL-3.0-or-later
Sheet: /
File: ups-adaptor.kicad_sch
Title: UPS to ESP32 Module, Rev A

GND

Size: A3 | Rev:
KiCad E.D.A. 10.0.2 | Id: 1/1 | F Date:

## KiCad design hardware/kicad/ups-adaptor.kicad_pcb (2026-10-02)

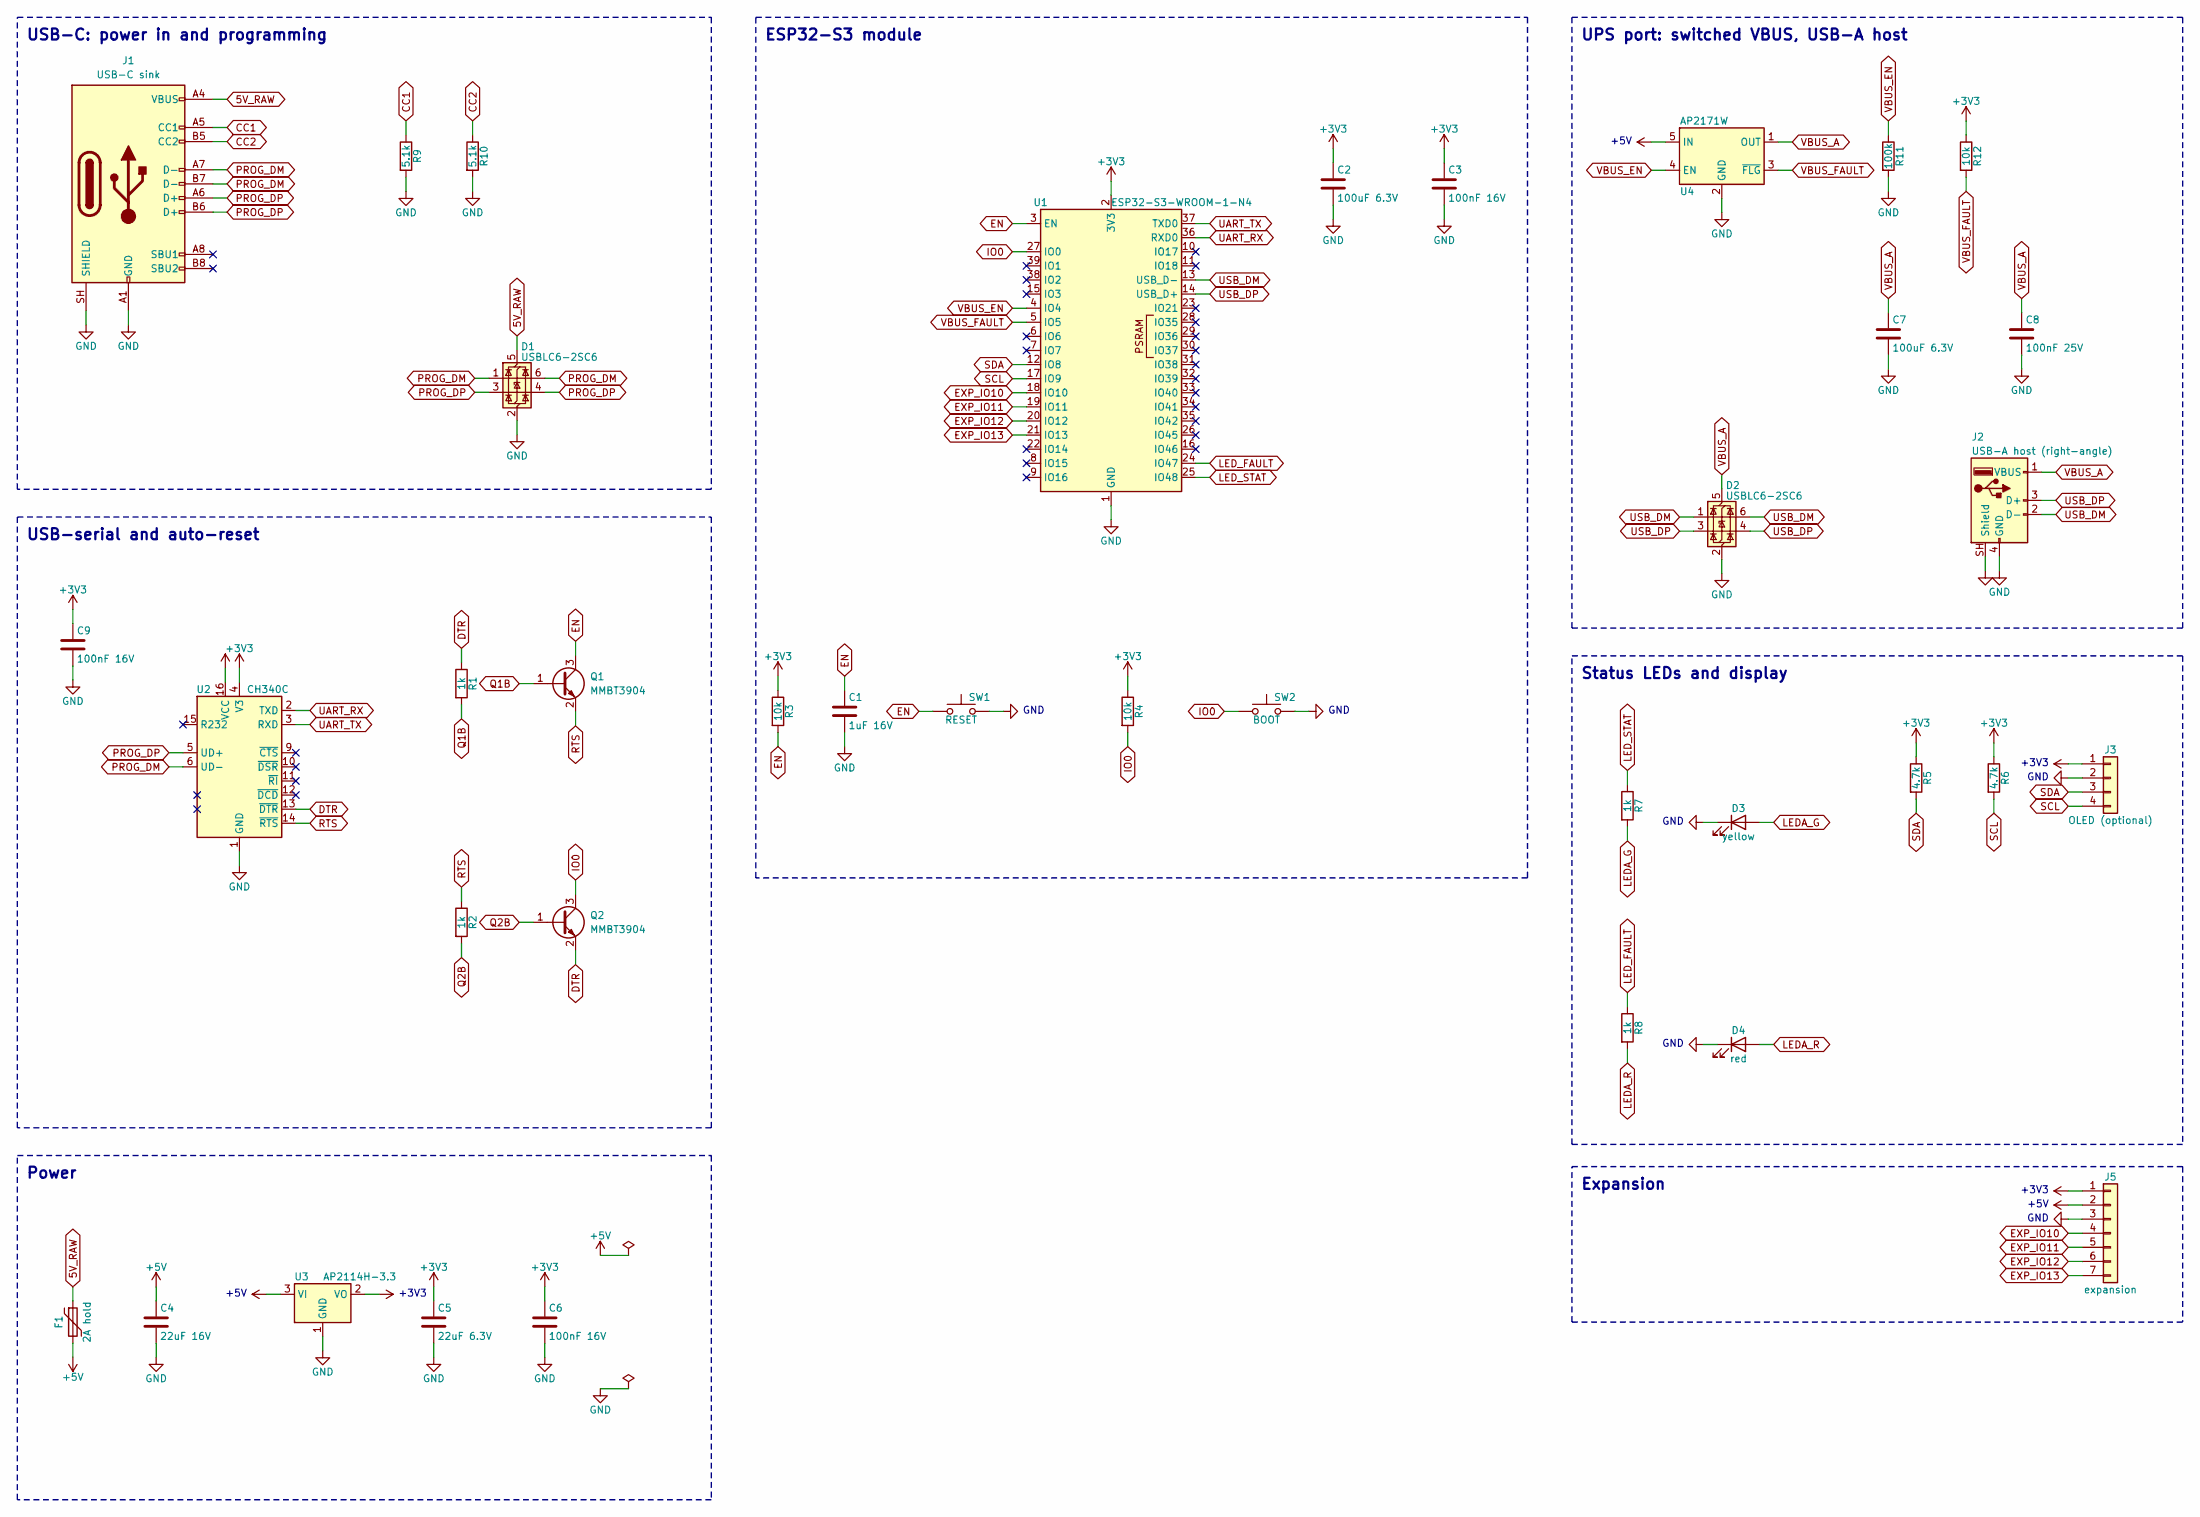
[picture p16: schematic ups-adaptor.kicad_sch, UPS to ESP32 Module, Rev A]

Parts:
C1: 1uF 16V; C_0402_1005Metric
C2, C7: 100uF 6.3V; C_1206_3216Metric
C3, C6, C9: 100nF 16V; C_0402_1005Metric
C4: 22uF 16V; C_0805_2012Metric
C5: 22uF 6.3V; C_0805_2012Metric
C8: 100nF 25V; C_0402_1005Metric
D1, D2: USBLC6-2SC6; SOT-23-6
D3: yellow; LED_0603_1608Metric
D4: red; LED_0603_1608Metric
F1: 2A hold; Fuse_1206_3216Metric
J1: USB-C sink; USB_C_Receptacle_HRO_TYPE-C-31-M-12
J2: USB-A host (right-angle); USB_A_Receptacle_XKB_U231-091N-4BLRA00-S
J3: OLED (optional); PinSocket_1x04_P2.54mm_Vertical
J5: expansion; PinHeader_1x07_P2.54mm_Vertical
Q1, Q2: MMBT3904; SOT-23
R1, R2, R7, R8: 1k; R_0402_1005Metric
R3, R4, R12: 10k; R_0402_1005Metric
R5, R6: 4.7k; R_0402_1005Metric
R9, R10: 5.1k; R_0402_1005Metric
R11: 100k; R_0402_1005Metric
SW1: RESET; SW_Push_1P1T_XKB_TS-1187A
SW2: BOOT; SW_Push_1P1T_XKB_TS-1187A
U1: ESP32-S3-WROOM-1-N4; ESP32-S3-WROOM-1
U2: CH340C; SOIC-16_3.9x9.9mm_P1.27mm
U3: AP2114H-3.3; SOT-223-3_TabPin2
U4: AP2171W; SOT-23-5

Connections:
5V_RAW: D1.5 (VBUS), F1.1, J1.A4 (VBUS), J1.A9 (VBUS), J1.B4 (VBUS), J1.B9 (VBUS)
+3V3: C2.1, C3.1, C5.1, C6.1, C9.1, J3.1, J5.1, R3.1, R4.1, R5.1, R6.1, R12.1, U1.2 (3V3), U2.4 (V3), U2.16 (VCC), U3.2 (VO)
+5V: C4.1, F1.2, J5.2, U3.3 (VI), U4.5 (IN)
CC1: J1.A5 (CC1), R9.1
CC2: J1.B5 (CC2), R10.1
DTR: Q2.2 (E), R1.1, U2.13 (~DTR)
EN: C1.1, Q1.3 (C), R3.2, SW1.1, U1.3 (EN)
EXP_IO10: J5.4, U1.18 (IO10)
EXP_IO11: J5.5, U1.19 (IO11)
EXP_IO12: J5.6, U1.20 (IO12)
EXP_IO13: J5.7, U1.21 (IO13)
GND: C1.2, C2.2, C3.2, C4.2, C5.2, C6.2, C7.2, C8.2, C9.2, D1.2 (GND), D2.2 (GND), D3.1 (K), D4.1 (K), J1.A1 (GND), J1.A12 (GND), J1.B1 (GND), J1.B12 (GND), J1.SH (SHIELD), J2.4 (GND), J2.SH (Shield), J3.2, J5.3, R9.2, R10.2, R11.2, SW1.2, SW2.2, U1.1 (GND), U1.40 (GND), U1.41 (GND), U2.1 (GND), U3.1 (GND), U4.2 (GND)
IO0: Q2.3 (C), R4.2, SW2.1, U1.27 (IO0)
LEDA_G: D3.2 (A), R7.2
LEDA_R: D4.2 (A), R8.2
LED_FAULT: R8.1, U1.24 (IO47)
LED_STAT: R7.1, U1.25 (IO48)
PROG_DM: D1.1 (I/O1), D1.6 (I/O1), J1.A7 (D-), J1.B7 (D-), U2.6 (UD-)
PROG_DP: D1.3 (I/O2), D1.4 (I/O2), J1.A6 (D+), J1.B6 (D+), U2.5 (UD+)
Q1B: Q1.1 (B), R1.2
Q2B: Q2.1 (B), R2.2
RTS: Q1.2 (E), R2.1, U2.14 (~RTS)
SCL: J3.4, R6.2, U1.17 (IO9)
SDA: J3.3, R5.2, U1.12 (IO8)
UART_RX: U1.36 (RXD0), U2.2 (TXD)
UART_TX: U1.37 (TXD0), U2.3 (RXD)
USB_DM: D2.1 (I/O1), D2.6 (I/O1), J2.2 (D-), U1.13 (USB_D-)
USB_DP: D2.3 (I/O2), D2.4 (I/O2), J2.3 (D+), U1.14 (USB_D+)
VBUS_A: C7.1, C8.1, D2.5 (VBUS), J2.1 (VBUS), U4.1 (OUT)
VBUS_EN: R11.1, U1.4 (IO4), U4.4 (EN)
VBUS_FAULT: R12.2, U1.5 (IO5), U4.3 (~FLG)

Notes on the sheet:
+3V3
+5V
GND
USB-C: power in and programming
USB-serial and auto-reset
Power
ESP32-S3 module
UPS port: switched VBUS, USB-A host
Status LEDs and display
Expansion

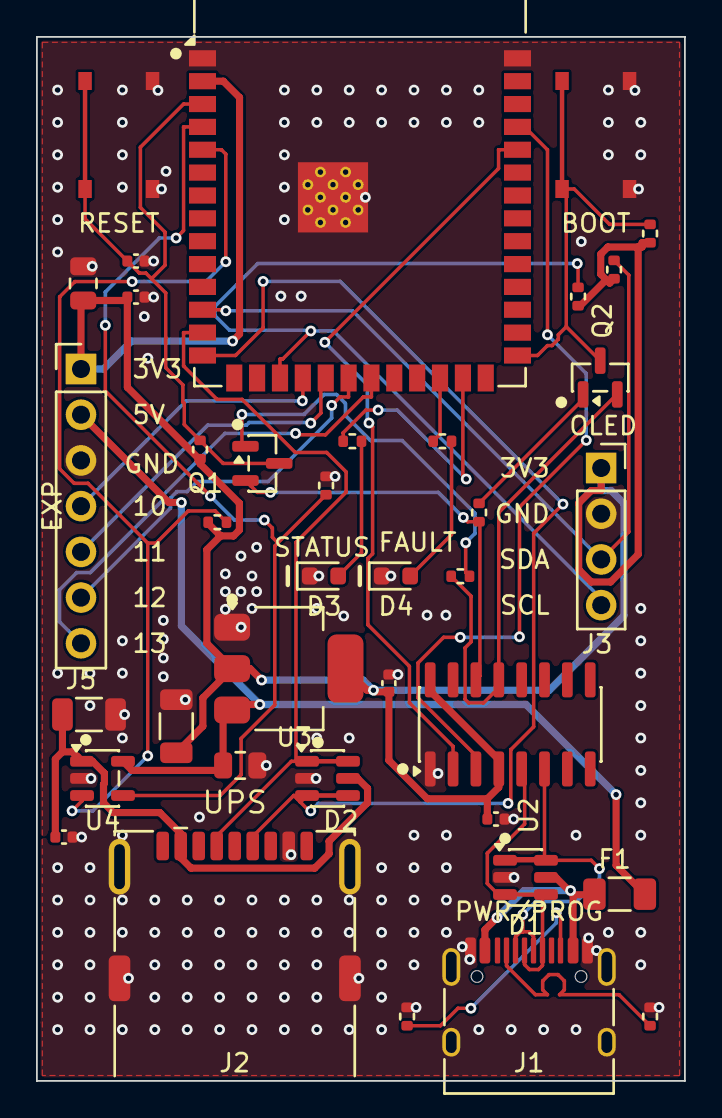
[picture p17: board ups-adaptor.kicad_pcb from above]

Board: 2 copper layers, 36.0 x 58.0 mm, 38 parts (0 on the bottom side), 31 nets.

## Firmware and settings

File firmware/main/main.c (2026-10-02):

/* SPDX-License-Identifier: GPL-3.0-or-later
 *
 * UPS to ESP32 Module: bridges a USB-only UPS to Wi-Fi as a NUT server.
 *
 * Startup order matters:
 *   board   -> GPIO sane, VBUS held off
 *   netmgr  -> Wi-Fi or provisioning AP
 *   webui   -> setup reachable even if the UPS never enumerates
 *   display -> optional OLED, so bring-up messages have somewhere to go
 *   ups_hid -> raises VBUS and starts polling
 *   nut     -> last, so it never serves a snapshot that was never populated
 */
#include <string.h>
#include "board.h"
#include "netmgr.h"
#include "ups_hid.h"
#include "nut_server.h"
#include "auth.h"
#include "webui.h"
#include "ota.h"
#include "display.h"
#include "fleet.h"
#include "crashlog.h"
#include "freertos/FreeRTOS.h"
#include "freertos/task.h"
#include "nvs_flash.h"
#include "esp_log.h"
#include "esp_heap_caps.h"
#include "esp_ota_ops.h"
#include "driver/uart.h"

static const char *TAG = "main";

/* Single place that maps device state onto the status LEDs. Runs in app_main's
 * own task once everything is started, so there is no extra stack for it. */
static void status_supervisor(void)
{
    /* An image installed over the air boots on trial and the bootloader reverts
     * it unless it says otherwise. Confirming in app_main instead would confirm
     * an image that panics a second later, so it happens here, from the loop
     * that is running once everything else is up.
     *
     * KEEP ASKING UNTIL IT TAKES. ota_confirm() refuses an image that has not
     * yet earned confirmation -- five minutes of uptime and three served HTTP
     * requests -- and the first opportunity to ask is seconds after boot. This
     * used to ask once and latch, so the gate refused it once and was never
     * asked again: v0.03 ran for eleven minutes still on trial, one power cut
     * away from silently downgrading itself. */
    bool confirmed = false;

    for (;;) {
        if (!confirmed) {
            confirmed = ota_confirm();
        }
        ups_data_t d;
        ups_hid_get(&d);

        board_status_t st;
        if (board_vbus_fault()) {
            st = BOARD_STATUS_FAULT;
        } else {
            switch (netmgr_state()) {
            case NETMGR_AP_PROVISIONING: st = BOARD_STATUS_PROVISIONING; break;
            case NETMGR_STA_CONNECTING:
            case NETMGR_STA_RETRYING:    st = BOARD_STATUS_CONNECTING;   break;
            case NETMGR_STA_CONNECTED:
                st = d.attached ? BOARD_STATUS_ONLINE : BOARD_STATUS_NO_UPS;
                break;
            default:                     st = BOARD_STATUS_BOOTING;      break;
            }
        }
        board_status_set(st);
        vTaskDelay(pdMS_TO_TICKS(500));
    }
}

/* Press BOOT five times within four seconds: clear Wi-Fi and the optional
 * login (both live in the "upsa" namespace netmgr_factory_reset erases), and
 * restart into setup. Forgetting the password costs a walk to the board.
 *
 * NOT "HOLD BOOT AT POWER-ON", which is what this used to be and cannot work:
 * BOOT is GPIO0, the S3's download-mode strap, so holding it while power comes
 * up starts the ROM flasher and this firmware never runs to see it. A board
 * given the wrong network had no way back without a serial cable.
 *
 * AND NOT "HOLD FOR TEN SECONDS". On Rev A, GPIO0 is also driven by the
 * CH340C's auto-reset transistor: a serial terminal that raises DTR alone --
 * `screen` does -- holds GPIO0 low exactly as a held button does, and would
 * wipe the network of anyone watching the console. A serial line cannot tap
 * the pin five times, and an esptool reset restarts the chip, counter and all.
 *
 * Presses are counted on the debounced falling edge: a held-low line is one
 * press, whatever its length. */
#define FACTORY_PRESSES   5
#define FACTORY_WINDOW_MS 4000

static void factory_gesture_task(void *arg)
{
    bool stable = false, prev = false;
    int count = 0;
    TickType_t first = 0;
    for (;;) {
        vTaskDelay(pdMS_TO_TICKS(25));
        bool raw = board_factory_button_pressed();
        if (raw != prev) { prev = raw; continue; }   /* same reading twice */
        if (raw == stable) continue;
        stable = raw;
        if (!stable) continue;                        /* presses, not releases */

        TickType_t now = xTaskGetTickCount();
        if (count == 0 || now - first > pdMS_TO_TICKS(FACTORY_WINDOW_MS)) {
            count = 0;
            first = now;
        }
        if (++count >= 2) {
            ESP_LOGI(TAG, "BOOT pressed %d of %d for a Wi-Fi and login reset", count, FACTORY_PRESSES);
        }
        if (count >= FACTORY_PRESSES) {
            ESP_LOGW(TAG, "BOOT pressed %d times: clearing Wi-Fi and login, restarting into setup",
                     FACTORY_PRESSES);
            netmgr_factory_reset();                   /* restarts */
        }
    }
}

/* Type "clear-login" into the USB-C serial console (115200) to remove the
 * login and nothing else: Wi-Fi, address and settings stay, and the page asks
 * for a new login. The same trust as the BOOT gesture -- someone with the
 * board's cable in hand -- without opening a case or losing the network,
 * which is what a forgotten password on a board in a closet otherwise costs.
 * A whole line must match, so log noise or a terminal's echo cannot trip it. */
static void serial_cmd_task(void *arg)
{
    const uart_port_t port = CONFIG_ESP_CONSOLE_UART_NUM;
    if (uart_driver_install(port, 256, 0, 0, NULL, 0) != ESP_OK) vTaskDelete(NULL);
    char line[32];
    size_t n = 0;
    for (;;) {
        uint8_t c;
        if (uart_read_bytes(port, &c, 1, portMAX_DELAY) != 1) continue;
        if (c != '\r' && c != '\n') {
            if (n < sizeof(line) - 1) line[n++] = (char)c;
            else n = sizeof(line);                    /* too long: never matches */
            continue;
        }
        if (n < sizeof(line)) {
            line[n] = 0;
            if (strcmp(line, "clear-login") == 0) {
                esp_err_t err = auth_set_credentials(NULL, NULL);
                ESP_LOGW(TAG, "serial: login %s", err == ESP_OK ? "cleared; set a new one on the web page"
                                                                 : esp_err_to_name(err));
            } else if (n) {
                ESP_LOGI(TAG, "serial: unknown command (try clear-login)");
            }
        }
        n = 0;
    }
}

#if CONFIG_UPSA_MEM_DIAG
/* Heap and stacks, measured. Stack is reported as bytes NEVER used, so a task
 * sized with a small figure here is the one to look at, and a large one is
 * memory given back by shrinking its stack. */
static void mem_diag_task(void *arg)
{
    static TaskStatus_t st[24];
    for (;;) {
        vTaskDelay(pdMS_TO_TICKS(10000));
        ESP_LOGI("memdiag", "heap internal free %u, lowest %u, largest block %u",
                 (unsigned)heap_caps_get_free_size(MALLOC_CAP_INTERNAL),
                 (unsigned)heap_caps_get_minimum_free_size(MALLOC_CAP_INTERNAL),
                 (unsigned)heap_caps_get_largest_free_block(MALLOC_CAP_INTERNAL));
        UBaseType_t n = uxTaskGetSystemState(st, sizeof(st) / sizeof(st[0]), NULL);
        for (UBaseType_t i = 0; i < n; i++) {
            ESP_LOGI("memdiag", "  stack unused %5u  %s",
                     (unsigned)st[i].usStackHighWaterMark, st[i].pcTaskName);
        }
    }
}
#endif

#if CONFIG_UPSA_CRASH_TEST
/* See Kconfig UPSA_CRASH_TEST. Not static and not inlined, so the recorded
 * backtrace names it. */
void __attribute__((noinline)) crash_test_spin(void)
{
    portDISABLE_INTERRUPTS();
    for (volatile uint32_t i = 0; ; i++) { }
}

static void crash_test_task(void *arg)
{
    vTaskDelay(pdMS_TO_TICKS(60 * 1000));
    ESP_LOGE(TAG, "CRASH TEST: spinning with interrupts off");
    crash_test_spin();
}
#endif

/* A start-up step that failed. On an image still on trial, abort: the
 * bootloader then rolls back to the last good one, which is the point of the
 * trial. On a confirmed image an abort only restarts into the same failure,
 * for ever, and a board in a closet stuck in that loop cannot even fetch the
 * update that would fix it. So log it and carry on with what does work. */
static void start_failed(const char *what, esp_err_t err)
{
    ESP_LOGE(TAG, "%s did not start: %s", what, esp_err_to_name(err));
    esp_ota_img_states_t st;
    const esp_partition_t *run = esp_ota_get_running_partition();
    if (run && esp_ota_get_state_partition(run, &st) == ESP_OK &&
        st == ESP_OTA_IMG_PENDING_VERIFY) {
        ESP_LOGE(TAG, "this image is on trial: restarting so it rolls back");
        abort();
    }
}

void app_main(void)
{
    esp_err_t err = nvs_flash_init();
    if (err == ESP_ERR_NVS_NO_FREE_PAGES || err == ESP_ERR_NVS_NEW_VERSION_FOUND) {
        ESP_ERROR_CHECK(nvs_flash_erase());
        err = nvs_flash_init();
    }
    ESP_ERROR_CHECK(err);
    /* First, before anything can crash again: what the last crash left. */
    crashlog_init();
    /* Before the web and NUT servers, which ask it on every write. */
    ESP_ERROR_CHECK(auth_init());

    ESP_ERROR_CHECK(board_init());
    board_status_set(BOARD_STATUS_BOOTING);

    /* No-ops unless CONFIG_UPSA_HAVE_OLED, and tolerant of an absent module. */
    ESP_ERROR_CHECK(display_init());
    display_line(0, "BOOTING");

    ESP_ERROR_CHECK(netmgr_start());
    ESP_ERROR_CHECK(webui_start());
    ESP_ERROR_CHECK(display_start());
    /* The rest of the board is still worth having without any one of these:
     * no UPS reading still leaves the page and updates, and no NUT server
     * still leaves the page. ota_start() most of all, as the way out. */
    if ((err = ups_hid_start()) != ESP_OK) start_failed("USB host", err);
    if ((err = nut_server_start(NUT_DEFAULT_PORT)) != ESP_OK) start_failed("NUT server", err);
    ota_set_quiet_hook(ups_hid_quiet);   /* no UPS USB traffic while an update writes */
    if ((err = ota_start()) != ESP_OK) start_failed("updates", err);
    /* NOT ESP_ERROR_CHECK. The heartbeat is an extra; a board that cannot
     * start it must still serve NUT, not boot-loop. */
    if (fleet_start() != ESP_OK) ESP_LOGE(TAG, "fleet heartbeat did not start");

    xTaskCreate(factory_gesture_task, "factory_btn", 2560, NULL, 2, NULL);
    xTaskCreate(serial_cmd_task, "serial_cmd", 2560, NULL, 1, NULL);
#if CONFIG_UPSA_CRASH_TEST
    xTaskCreate(crash_test_task, "crashtest", 2048, NULL, 1, NULL);
#endif
#if CONFIG_UPSA_MEM_DIAG
    xTaskCreate(mem_diag_task, "memdiag", 3072, NULL, 1, NULL);
#endif

    ESP_LOGI(TAG, "%s up", BOARD_NAME);

    status_supervisor();   /* never returns */
}

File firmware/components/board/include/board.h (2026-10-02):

/* SPDX-License-Identifier: GPL-3.0-or-later
 *
 * Board abstraction for the UPS to ESP32 Module.
 *
 * Rev A is the only board that is made. Firmware was brought up on a Freenove
 * devkit before Rev A existed; that target has been removed. Rev A OLED is a
 * second firmware IDENTITY on the same PCB, for a VCC-first display module;
 * it is not a second board.
 *
 * Every pin the application touches is named here. Application code must not
 * contain GPIO numbers, so that a future board is a new block below and
 * nothing else.
 *
 * GPIO19/20 (USB D-/D+) are deliberately absent. They are fixed by silicon and
 * are owned by the usb_host peripheral, not by us.
 */
#ifndef UPSA_BOARD_H
#define UPSA_BOARD_H

#include <stdbool.h>
#include "driver/gpio.h"
#include "esp_err.h"
#include "esp_mac.h"
#include "sdkconfig.h"

#if defined(CONFIG_UPSA_BOARD_REV_A)

#define BOARD_NAME              "UPS to ESP32 Module Rev A"
/* Picks the OTA asset: ups-adaptor-reva.bin. The two targets have different
 * pin maps, so installing the wrong one is not a cosmetic mistake. */
#define BOARD_OTA_TARGET        "reva"
/* What an image built FOR THIS BOARD calls itself in its app descriptor. The
 * OTA client refuses anything else, so a mislabelled asset cannot be
 * installed -- which has happened. */
#define BOARD_IMAGE_NAME        "ups-adaptor-reva"
/* Rev A: see docs/hardware.md pin assignment table. */
#define BOARD_PIN_VBUS_EN       GPIO_NUM_4   /* AP2171W EN, active high        */
/* Rev A uses an AP2171W: a SOT-23-5 load switch fits EN plus exactly one of
 * ILIM or FLAG, and this part chose FLAG. So fault reporting is back and the
 * current limit is fixed by the part rather than set by a resistor.
 * See docs/hardware-schematic.md section 1. */
#define BOARD_PIN_VBUS_FAULT    GPIO_NUM_5   /* AP2171W FLG, open drain, active low */
#define BOARD_PIN_LED_STATUS    GPIO_NUM_48  /* green, plain LED, 1k series    */
#define BOARD_PIN_LED_FAULT     GPIO_NUM_47  /* red, plain LED, 1k series      */
#define BOARD_PIN_I2C_SDA       GPIO_NUM_8
#define BOARD_PIN_I2C_SCL       GPIO_NUM_9
#define BOARD_PIN_FACTORY_BTN   GPIO_NUM_0   /* BOOT button, doubles as reset  */
#define BOARD_HAS_VBUS_SWITCH   1
#define BOARD_HAS_VBUS_FAULT    1
#define BOARD_HAS_STATUS_LEDS   1
/* A display on plain Rev A only with a VCC-first module; Kconfig hides every
 * other way, and this catches an edit to it. */
#if defined(CONFIG_UPSA_HAVE_OLED) && !defined(CONFIG_UPSA_REVA_OLED_VCC_FIRST)
#error "No OLED on plain Rev A except a VCC-first module: J3 powers a standard one backwards (use the reva-oled board target)"
#endif

#elif defined(CONFIG_UPSA_BOARD_REVA_OLED)

#define BOARD_NAME              "UPS to ESP32 Module Rev A (OLED)"
/* Same PCB and pin map as plain Rev A -- a second firmware IDENTITY, not a
 * second board. That is what makes it safe to hand to someone else: the OTA
 * client's own-board check keeps a plain Rev A board from ever being offered
 * a build that assumes a VCC-first display is fitted, and keeps a board
 * already running this build from being offered a plain Rev A release that
 * would leave its screen dark without saying why. */
#define BOARD_OTA_TARGET        "reva-oled"
#define BOARD_IMAGE_NAME        "ups-adaptor-reva-oled"
#define BOARD_PIN_VBUS_EN       GPIO_NUM_4   /* AP2171W EN, active high        */
#define BOARD_PIN_VBUS_FAULT    GPIO_NUM_5   /* AP2171W FLG, open drain, active low */
#define BOARD_PIN_LED_STATUS    GPIO_NUM_48  /* green, plain LED, 1k series    */
#define BOARD_PIN_LED_FAULT     GPIO_NUM_47  /* red, plain LED, 1k series      */
#define BOARD_PIN_I2C_SDA       GPIO_NUM_8
#define BOARD_PIN_I2C_SCL       GPIO_NUM_9
#define BOARD_PIN_FACTORY_BTN   GPIO_NUM_0   /* BOOT button, doubles as reset  */
#define BOARD_HAS_VBUS_SWITCH   1
#define BOARD_HAS_VBUS_FAULT    1
#define BOARD_HAS_STATUS_LEDS   1
/* This target exists FOR a VCC-first module: Kconfig ties the two together
 * (UPSA_BOARD_REVA_OLED selects UPSA_REVA_OLED_VCC_FIRST), so this catches an
 * edit that lets them drift apart rather than a module that was never fitted. */
#if !defined(CONFIG_UPSA_REVA_OLED_VCC_FIRST)
#error "UPSA_BOARD_REVA_OLED without UPSA_REVA_OLED_VCC_FIRST: Kconfig should have set both together"
#endif

#elif defined(CONFIG_UPSA_BOARD_P4_POE)
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

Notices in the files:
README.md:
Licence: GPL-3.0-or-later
